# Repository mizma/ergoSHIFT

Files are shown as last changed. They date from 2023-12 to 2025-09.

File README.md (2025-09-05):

ergoSHIFT arcade controller
========================================================================



_**Low profile 11 button leverless arcade controller with Acrylic shell**_

This repository contains Acrylic cut design files, PCB design files and code needed to make
an arcade controller that look like this:

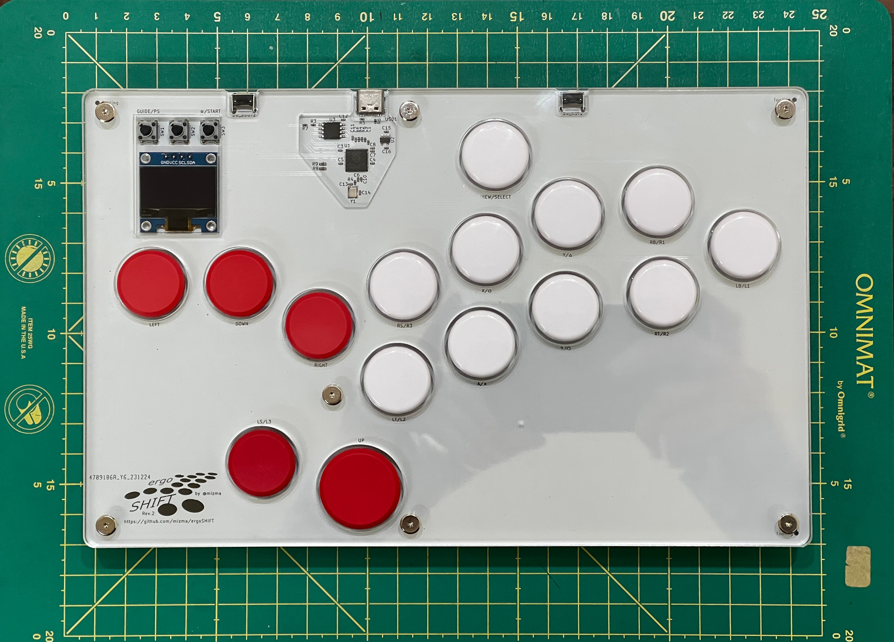
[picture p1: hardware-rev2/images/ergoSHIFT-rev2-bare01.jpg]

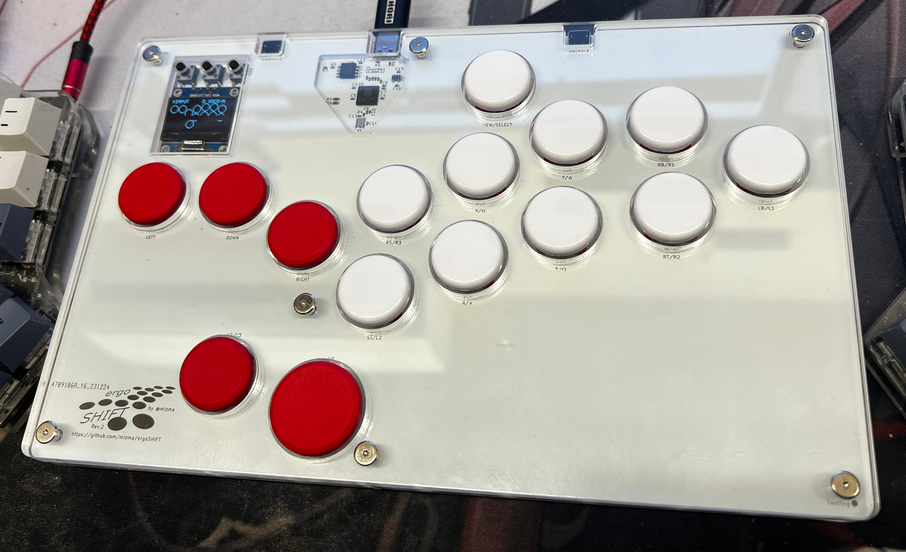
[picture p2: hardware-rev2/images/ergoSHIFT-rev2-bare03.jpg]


Also, you can create custom artwork using the stencil provided in each hardware revision folder.

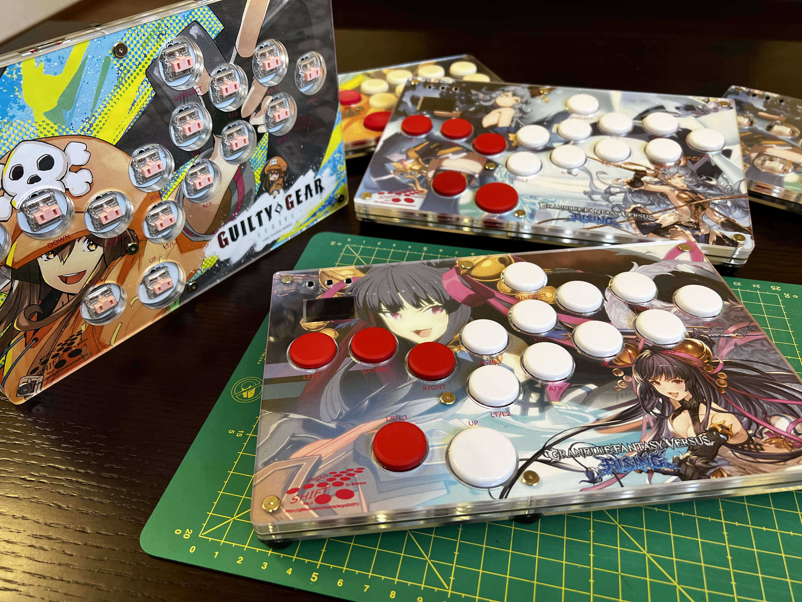
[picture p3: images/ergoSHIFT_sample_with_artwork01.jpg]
ergoSHIFT-rev1_with_artwork1

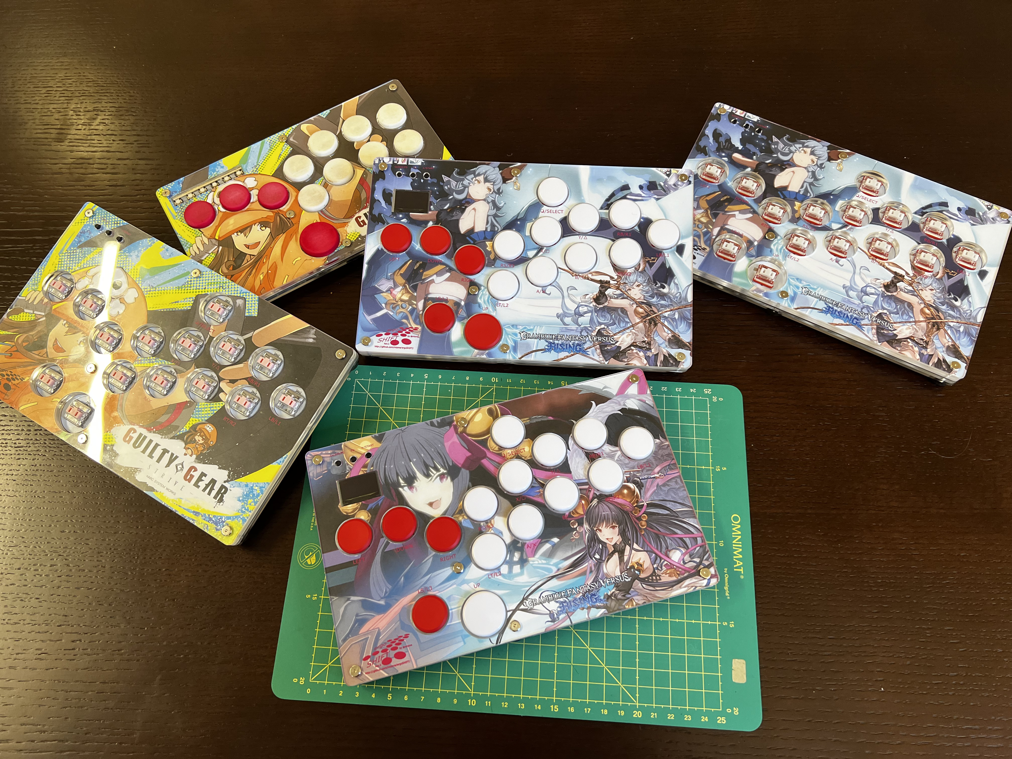
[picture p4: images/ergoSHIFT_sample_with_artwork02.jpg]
ergoSHIFT-rev1_with_artwork2


(*) Above sample Artwork based on an In-Game Screenshot + Official Fan-kit (©Cygames & ARK SYSTEM WORKS)

This controller is designed with the following concept:

* Create a reasonably compact and thin leverless arcade controller
* Layout 11 main buttons + 4 directional buttons to work with the latest
  Capcom Pro-Tour rule-set
* Shift the home position for the main button one column to the right to better utilize the
  more dextrous thumb and index finger instead of the little finger.
* Add the three additionally allowed buttons
* Make the button size compatible with Snackbox MICRO from [Junkfood Arcades](https://junkfoodarcades.com/)
    * I could not find good Injection molded options other than this one.
* Make the design reversible for southpaw use.
    * To assemble for left hand use, implement all buttons on the other side.
    * Controller Circuit (Pro Micro or RP2040) must be implemented on the same side
    * to compensate for the Controller Cicuitry being implemented in reverse, Acrylic layers will need to be
      stacked in a different order and thickness.  Refer to each revision README for details

Resulting button mappings will look like this:

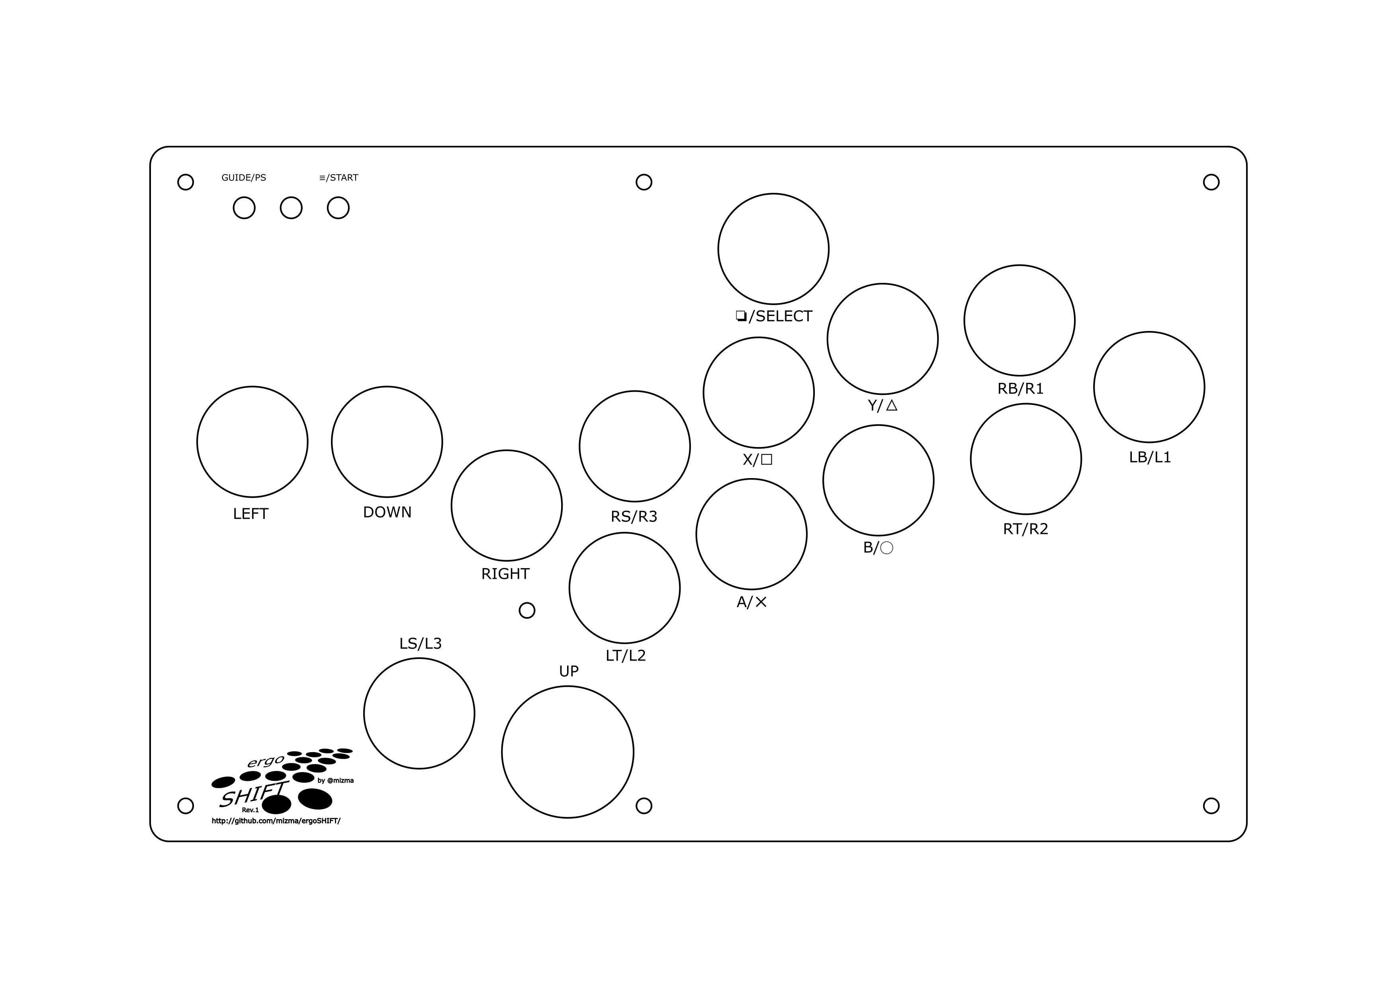
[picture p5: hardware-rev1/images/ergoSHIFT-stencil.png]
button-map

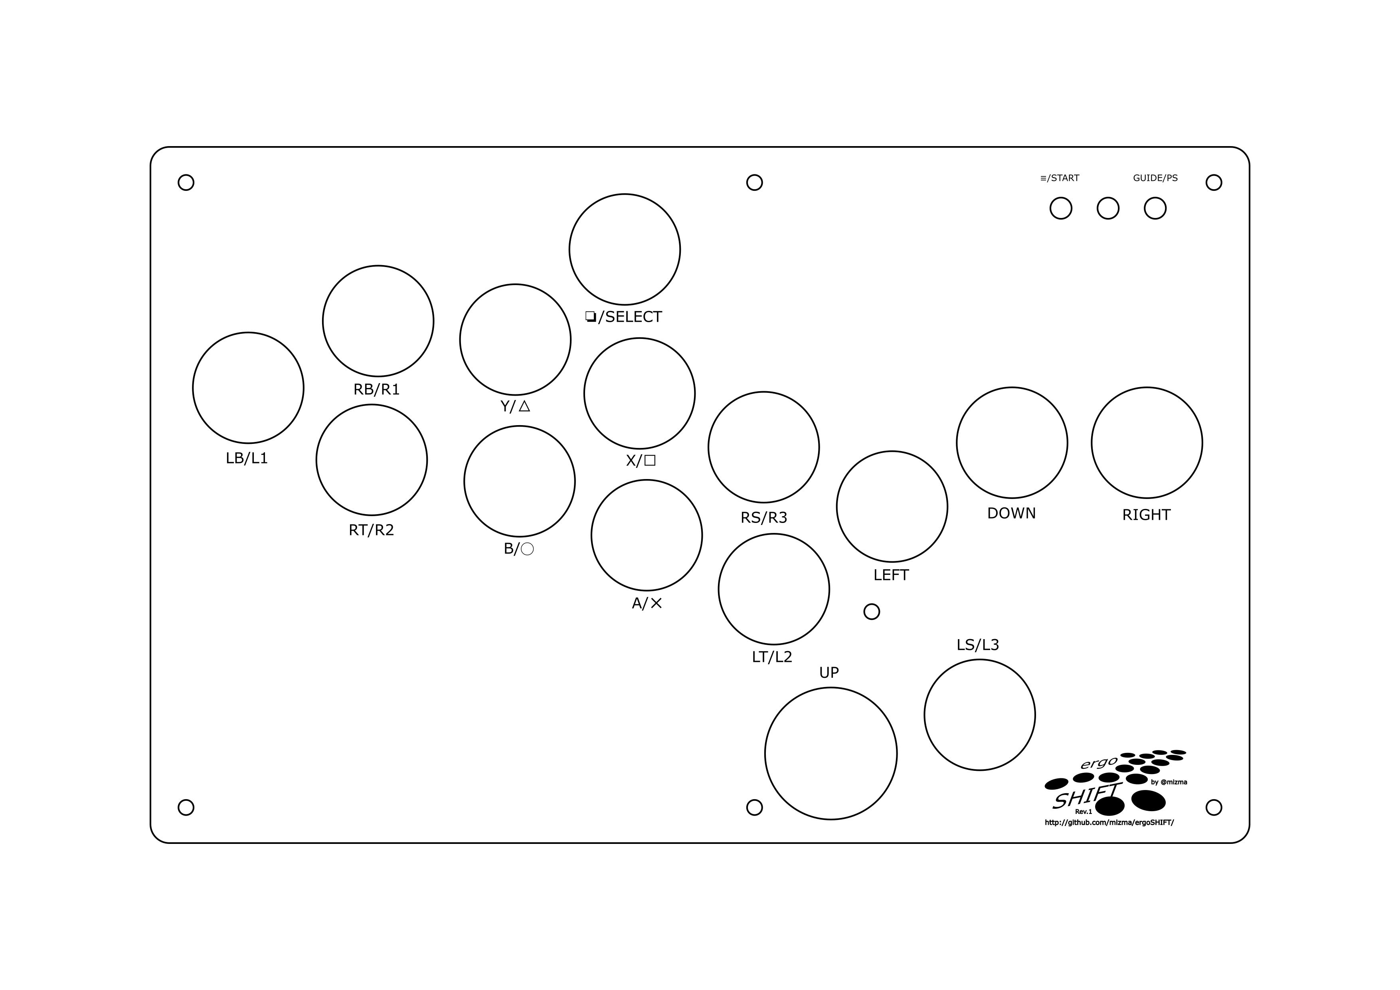
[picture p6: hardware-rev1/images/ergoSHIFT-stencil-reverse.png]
button-map-reversed


There are currently two revisions of the ergoSHIFT.  It uses Kailh low profile (choc v1)
mechanical keyboard switches.  The table below lists their main features.
See the README for each version for details on how to make them.

version                                 | [rev1](./hardware-rev1/)            | [rev2](./hardware-rev2/)              | [rgb](./hardware-rgb/)                |
--------------------------------------- | ----------------------------------- | ------------------------------------- | ------------------------------------- |
Status                                  | Verified                            | Verified                              | Verified                              |
case dimensions                         | 233.17x147.67x14.6mm (excl. feet)   | 233.17x147.67x14.6mm (excl. feet)     | 233.17x147.67x14.6mm (excl. feet)     |
compatibility (using provided firmware) | PC, PS3, Xinput, Switch             | PC, PS3, PS4*, PS5*, Xinput, Switch   | PC, PS3, PS4*, PS5*, Xinput, Switch   |
add-on board                            | Sparkfun Qwiic Pro Micro            | SSD1306, SH1106 or SH1107 128x64 oled | SSD1306, SH1106 or SH1107 128x64 oled |
onboard chip                            | -                                   | RP2040                                | RP2040                                |
port                                    | USB-C                               | USB-C                                 | USB-C                                 |
SMT assembly required                   | no                                  | yes                                   | yes                                   |
OLED Support                            | no                                  | yes                                   | yes                                   |
RGB Support                             | no                                  | no                                    | yes                                   |
South-paw support                       | yes                                 | yes                                   | no                                    |
firmware                                | [ATmega32U4](firmwares_atmega32u4)  | [GP2040-CE](https://gp2040-ce.info/)**| [GP2040-CE](https://gp2040-ce.info/)**|

*) for details, see the documentation in the [GP2040-CE Console Compatibility FAQ](https://gp2040-ce.info/faq/faq-console-compatibility/)

**) See [GP2040 firmware page](./firmware_GP2040-CE/) for firmware with ergoSHIFT specific config.

LICENSE
------------------------------------------------------------------------



ergoSHIFT (c) by mizma

ergoSHIFT is licensed under a
Creative Commons Attribution-ShareAlike 4.0 International License.

You should have received a copy of the license along with this
work. If not, see <https://creativecommons.org/licenses/by-sa/4.0/>.

Some portions of the work uses derivative works of other libraries and or implementations.
Firmware and hardware designs are separately licensed depending on the licensing terms of
the works it uses.  Refer to the LICENSE files or README for the relevant terms for each
component.

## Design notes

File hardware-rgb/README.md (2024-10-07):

ergoSHIFT rev RGB
========================================================================

This is a RGB rev of the ergoSHIFT.  In this version, RGB LEDs were added to each Kailh button and can be assembled onto the board by JLCPCB (or another fab house), similar to the other SMT parts. 

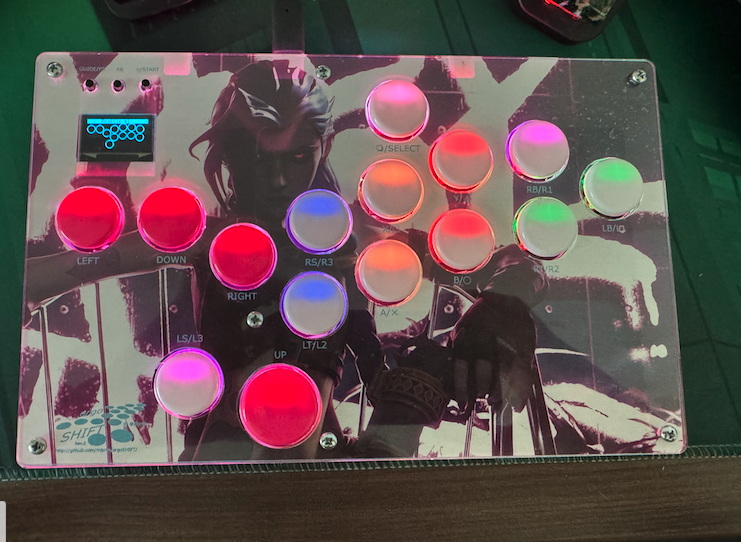
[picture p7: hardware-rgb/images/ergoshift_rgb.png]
Example image


The firmware from the [Original GP2040-CE website](https://gp2040-ce.info/downloads) will work along with enabling the RGB LED via the GP2040-CE Web Configurator.
You may also use the firmware in the [Firmware Directory](../firmware_GP2040-CE/) which support original OLED display layout.

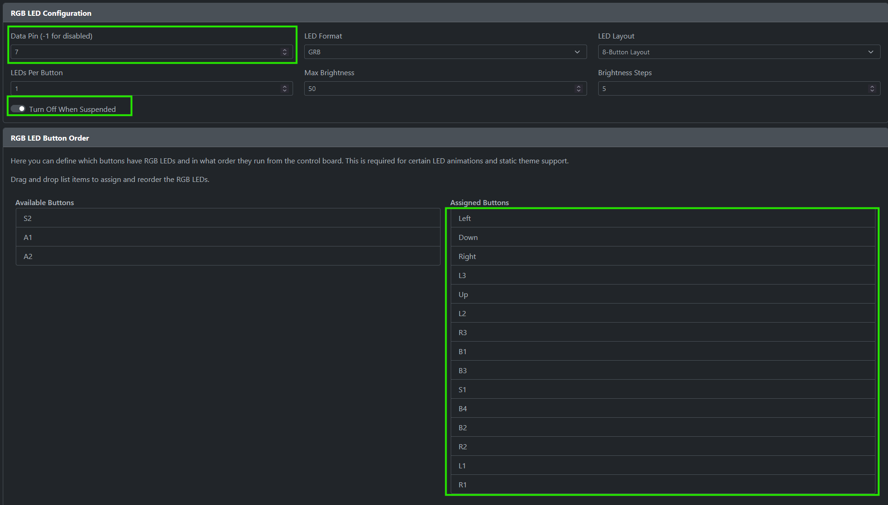
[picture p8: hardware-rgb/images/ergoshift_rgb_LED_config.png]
LED Configuration


This version of Ergoshift has been modified to only work in the standard (non Southpaw) configuration so that there is PCB area for RGB LEDs. The Kailh sockets are also required for this version (rev2 can use Kailh sockets or switches directly) and can only be installed in the normal configuration.

All other assembly steps are the same as the hardware-rev2 steps

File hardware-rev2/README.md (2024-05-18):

ergoSHIFT rev2
========================================================================

This is rev2 of the ergoSHIFT.  In this version, RP2040 circuitry is
implemented on the PCB.

To make one you will need:

* [acrylic shell](./acrylic-shell/)
    * For Standard Layout stackup (From bottom to top)
        * acryl-design-ergoSHIFT-Acrylic-layer-01: 2mm
        * acryl-design-ergoSHIFT-Acrylic-layer-02: 3mm
        * PCB
        * acryl-design-ergoSHIFT-Acrylic-layer-03: 3mm
        * acryl-design-ergoSHIFT-Acrylic-layer-04: 3mm
        * acryl-design-ergoSHIFT-Acrylic-layer-05: 2mm
    * For Reverse Layout (Left handed, from bottom to top)
        * acryl-design-ergoSHIFT-Acrylic-layer-01: 2mm
        * acryl-design-ergoSHIFT-Acrylic-layer-03: 3mm (to compensate for PCB being flipped upside down)
        * PCB
        * acryl-design-ergoSHIFT-Acrylic-layer-04: 3mm
        * acryl-design-ergoSHIFT-Acrylic-layer-04: 3mm
        * acryl-design-ergoSHIFT-Acrylic-layer-05: 2mm
* [the ergoSHIFT PCB](./pcb/)
* 15x Kailh low profile (choc v1) switches of your choice
    * I use Kailh Choc v1 Red Pro (Linear and low activation force: 35±10gf with actuation travel: 1.5±0.5mm)
    * Others like Light Blue (gChoc) or Pink can be used for even lower actuation force.
* (optionally) 15x Kailh low profile hotswap sockets
    * Can be ordered from LCSC with part number [C5333465](https://www.lcsc.com/product-detail/Mechanical-Keyboard-Shaft_Kailh-CPG135001S30_C5333465.html)
* (optionally) SSD1306 driver based 0.96 inch OLED module with PCB size aprox. 25.4mm x 26.1mm
    * You may choose to omit R8 and R9 on PCB if display is not implemented.
* Button Caps (Choose one)
    * [MICRO keycap set](https://junkfoodarcades.com/collections/micro-accessories)
        * You will need to buy two sets of Snackbox Micro keycap sets.
    * [3D printed buttoncaps](../3d-printed-buttoncaps)
* 3x 6x6x8.51mm tact switches
    * I Used [TE Connectivity 3-1825910-5](https://www.te.com/ja/product-3-1825910-5.html).  You 
      can order from LCSC with part number [C592733](https://www.lcsc.com/product-detail/Tactile-Switches_TE-Connectivity-3-1825910-5_C592733.html)
    * Digikey part number: [450-1644-ND](https://www.digikey.com/en/products/detail/te-connectivity-alcoswitch-switches/3-1825910-5/1632530)
    * Make sure the switch head is tall enough.  Otherwise, you will not be able to press the button.
* 2x 3x6x4.3 horizontal tact switch
    * https://www.newegg.com/p/2S7-01KR-035X0
    * https://shop.yushakobo.jp/collections/all-keyboard-parts/products/a1600ed-01-1
    * You can also order from LCSC with part number [C18078123](https://www.lcsc.com/product-detail/Tactile-Switches_Bossie-BX-TS-26-3643ZJ_C18078123.html)
    * MJTP1117/PHAP3363 from DigiKey should work as well [679-2400-ND](https://www.digikey.com/en/products/detail/apem-inc/MJTP1117/1795496)
    * [schematics](images/tactile-switch_3x6x4.3.jpg)
* 7x M3 screws (length 20mm)
    * Case stackup height = 14.6mm
        * Acryl stackup = 2mm * 2 + 3mm * 3 = 13mm
        * +PCB 1.6mm = 14.6mm
    * Rubber feet fastening depth
        * Rubber feet screw hole depth = 3mm (using rubber feet below.  adjust for your part)
        * +M3 nut height 2mm = 5mm
    * Rubber feet total depth = 8mm (using rubber feet below.  adjust for your part)
    * min length required for proper fastening (using rubber feet below.  adjust for your part)
        * min length = 14.6+5 = 19.6mm
    * max length without extruding out the bottom (using rubber feet below.  adjust for your part)
        * max length = 14.6+8 = 22.6mm
* 7x M3 nut and acompanying rubber feet
    * Rubber feet Tochigiya [TM-TK-15](https://www.monotaro.com/p/0933/2486/?displayId=5)
    * The position of the holes are intended for feet radius of less than 7.5mm
    * You may use any rubber feet compatible with M3 screws with following constraints:
        * diameter less than 15mm (otherwise it will extrude out the side)
        * need to be compatible with the M3 screws you chose above
            * Check threading pitch.
        * make sure the screw is long enough to be able to fasten the feet, but not
          too long it extrudes past the feet.
        * choose one with washers built in, or place one yourself.
* a soldering iron and other tools
    * something with enough power is better 
      (i.e. [Hakko FX 600](https://www.hakko.com/japan/products/hakko_fx600_set.html))
    * I recommend changing tips to D type for most Through-hole soldering, or C type if you plan to
      solder SMT as well. (default B tips are harder to use for most PCB soldering)
    * Use 320C ~ 370C temp recommended (can be changed if you know your way around)

## Assembly Instructions

### Ordering PCB

I used [JLCPCB](https://jlcpcb.com/).  Just upload the gerber files in [pcb](pcb) and keep most parameters default.
You may change PCB Qty and PCB Color if you like.  All other parameters should be kept the same.

Here are the settings I use:

* Base Material: FR-4
* Layers: 2
* Dimensions: Keep as is
* PCB Qty: select as many as you like.
* Product Type: Industrial/Consumer electronics
* Different Design: 1
* Delivery Format: Single PCB
* PCB Thickness: 1.6
* PCB Color: Choose what you like
    * JLCPCB may have some restriction on color if you wish to do PCB Assembly as well
* Silkscreen: Choose what you like
* Surface Finish: HASL(with lead)
* Outer Copper Weight: 1oz
* Via Covering: Tented
* Board Outline Tolerance: 0.2mm
* Confirm Production File: No
* Remove Order Number: Choose (No: JLC will put order number SILKSCREEN on the PCB somewhere.  Setting to Yes will remove this for a small additional cost)
* Gold Fingers: No
* Castellated Holes: No
* Edge Plating: No

#### SMT assembly

You may either order the stencil when ordering PCB and impelemnt the parts yourself, or you can select Part
assembly and use the BOM file and CPL file in [pcb](pcb).

Options Used for SMT Assembly at JLCPCB:

* PCBA Type: Economic
* Assembly Side: Top Side
* PCBA Qty: Choose
* Tooling holes: Added by Customer
* Confirm Parts Placement: Yes (This will make sure JLC will check if the parts are aligned and stop if they see any annomalies)

For Advanced Options, Keep as default.

If you select PCBA and select next, the site will ask for uploading the BOM and CPL file.
Upload the files in [pcb](pcb) folder and select Next to the Component Placements where you
should see the following:

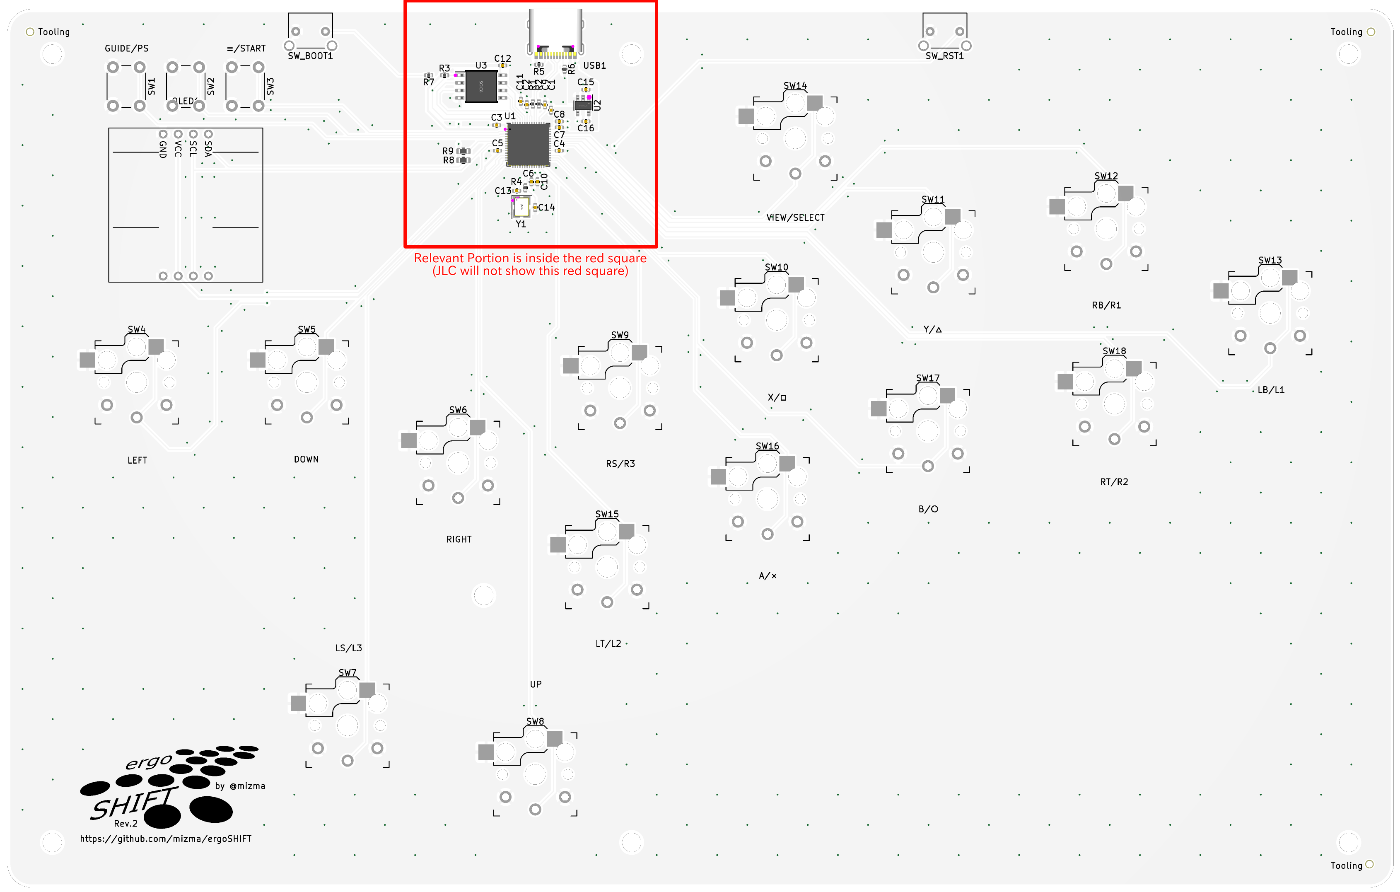
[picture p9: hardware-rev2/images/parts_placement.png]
parts placement


Check to make sure that all parts are aligned (see if components are placed as shown in image, 
and the purple dots are in the same position).  BOM and CPL file has been checked on 2024/01/06 and should
work out of the box.  If there are any anomallies, stop and ask for help in the issues (possible issues
include parts shortage, parts design revision etc. that break the BOM and CPL).

If you wish to implement the SMT parts yourself, toggle the "Order together with PCB" in the stencil section to ON.
Check for the BOM file for the actual components used.  Search on [LCSC](https://www.lcsc.com/)
with LCSC part number to figure out what parts are used.

You will need a fairly large SMT reflow oven, soldering hotplate (recommended) that can fit the PCB
or at least a soldering hot air gun.

There are some tutorials on [Hot Plate Reflowing](https://www.sparkfun.com/tutorials/59#Hot%20Plate%20Reflowing)
if you're feeling adventurous.

### Ordering or Making Buttons

#### Snackbox Micro button caps

ergoSHIFT is compatible with Snackbox Micro button caps.

You can purchase them [HERE](https://junkfoodarcades.com/collections/micro-accessories)

You will need at least two sets since ergoSHIFT has more buttons.

#### 3D printed buttons

If you have a 3D printer, print at your own will.  Files are found [here](../3d-printed-buttoncaps/).

* [ergoSHIFT-ButtonCapBig.stl](../3d-printed-buttoncaps/ergoSHIFT-ButtonCapBig.stl) 
  is used for the thumb button. 1 board needs 1 of this button.
* [ergoSHIFT-Buttoncap.stl](../3d-printed-buttoncaps/ergoSHIFT-ButtonCapBig.stl) is used for all other buttons.
  1 board needs 14 of this button.
* [ergoSHIFT-FullSetButtonCaps.stl](../3d-printed-buttoncaps/ergoSHIFT-FullSetButtonCaps.stl) is an STL file 
  containing 1 full set of buttons + extra(26 small and 2 big.).  If your 3D printing service allows 28 or more shells, it may be cheaper to print in one batch using this STL file.
    * Print size needs to be bigger than X：99.4901mm x Y： 91.7951mm x Z： 15.0000mm
    * To accomodate for the buttons in the 100mm x 100mm x 100mm size limit in some Printing services,
      This STL file has two layers of buttons arranged on top of each other.  This type of layout is only
      possible on print technology such as SLS or MJF.  Check with your 3D Printing service.
    * If your 3D Printing service does not support this type of data, use individual cap data to print.

Insertion portion may need to be adjusted in size for your 3D Printer and settings to fit snugly to the switch.
You may use some of the printer features but if that doesn't work, you might want to edit the original model.
Model data are found in [here](../3d-printed-buttoncaps/design_data/) in a [FreeCAD](https://www.freecadweb.org/)
file format.

Also, since the insertion portion requires a fairly tight tolerance which is not easily achieved by 3D printers,
the models are modelled slightly on the larger side.

I have had fairly good results with this model using SLS/MJF Nylon print but sometimes it is too large.
If the legs turn out too large to fit, use sandpaper to adjust the width/depth of the legs.  __Don't Force
the CAPS in.__  Forcing them in may cause the button to become stuck (due to stems bulging).  File
the legs slightly and retry if it doesn't go in.

#### Materials Consideration

* Nylon
    * May be a good place to start for tensile strength and good chemical stability.
    * can be pretty strong if printed using SLS process at some printing services
    * may be prone to warping.  not good for humid places.
* UV Resin
    * Also pretty strong as a material, and stronger to humidity.
    * Maybe slightly more brittle than Nylon

### Ordering Acrylic cuts

I use [Elecrow](https://www.elecrow.com/acrylic-cutting.html) to cut acrylic.

Upload the .zip file in [acrylic-shell](acrylic-shell/) to the Elecrow Acrylic cut service to order.
.zip file includes the dxf file and a drawing PDF for reference.

Use the following thickness:

* For Standard Layout stackup (From bottom to top)
    * acryl-design-ergoSHIFT-Acrylic-layer-01: 2mm
    * acryl-design-ergoSHIFT-Acrylic-layer-02: 3mm
    * PCB
    * acryl-design-ergoSHIFT-Acrylic-layer-03: 3mm
    * acryl-design-ergoSHIFT-Acrylic-layer-04: 3mm
    * acryl-design-ergoSHIFT-Acrylic-layer-05: 2mm
* For Reverse Layout (Left handed, from bottom to top)
    * acryl-design-ergoSHIFT-Acrylic-layer-01: 2mm
    * acryl-design-ergoSHIFT-Acrylic-layer-03: 3mm (to compensate for PCB being flipped upside down)
    * PCB
    * acryl-design-ergoSHIFT-Acrylic-layer-04: 3mm
    * acryl-design-ergoSHIFT-Acrylic-layer-04: 3mm
    * acryl-design-ergoSHIFT-Acrylic-layer-05: 2mm

The original design file (FreeCAD file) can be found [here](./design_data/acryl-design/).

The Acrylic should look like the following (with PCB stacked)

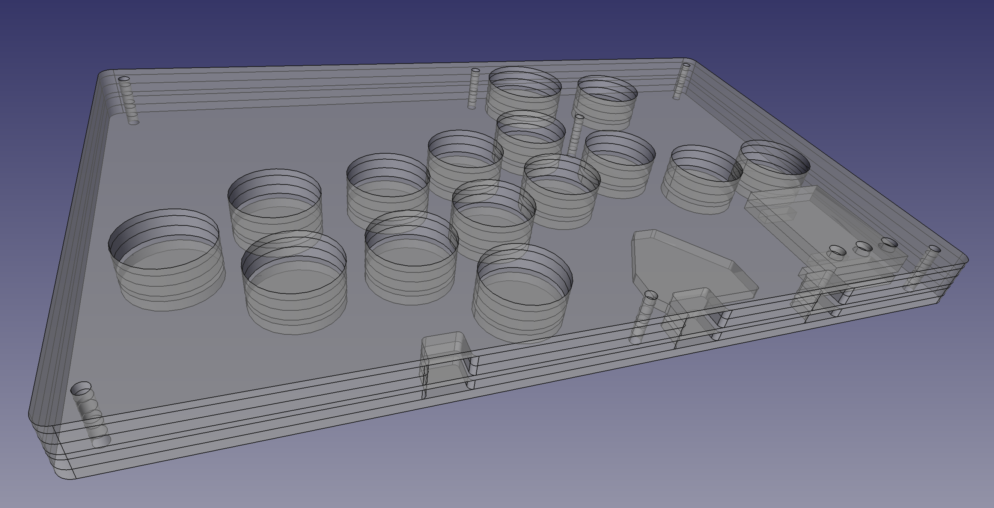
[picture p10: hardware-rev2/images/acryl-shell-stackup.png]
ergoSHIFT-rev2-Acrylic-Stack


(*) Above image is for standard layout (right handed)

### Assembly

1. Solder all the Choc v1 switches and the tactile switches.  make sure you populate the side with the other
   SMT components.
    * If you populate the side with the logo on the left, the buttons only goes in in the correct orientation.
        * For reverse layout, implement the buttons on the other side.
    * If you use the hot-swap sockets, those will go on the other side. (see silk screen on back side for
      orientation)
        * For hotswap sockets, pre-solder one side of the pad on PCB, place the socket, heat the pre-solder while
          pressing down on the socket to attach the socket.  After It is attached, solder the other side fully
          and then add more solder on the pre-soldered side.
2. Solder the OLED screen.  See the silkscreen for the orientation of the pins.
    * For standard layout, the pins should be soldered to the top 4 through-holes lining up from left to right:
      GND, VCC, SCL, SDA
    * For southpaw layout, the pins should be soldered to the bottom 4 through-holess with pins from left
      to right: SDA, SCL, VCC, GND
    * **IMPORRTANT** Tolerance consideration: When soldering the OLED screen, stack up the acrylic boards 
      with the OLED screen and PCB and make sure the OLED screen is in the final assembled position when
      soldering (see image).  The tolerance between the highest point in OLED screen and the acrylic board opening is only
      around 0.2~0.3mm and a sloppy soldering will make the front acrylic interfere with the OLED so it is hightly advised
      that the _**soldering is done in an assembled position**_.
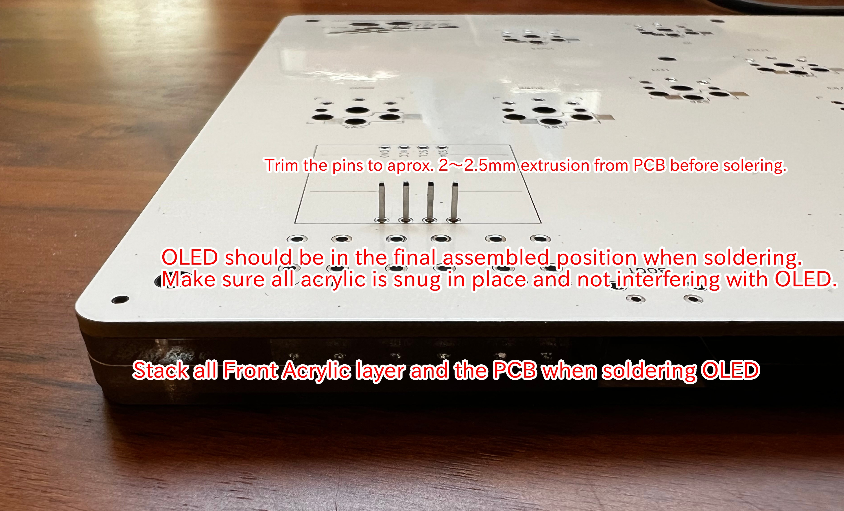
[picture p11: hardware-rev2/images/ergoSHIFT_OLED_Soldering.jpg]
ergoSHIFT OLED
        * 
3. stack the Acryl and PCB in following order: Layer 01, Layer 02, PCB, Layer 03, Layer 04 and Layer 05.
    * for reverse layout, stack in the order: Layer 01, Layer 03, PCB, Layer 04, Layer 04 and Layer 05.
    * For details on how to build southpaw version, see the [Readme_southpaw](./README_southpaw.md)
4. Screw on the M3 screws with the nut on all 7 locations.  Rubber feet should be inserted at least in the
   corners between the nut and the acrylic.
    * putting rubber feet on all positions makes shure the board does not flex during use.

It should look like the following when assembled.

ergoSHIFT-rev2 bare straight down
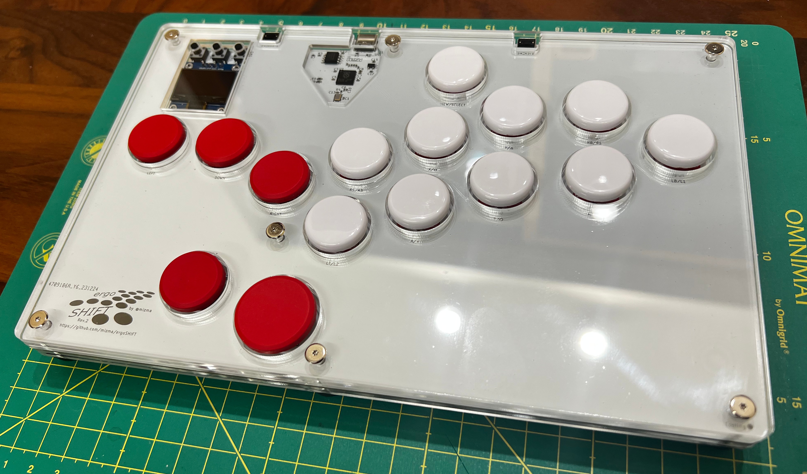
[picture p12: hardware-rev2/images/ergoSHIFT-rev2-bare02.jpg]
ergoSHIFT-rev2 bare at angle

ergoSHIFT-rev2 bare turned on

### Pro-Tip 1. Filing the Acrylic Edges

Acrylic Edges after laser cutting can be quite sharp and do not feel good.
You may want to file the edges with sandpaper (#400 is a nice place to start) to remove the edges 
on the top acrylic layer you don't cut yourself.

### Pro-Tip 2. Customizing design

You can also insert some artwork below the top acrylic layer as below:

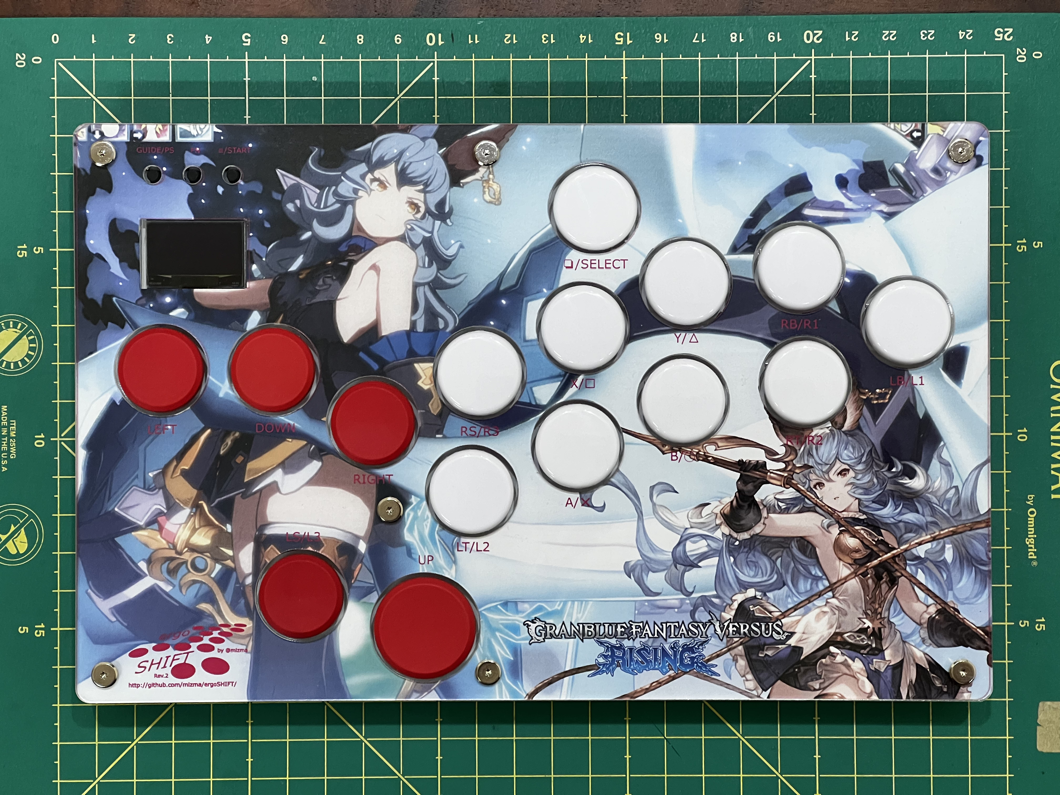
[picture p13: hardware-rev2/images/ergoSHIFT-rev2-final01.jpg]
ergoSHIFT-rev2_with_artwork1

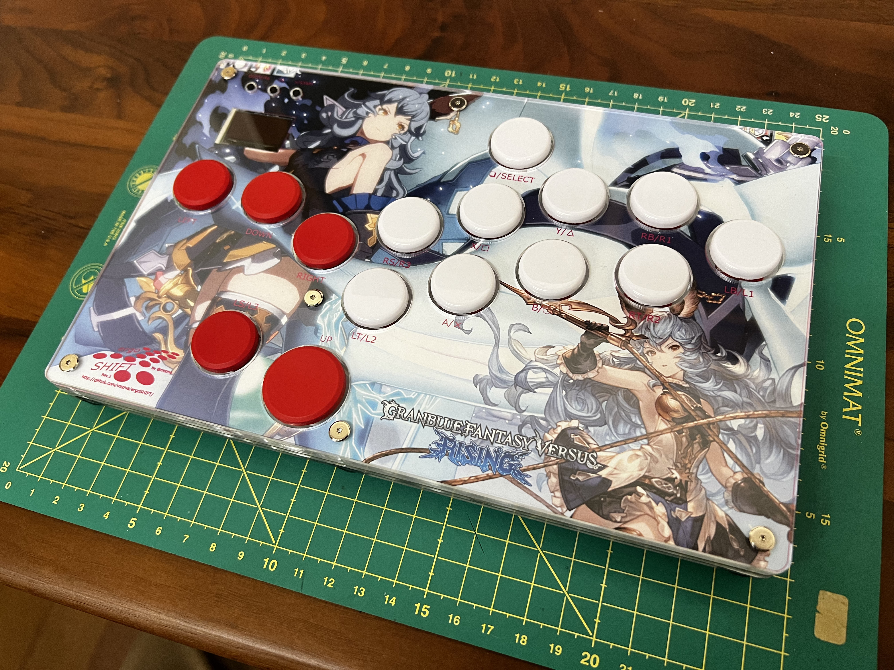
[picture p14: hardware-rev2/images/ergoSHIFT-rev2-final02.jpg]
ergoSHIFT-rev2_with_artwork1

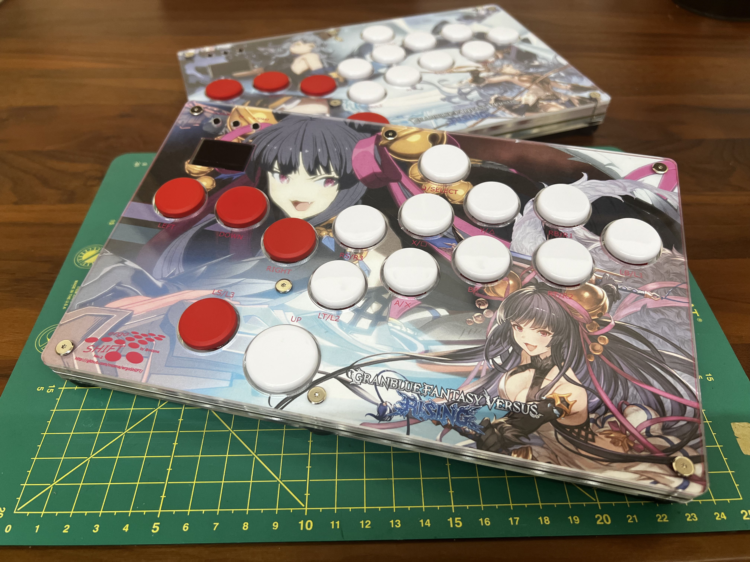
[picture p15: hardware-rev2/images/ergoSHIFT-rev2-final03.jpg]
ergoSHIFT-rev2_with_artwork2


(*) Above sample Artwork based on In-Game Screenshot + Official Fan-kit (©ARK SYSTEM WORKS)

Stencil for the artwork can be found below (Page Size set to A4):

* [Stencil SVG](./images/ergoSHIFT-stencil-with-OLED.svg)
* [Stencil PNG 300dpi](./images/ergoSHIFT-stencil-with-OLED.png)
* [Backplate Stencil SVG](./images/ergoSHIFT-backplate-stencil-with-OLED.svg)
* [Backplate Stencil PNG 300dpi](./images/ergoSHIFT-backplate-stencil-with-OLED.png)
* [Southpaw Stencil SVG](./images/ergoSHIFT-stencil-with-OLED-reversed.svg)
* [Southpaw Stencil PNG 300dpi](./images/ergoSHIFT-stencil-with-OLED-reversed.png)
* [Southpaw Backplate Stencil SVG](./images/ergoSHIFT-backplate-stencil-with-OLED-reversed.svg)
* [Southpaw Backplate Stencil PNG 300dpi](./images/ergoSHIFT-backplate-stencil-with-OLED-reversed.png)

To cut the stencil, use one of the top acrylic plates as cutting guides (don't trust the acuracy
of the printed stencil mark, they are good enough to use as design guide, but not acurate enough for 
final cutting guide).  It is easy to cut if you tape the plate on top of the print.

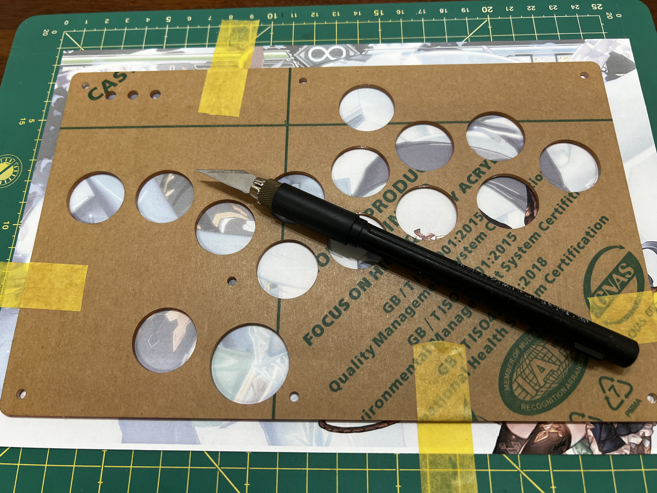
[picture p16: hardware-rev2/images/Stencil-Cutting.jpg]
Stencil-Cutting


For the OLED display portion, use Layer-04 acrylic for the sides and use the print mark for the
horizontal cuts.

## Donations

This project is completely opensource.  If you feel you would like to donate, please consider donating
to the any of the projects refered to below in the License and Acknowlegements section.

Or join the [GP2040-CE](https://gp2040-ce.info/) community project that made this project possible and
help others with similar needs.

## License and Acknowlegements



PCB design licensed under [CC BY-SA 4.0](https://creativecommons.org/licenses/by-sa/4.0/) by mizma

Acrylic sandwitching shell heavily inspired by [Mille-Feuille](https://pomegd.booth.pm/items/2685530) 
by [@pomegd](https://twitter.com/pomegd)

PCB design uses the following libraries or derivatives of the design:

* [keyswitches.pretty](https://github.com/daprice/keyswitches.pretty) by [daprice](https://github.com/daprice) ([CC BY-SA 4.0](https://creativecommons.org/licenses/by-sa/4.0/))
* [Type-C.pretty](https://github.com/ai03-2725/Type-C.pretty) by [ai03-2725](https://github.com/ai03-2725)
* RP2040 library from [Hardware design with RP2040](https://datasheets.raspberrypi.org/rp2040/hardware-design-with-rp2040.pdf) Chapter 2. Minimal design example.

Portions of the PCB layout and parts selection has been referenced from the following builds:

* [Open_Core0](https://github.com/OpenStickCommunity/Hardware/tree/main/Open_Core0) by [TheTrain](https://github.com/TheTrainGoes) ([Licensed under CC BY 4.0](https://creativecommons.org/licenses/by/4.0/))
* [flatbox rev.4](https://github.com/jfedor2/flatbox/tree/master/hardware-rev4) by [jfedor](https://github.com/jfedor2) ([licensed under CC BY-SA 4.0](https://creativecommons.org/licenses/by-sa/4.0/))

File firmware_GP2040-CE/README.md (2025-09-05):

GP2040-CE Firmware
========================================================================

ergoSHIFT rev.2
------------------------------------------------------------------------

rev.2 uses [GP2040-CE firmware](https://gp2040-ce.info/) with custom config.

### Prebuilt firmware file

You may obtain firmware with display layout enhancement by [adilahmeddev's branch](https://github.com/adilahmeddev/GP2040-CE-ERGOSHIFT-DISPLAY)
in [My fork repository releases](https://github.com/mizma/GP2040-CE/releases).

Once you have downloaded the file, connect the board to your PC,
when you see a USB thumbdrive mounted called `RPI-RP2`,
just drag and drop the firmware file. (You will need to hold down the `BOOT` button
when you connect if you already have firmware written to it)

If you don't see the `RPI-RP2`, Hold down the `BOOT` button (the side tactile
switch on the left) and press the `RST` button (the side tactile swith with
`SW_RST1` label).

### Building your own firmware

You can use my fork of [GP2040-CE repository](https://github.com/mizma/GP2040-CE) source to build firmware for ergoSHIFTRev2
or ergoSHIFTRGB.

When building, set up the GP2040_BOARDCONFIG environment variable to `ergoSHIFTRev2` for non RGB
version, or `ergoSHIFTRGB` for RGB enabled board.
For how to build the firmware, follow the instructions in the original [GP2040-CE firmware](https://gp2040-ce.info/) website.

#### Pin assignments of ergoSHIFT Rev.2

Here are the Default Pinout and Button map information.

~~~C
// Main pin mapping Configuration
//                                // ergoSHIFT Rev.2 | GP2040 | Xinput | Switch  | PS3/4/5  | Dinput | Arcade |
#define GPIO_PIN_12 GpioAction::BUTTON_PRESS_UP     // UP     | UP     | UP      | UP       | UP     | UP     |
#define GPIO_PIN_09 GpioAction::BUTTON_PRESS_DOWN   // DOWN   | DOWN   | DOWN    | DOWN     | DOWN   | DOWN   |
#define GPIO_PIN_11 GpioAction::BUTTON_PRESS_RIGHT  // RIGHT  | RIGHT  | RIGHT   | RIGHT    | RIGHT  | RIGHT  |
#define GPIO_PIN_06 GpioAction::BUTTON_PRESS_LEFT   // LEFT   | LEFT   | LEFT    | LEFT     | LEFT   | LEFT   |
#define GPIO_PIN_18 GpioAction::BUTTON_PRESS_B1     // B1     | A      | B       | Cross    | 2      | K1     |
#define GPIO_PIN_19 GpioAction::BUTTON_PRESS_B2     // B2     | B      | A       | Circle   | 3      | K2     |
#define GPIO_PIN_23 GpioAction::BUTTON_PRESS_R2     // R2     | RT     | ZR      | R2       | 8      | K3     |
#define GPIO_PIN_16 GpioAction::BUTTON_PRESS_L2     // L2     | LT     | ZL      | L2       | 7      | K4     |
#define GPIO_PIN_20 GpioAction::BUTTON_PRESS_B3     // B3     | X      | Y       | Square   | 1      | P1     |
#define GPIO_PIN_25 GpioAction::BUTTON_PRESS_B4     // B4     | Y      | X       | Triangle | 4      | P2     |
#define GPIO_PIN_26 GpioAction::BUTTON_PRESS_R1     // R1     | RB     | R       | R1       | 6      | P3     |
#define GPIO_PIN_24 GpioAction::BUTTON_PRESS_L1     // L1     | LB     | L       | L1       | 5      | P4     |
#define GPIO_PIN_27 GpioAction::BUTTON_PRESS_S1     // S1     | Back   | Minus   | Select   | 9      | Coin   |
#define GPIO_PIN_00 GpioAction::BUTTON_PRESS_S2     // S2     | Start  | Plus    | Start    | 10     | Start  |
#define GPIO_PIN_10 GpioAction::BUTTON_PRESS_L3     // L3     | LS     | LS      | L3       | 11     | LS     |
#define GPIO_PIN_17 GpioAction::BUTTON_PRESS_R3     // R3     | RS     | RS      | R3       | 12     | RS     |
#define GPIO_PIN_02 GpioAction::BUTTON_PRESS_A1     // A1     | Guide  | Home    | PS       | 13     | ~      |
#define GPIO_PIN_01 GpioAction::BUTTON_PRESS_A2     // A2     | ~      | Capture | ~        | 14     | ~      |

#define HAS_I2C_DISPLAY 1
#define I2C_SDA_PIN 4
#define I2C_SCL_PIN 5
#define I2C_BLOCK i2c0
#define I2C_SPEED 400000
#define DISPLAY_FLIP 0      // set to 1 for southpaw
#define DISPLAY_INVERT 0

#define BUTTON_LAYOUT BUTTON_LAYOUT_STICKLESS
#define BUTTON_LAYOUT_RIGHT BUTTON_LAYOUT_STICKLESSB
#define SPLASH_MODE SPLASH_MODE_STATIC
#define SPLASH_CHOICE SPLASH_CHOICE_MAIN
#define SPLASH_DURATION 7500
~~~

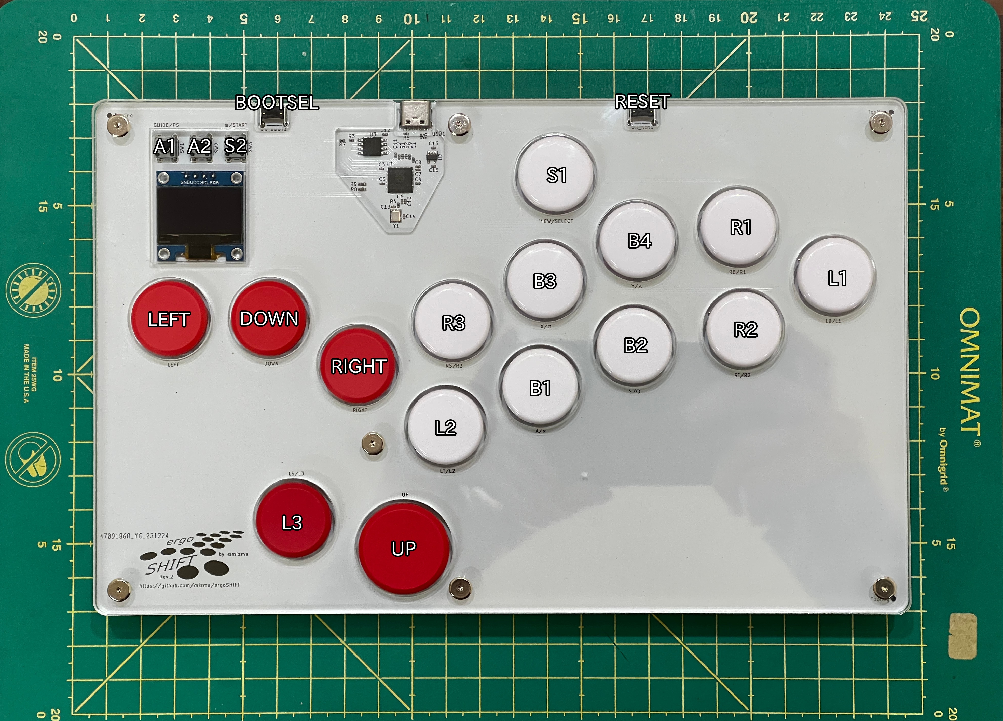
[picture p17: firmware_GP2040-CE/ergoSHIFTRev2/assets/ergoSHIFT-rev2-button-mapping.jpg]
Button Map


### Setting for southpaw

You will need to change the Pin mapping and a few settings on the OLED Screen.
Using the Web Config is the easiest route.

* To enter Web Config, connect your board to a PC and press `RESET` while holding down `S2`
* Use a browser to access http://192.168.7.1/
    * If your Wifi, LAN or any other network is configured to use 192.168.7.* address,
      you may need to disconnect you Wifi/LAN while you configure your board.
* In the Configuration -> Pin Mapping change the following
    * Set PIN06 to `Right`
    * Set PIN11 to `Left`
* In the Configuration -> Display Configuration
    * Set Flip Display to `Flip and Mirror`

### Resetting firmware

If you have some issues with you firmware, you may want to reset the flash
memory first by dragging and dropping the [flash_nuke.uf2](./flash_nuke.uf2)
to the `RPI-RP2` and wait patiently until the `RPI-RP2` reconnects

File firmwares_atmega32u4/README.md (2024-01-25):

# ATMEGA32U4 Firmwares

[日本語はこちら](README_ja.md)

There are currently two firmwares that is customized to work with ATMEGA32U4 5V AVR version of the ergoSHIFT board (3.3V board are not supported).

Both controllers should work similarly in terms of SOCD cleaning configuration and Up/Down inversion configuration.

Firmware            | [DINPUT](DINPUT)      | [LUFA](LUFA)          |
------------------- | :-------------------: | :-------------------: |
DInput              | **YES**               | NO                    |
XInput              | NO                    | **YES**               |
PS3                 | **YES**               | NO                    |
Switch              | NO                    | **YES**               |
SOCD                | Hitbox,Gafro,NEUTRAL  | Hitbox,Gafro,NEUTRAL  |
Vertical Inversion  | **YES**               | **YES**               |
DPAD emulation      | **YES**               | **YES**               |
Fake Left Stick     | NO                    | **YES**               |
Fake Right Stick    | NO                    | **YES**               |

## Configuration

All following settings are persistent and will be kept over power cycles or resets.

| Firmware | | DINPUT | LUFA |
| :--- | :---: | :---: | :---: |
| Up/Down Inversion | Normal | Down + Reset | Down + Reset |
| | Invert | Up + Reset | Up + Reset |
| SOCD Cleaning | Hitbox mode | R3(RS) + Reset | R3(RS) + Reset |
| | Gafro Mode | L3(LS) + Reset | L3(LS) + Reset |
| | Neutral Mode | PS(HOME) + Reset  | PS(HOME) + Reset |
| Change Input Mode | Xinput | Not Supported | "Start" + Reset |
| | Switch | Not Supported | "Select" + Reset |
| | DInput/PS3 | Default | Not Supported |
| Direction Mode | DPAD | Default | UP+START+SELECT |
| | Left Analog Stick | Not Supported | LEFT+START+SELECT |
| | Right Analog Stick | Not Supported | RIGHT+START+SELECT |

For Key Combos using Reset, Reset should be clicked once while holding the other input.
Wait for the controller to reset and connect to the PC/Console before releasing the input.

You can print [this cheat sheet](ergoSHIFT_Hotkey_Cheatsheet.pdf) to insert in the back
of your ergoSHIFT (PageSize: B5)

## [DINPUT](./DINPUT/)

This firmware is based on the original Flatbox firmware and is configured to work as Dinput device.
Simple firmware to work on if you only need Dinput support or want to connect it to PS3 
(Should work as PC Dinput and PS3 controller).

## [LUFA](./LUFA/)

This firmware is based on the [LUFAHybridFightstick](https://github.com/CrazyRedMachine/LUFAHybridFightstick) by [CrazyRedMachine](https://github.com/CrazyRedMachine)
and supports XInput mode and Switch controller mode (gets detected as Pokken Controller).

This firmware can be switched between Xinput (consoles not supported, only PCs) mode and Switch controller mode.

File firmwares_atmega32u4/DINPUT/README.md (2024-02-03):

[日本語はこちら](README_ja.md)

This is Arduino code for a USB arcade controller, meant to be used with ATmega32U4-based boards like the Arduino Pro Micro.
This firmware is based off of [jfedor2/flatbox](https://github.com/jfedor2/flatbox/) ATmega32u4 firmware.

It works with ergoSHIFT [rev1](../hardware-rev1)

## Change Points from [original](https://github.com/jfedor2/flatbox/blob/master/firmware-atmega32u4)

* Implemented SOCD Cleaner with selection of Hitbox style and Gafro-Controller style cleaning
    * Hold R3 when connecting to set to Hitbox Style SOCD Cleaner
    * Hold L3 when connecting to set to Gafro-controller style SOCD Cleaner
    * Hold PS when connecting to set to All Neutral SOCD Cleaner
    * Settings are saved in EEPROM so it will not change after power cycle
* Implement Up/Down Inversion (for playing normal arcade games)
    * Hold DOWN to set to Hitbox style
    * Hold UP to invert Up and Down buttons.
    * Settings are saved in EEPROM

## Building Instructions

- Download Arduino IDE, 
- Add `https://raw.githubusercontent.com/sparkfun/Arduino_Boards/master/IDE_Board_Manager/package_sparkfun_index.json` as an Additional Board Manager URL (in `File -> Preferences` menu)
- Install SparkFun AVR Boards from the Board Manager
- Select SparkFun Pro Micro (SparkFun AVR Boards) as your board type and select ATmega32U4 (5V, 16MHz) as your processor.
- Upload the code and Have Fun

### Pinout

Configurable in the .ino

The key config is already setup to match ergoSHIFT wiring.

```C
#define PIN_UP        7
#define PIN_DOWN      4
#define PIN_LEFT      3
#define PIN_RIGHT     5
#define PIN_CROSS     10
#define PIN_CIRCLE    14
#define PIN_TRIANGLE  15
#define PIN_SQUARE    16
#define PIN_L1        21
#define PIN_L2        8
#define PIN_R1        20
#define PIN_R2        19
#define PIN_SELECT    18
#define PIN_START     2
#define PIN_L3        6
#define PIN_R3        9
#define PIN_PS        1
```

For southpaw version, swap the PIN_LEFT and PIN_RIGHT definition and recompile.

```C
#define PIN_UP        7
#define PIN_DOWN      4
#define PIN_LEFT      5
#define PIN_RIGHT     3
#define PIN_CROSS     10
#define PIN_CIRCLE    14
#define PIN_TRIANGLE  15
#define PIN_SQUARE    16
#define PIN_L1        21
#define PIN_L2        8
#define PIN_R1        20
#define PIN_R2        19
#define PIN_SELECT    18
#define PIN_START     2
#define PIN_L3        6
#define PIN_R3        9
#define PIN_PS        1
```

### How to upload

When you reflash AVR boards with USB HID device software, Arduino IDE cannot automatically reset and flash the software.
You will need to press reset button on the AVR board (SW_RST1 on ergoSHIFT) to put it into Bootloader mode to reflash.
When you use Sparkfun Qwiik ProMicro 5V, you will need to double-click the reset button to put it into Bootloader.

I recommend setting up VSCode Arduino plugin.  If you open this directory with VSCode, it is already set up so all you need to do is
run Arduino: Verify from the command pallet (You will still need to install Arduino, Bounce Library and add the LUFA board manager URL before you can run verify).
The .hex file will be created in the Build folder.

Take the .hex file and use [QMK Toolbox](https://github.com/qmk/qmk_toolbox) to flash the .hex file.

In QMK Toolbox, Press OPEN and select the .hex file you just created, (or just use the one in the repository).  Select ATMega32U4 from the dropdown menu at the top right corner.
Click the Reset button on the Pro-Micro (Double-Click on Qwiik ProMicro USB-C variant).  When you see the "Caterina device connected (usbser): ~~~" text, press Flash button.

This method, while requires extra software setups, is more reliable than trying to time the Reset while Arduino IDE is doing it's thing...

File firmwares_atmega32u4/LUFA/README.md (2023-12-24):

[日本語はこちら](README_ja.md)

## LUFA Switch/XInput hybrid Fightstick firmware

This firmware is a derivative of the awesome [LUFAHybridFightstick](https://github.com/CrazyRedMachine/LUFAHybridFightstick) by [CrazyRedMachine](https://github.com/CrazyRedMachine)

## Acknowledgments

This work is a fork of [LUFAHybridFightstick](https://github.com/CrazyRedMachine/LUFAHybridFightstick) by [CrazyRedMachine](https://github.com/CrazyRedMachine) and
is based on [fluffymadness' ATMega32U4-Switch-Fightstick](https://github.com/fluffymadness/ATMega32U4-Switch-Fightstick)
and [bootsector's XInputPadMicro](https://github.com/bootsector/XInputPadMicro), with a QoL features added by CrazyRedMachine.

This fork is customized for the needs of ergoSHIFT features

* Remapped keys to work with ergoSHIFT layout
* Removed support for analog stick
* reorganized the customization button settings for SOCD and other features
    * SOCD config is now only at startup and only provide three common modes (All Neutral, Hitbox and Gafro)
    * Added feature to configure vertical input inversion.  Useful when using Hitbox layout on non-fighting games.

## Features

### Gamepad modes

Hold "select" as you plug the controller to make it a Nintendo Switch controller.

Hold "start" as you plug the controller to make it an XInput controller.

Gamepad mode is persistent across plugging and unplugging the controller, so if you don't press anything while plugging the controller, it will stay in the last used mode. 

### DPAD modes

You can switch seamlessly between the 3 stick modes by pressing START+SELECT+(LEFT/UP/RIGHT)

- UP: DPAD 
- LEFT: Fake Left Analog (DPad is mapped to L-Analog)
- RIGHT: Fake Right Analog (DPad is mapped to R-Analog)

DPAD mode is also persistent.

### Real analog support

This function has been removed since ergoSHIFT has no plans of adding analog inputs

### Simulated home button

This is also removed since we have custom hardware that support home buttons

### SOCD Cleaning

* HOME at startup = All NEUTRAL
* RS at startup = Hitbox style SOCD cleaning (Up+Down=Up, Left+Right=Neutral)
* LS at startup = Gafro style SOCD cleaning (Up+Down=Up, Left+Right=Last Input)

You can use the Reset button on the ergoSHIFT while holding the buttons above to change mode.

### UP-DOWN inverse

Since ergoSHIFT is a Hitbox style controller, Up and Down button layout is a little convoluted for normal use outside its fighting game use-case.
I have added inverting the UP/DOWN input as a feature so the controller can be used a little easier on normal games... (although it still feels a little unweildy TBH.)

* To invert UP and DOWN inputs, press UP at startup.
* To set to normal mode, press DOWN at startup.

## Building Instructions

- Download Arduino IDE, 
- Download the Bounce2 Library inside the Arduino IDE
- Add `https://github.com/CrazyRedMachine/Arduino-Lufa/raw/master/package_arduino-lufa_index.json` as an Additional Board Manager URL (in `File -> Preferences` menu)
- Install LUFA AVR Boards from the Board Manager
- Select Arduino Leonardo (LUFA) as your board type (Pro-Micro is a compatible board to Leonardo)
- Upload the code and Have Fun

### How to upload

When you reflash AVR boards with USB HID device software, Arduino IDE cannot automatically reset and flash the software.
You will need to press reset button on the AVR board (SW_RST1 on ergoSHIFT) to put it into Bootloader mode to reflash.
When you use Sparkfun Qwiik ProMicro 5V, you will need to double-click the reset button to put it into Bootloader.

I recommend setting up VSCode Arduino plugin.  If you open this directory with VSCode, it is already set up so all you need to do is
run Arduino: Verify from the command pallet (You will still need to install Arduino, Bounce Library and add the LUFA board manager URL before you can run verify).
The .hex file will be created in the Build folder.

Take the .hex file and use [QMK Toolbox](https://github.com/qmk/qmk_toolbox) to flash the .hex file.

In QMK Toolbox, Press OPEN and select the .hex file you just created, (or just use the one in the repository).  Select ATMega32U4 from the dropdown menu at the top right corner.
Click the Reset button on the Pro-Micro (Double-Click on Qwiik ProMicro USB-C variant).  When you see the "Caterina device connected (usbser): ~~~" text, press Flash button.

This method, while requires extra software setups, is more reliable than trying to time the Reset while Arduino IDE is doing it's thing...

## Pinout

Configurable in the .ino

The key config is already setup to match ergoSHIFT wiring.

```C
/* PINOUT (follows Nintendo naming (X=up, B=down)) */
#define PIN_UP    7
#define PIN_DOWN  4
#define PIN_LEFT  3
#define PIN_RIGHT 5
#define PIN_A     MISO         //XBOX B
#define PIN_B     10           //XBOX A  
#define PIN_X     15           //XBOX Y
#define PIN_Y     MOSI         //XBOX X     
#define PIN_L     21           //XBOX LB
#define PIN_R     20           //XBOX RB
#define PIN_ZL    8            //XBOX LT
#define PIN_ZR    19           //XBOX RT
#define PIN_LS    6            //XBOX LS (left analog click)
#define PIN_RS    9            //XBOX RS (right analog click)
#define PIN_PLUS  2            //XBOX START
#define PIN_MINUS 18           //XBOX BACK
#define PIN_HOME  1
```

For southpaw version, swap the PIN_LEFT and PIN_RIGHT definition and recompile.

```C
/* PINOUT (follows Nintendo naming (X=up, B=down)) */
#define PIN_UP    7
#define PIN_DOWN  4
#define PIN_LEFT  5
#define PIN_RIGHT 3
#define PIN_A     MISO         //XBOX B
#define PIN_B     10           //XBOX A  
#define PIN_X     15           //XBOX Y
#define PIN_Y     MOSI         //XBOX X     
#define PIN_L     21           //XBOX LB
#define PIN_R     20           //XBOX RB
#define PIN_ZL    8            //XBOX LT
#define PIN_ZR    19           //XBOX RT
#define PIN_LS    6            //XBOX LS (left analog click)
#define PIN_RS    9            //XBOX RS (right analog click)
#define PIN_PLUS  2            //XBOX START
#define PIN_MINUS 18           //XBOX BACK
#define PIN_HOME  1
```

## Donation

If this project helped you, please consider going to the original works and donate to the source work ;)

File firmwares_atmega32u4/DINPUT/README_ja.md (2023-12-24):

こちらのファームはArduino Pro Micro 等のATMega32u4ベースの制御基盤で利用するためのファームになります。
こちらのファームウェアは[jfedor2/flatbox](https://github.com/jfedor2/flatbox/) のATMega32u4用ファームウェアをベースに作成されています。

ergoSHIFT [rev1](../hardware-rev1) に利用できます。

## [オリジナル](https://github.com/jfedor2/flatbox/blob/master/firmware-atmega32u4)からの変化点

* SOCDクリーナー設定機能の追加（ヒットボックスモード、ガフロコンモード、全ニュートラルモード対応）
    * 接続時／リセット時にR3を押すとHitbox風SOCDクリーナーになります
    * 接続時／リセット時にL3を押すとガフロコン風SOCDクリーナーになります
    * 接続時／リセット時にPSを押すと全ニュートラルモードになります。
    * 設定はEEPROMに保存され電源を切っても保持されます。
* 上下反転モード機能の追加（格ゲー以外のゲーム用）
    * 接続時／リセット時にDOWNキーを押すとヒットボックス風のレイアウトになります
    * 接続時／リセット時にUPキーを押すと上下キー反転になります。
    * 設定はEEPROMに保存され電源を切っても保持されます。

## ファームウェアビルド手順

1. [Arduino IDE](https://www.arduino.cc/en/software)をダウンロードしてインストールしてください。
2. Arduino IDE内のライブラリ管理メニューからBounce2ライブラリをインストールしてください。
3. ファイル→環境設定から追加のボードマネージャURLに
   `https://raw.githubusercontent.com/sparkfun/Arduino_Boards/master/IDE_Board_Manager/package_sparkfun_index.json` を追加。
4. ツール→ボード→ボードマネージャから SparkFun AVR Boards をインストール
5. ツール→ボード以下で SparkFun Pro Micro (SparkFun AVR Boards) を選択
    * Processor として ATmega32U4 (5V, 16MHz) を選択
6. マイコンボードに書き込みで書き込み出来ます。
    * 初回の書き込みは特に何もしなくても上記設定をして付属の.inoを書き込めば書き込めますが2度め以降は
      書き込み出来ません。これはHIDモードで動作するファームはArduino IDEからのリセット要求に対応できない
      ためです。2回め以降の書き込みを行う場合は Arduino IDE で書き込みボタンを押してからログで
      PORTS {} / {} => {} といったような内容が出力され始めた段階でリセットボタンを押下（Pro-Micro Qwiic
      の場合はリセットボタンをダブルクリック）することで書き込みが出来ます。
    * 上記ログを表示するためには Arduino IDE の環境設定で「より詳細な情報を表示する」にチェックを入れると
      出ます
    * タイミングが難しい場合は以下に記載している .hex ファイルを取り出して QMK Toolbox で書き込みする方法も
      あります。

### ピン配置

.ino ファイルで設定可能です。

こちらのリポジトリ内のファイルではすでに ergoSHIFT 向けに設定済みです。

```C
#define PIN_UP        7
#define PIN_DOWN      4
#define PIN_LEFT      3
#define PIN_RIGHT     5
#define PIN_CROSS     10
#define PIN_CIRCLE    14
#define PIN_TRIANGLE  15
#define PIN_SQUARE    16
#define PIN_L1        21
#define PIN_L2        8
#define PIN_R1        20
#define PIN_R2        19
#define PIN_SELECT    18
#define PIN_START     2
#define PIN_L3        6
#define PIN_R3        9
#define PIN_PS        1
```

左利きバージョン（左右反転版）の場合は PIN_LEFT と PIN_RIGHT の定義を入れ替えてください。

```C
#define PIN_UP        7
#define PIN_DOWN      4
#define PIN_LEFT      5
#define PIN_RIGHT     3
#define PIN_CROSS     10
#define PIN_CIRCLE    14
#define PIN_TRIANGLE  15
#define PIN_SQUARE    16
#define PIN_L1        21
#define PIN_L2        8
#define PIN_R1        20
#define PIN_R2        19
#define PIN_SELECT    18
#define PIN_START     2
#define PIN_L3        6
#define PIN_R3        9
#define PIN_PS        1
```

### ファームの書き込み方法

USB HID対応のファームをAVRボードに書き込みすると、Arduino IDEから書き込み時の自動リセットを受け付けなくなります。
一度ファームを書き込んだ後は書き込み処理時に手動でリセット（ergoSHIFTではSW_RST1）を押す必要があります。
Sparkfun Qwiic Pro Micro 5Vを使った場合はリセットをダブルクリックすることで書き込みモードに入れることが出来ます。

Arduino IDEでは自分で書き込みのタイミングを制御出来ないため、2回目以降はVSCodeのArduinoプラグインを使って
コンパイルだけ行い、.hex ファイルを取り出して [QMK Toolbox](https://github.com/qmk/qmk_toolbox)を利用して
書き込む方法がおすすめです。
VSCodeは[こちら](https://azure.microsoft.com/ja-jp/products/visual-studio-code/)からダウンロードできます。
インストールが終わったらプラグインからArduinoを検索しマイクロソフト製のArduinoプラグインをインストール。
Arduino IDEで上記の設定が一通り終わった後にこのフォルダをVSCodeで開くことでVSCodeからのコンパイルが可能です。
.inoファイルを開いてVSCodeのコマンドパレットから Arduino: Verify を選択するとコンパイルされ、buildフォルダに
.hexファイルが生成されます。

.hexファイルは[QMK Toolbox](https://github.com/qmk/qmk_toolbox)を使って書き込みが出来ます

1. QMK Toolboxを起動したら、右上のOPENから上記で作成した.hexファイルを選択してください。
2. 右上のドロップダウンから ATMega32u4を選択してください
3. Pro Micro のリセットボタンを押し（Qwiic Pro Micro USB-Cの場合はリセットをダブルクリックし）、QMK Toolbox
   のログ上に黄色の文字で"Caterina device connected (usbser): ~~~"と出たら右上のFlashボタンを押下すると
   書き込みが開始されます。書き込み完了後に自動でボードがリセットされ新しいファームで立ち上がります。

こちらの方法は追加のソフトのセットアップが必要ですが、コンパイルと書き込みを分けて行えるため、リセットのタイミング
が図りやすいため失敗し辛い為おすすめです（ただし初回書き込みはArduino IDEでないとうまくいかない事があったため、
新品のPro Microを書き込む場合はArduino IDEで行う事をおすすめします）

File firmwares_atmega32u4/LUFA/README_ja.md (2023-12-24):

## LUFA Switch/XInput ハイブリッドアケコンファームウェア

このファームウェアは[CrazyRedMachine](https://github.com/CrazyRedMachine)様による
[LUFAHybridFightstick](https://github.com/CrazyRedMachine/LUFAHybridFightstick)のergoSHIFT向け改造版になります。

## 謝辞 

このファームは[CrazyRedMachine](https://github.com/CrazyRedMachine)様による
[LUFAHybridFightstick](https://github.com/CrazyRedMachine/LUFAHybridFightstick)のフォークで、
[fluffymadness' ATMega32U4-Switch-Fightstick](https://github.com/fluffymadness/ATMega32U4-Switch-Fightstick)
と [bootsector's XInputPadMicro](https://github.com/bootsector/XInputPadMicro)をベースに作成されています。

このフォークではergoSHIFTに対応するため、以下の修正を入れています。

* ergoSHIFT の配線に合わせたキーマップの修正
* アナログスティック対応コードの削除
* 設定関連（SOCDクリーナー設定等）のボタンを他のergoSHIFTと合わせるためマッピング変更
    * SOCDクリーナー設定は起動時のみに変更し、プリセットの選択のみとしました
      （全ニュートラル、Hitbox風、ガフロコン風）
    * 追加で上下キーの反転機能を追加。格ゲー以外のゲームでの利用向け。

## 機能

### ゲームパッドモード設定

起動時（USB接続時もしくはリセットボタン短押し時）に ”Select” を押したまま起動することで
ニンテンドースイッチコントローラーとして動作します。

起動時（USB接続時もしくはリセットボタン短押し時）に ”Start” を押したまま起動することで
XInputコントローラーとして動作します。

ゲームパッドモードは保持されるため、コントローラーの切断時でも保持されます。起動時に何も押さなければ
以前設定したモードで動作します。

### 方向キー設定

方向キーのモードは動作中に動的に切り替えが可能です。START+SELECT+(←／↑／→) のキーコンボで設定できます。

* ↑： 十字キーとして動作
* ←： 疑似左アナログスティックとして動作（十字キーを左アナログスティックとしてマッピング）
* →： 疑似右アナログスティックとして動作（十字キーを右アナログスティックとしてマッピング）

方向キーモード設定も電源オフでも保持されます。

以下にある上限反転をしている場合は上下反転された状態での↑を利用してください。

### アナログ入力サポート機能

ergoSHIFTにはアナログ入力がないため機能削除しました。

### ホームボタンシミュレート機能

ergoSHIFTにはHomeボタンがあるため機能削除しました。

### SOCD クリーナー設定

* 起動時にHOME(PS)押下＝全ニュートラル
* 起動時にR3(RS)押下＝ヒットボックス風SOCDクリーナー（↑＋↓＝↑、←＋→＝ニュートラル）
    * 一部公式大会等でも許可されたモードです（大会毎にルールが違う可能性があるためルール確認のこと）
* 起動時にL3(LS)押下＝ガフロコン風SOCDクリーナー（↑＋↓＝↑、←＋→＝後勝ち）
    * 一部公式大会等では禁止されているモードです。

起動時設定なので、USB接続時か、リセットボタンを使うことで設定可能です。

### 上下入力反転設定

ergoSHIFTはHitbox風コントローラーのため、上下キーのレイアウトが少々変わっているため、格ゲー以外では
利用しづらい為、格ゲー以外で利用するときのために上下反転する機能を追加しました。

* 起動時に上ボタン（十字キーの親指のボタン）を押下＝上下反転
* 起動時に下ボタン（十字キーの真ん中のボタン）を押下＝反転解除

## ファームウェアビルド手順

1. [Arduino IDE](https://www.arduino.cc/en/software)をダウンロードしてインストールしてください。
2. Arduino IDE内のライブラリ管理メニューからBounce2ライブラリをインストールしてください。
3. ファイル→環境設定から追加のボードマネージャURLに
   `https://github.com/CrazyRedMachine/Arduino-Lufa/raw/master/package_arduino-lufa_index.json` を追加。
4. ツール→ボード→ボードマネージャからLUFA AVR Boardをインストール
5. ツール→ボード以下で Arduino Leonardo (LUFA) を選択
    * Pro-MicroはArduino Leonardoの互換ボードなのでこちらで動作します
6. マイコンボードに書き込みで書き込み出来ます。
    * 初回の書き込みは特に何もしなくても上記設定をして付属の.inoを書き込めば書き込めますが2度め以降は
      書き込み出来ません。これはHIDモードで動作するファームはArduino IDEからのリセット要求に対応できない
      ためです。2回め以降の書き込みを行う場合は Arduino IDE で書き込みボタンを押してからログで
      PORTS {} / {} => {} といったような内容が出力され始めた段階でリセットボタンを押下（Pro-Micro Qwiic
      の場合はリセットボタンをダブルクリック）することで書き込みが出来ます。
    * 上記ログを表示するためには Arduino IDE の環境設定で「より詳細な情報を表示する」にチェックを入れると
      出ます
    * タイミングが難しい場合は以下に記載している .hex ファイルを取り出して QMK Toolbox で書き込みする方法も
      あります。

### ファームの書き込み方法

USB HID対応のファームをAVRボードに書き込みすると、Arduino IDEから書き込み時の自動リセットを受け付けなくなります。
一度ファームを書き込んだ後は書き込み処理時に手動でリセット（ergoSHIFTではSW_RST1）を押す必要があります。
Sparkfun Qwiic Pro Micro 5Vを使った場合はリセットをダブルクリックすることで書き込みモードに入れることが出来ます。

Arduino IDEでは自分で書き込みのタイミングを制御出来ないため、2回目以降はVSCodeのArduinoプラグインを使って
コンパイルだけ行い、.hex ファイルを取り出して [QMK Toolbox](https://github.com/qmk/qmk_toolbox)を利用して
書き込む方法がおすすめです。
VSCodeは[こちら](https://azure.microsoft.com/ja-jp/products/visual-studio-code/)からダウンロードできます。
インストールが終わったらプラグインからArduinoを検索しマイクロソフト製のArduinoプラグインをインストール。
Arduino IDEで上記の設定が一通り終わった後にこのフォルダをVSCodeで開くことでVSCodeからのコンパイルが可能です。
.inoファイルを開いてVSCodeのコマンドパレットから Arduino: Verify を選択するとコンパイルされ、buildフォルダに
.hexファイルが生成されます。

.hexファイルは[QMK Toolbox](https://github.com/qmk/qmk_toolbox)を使って書き込みが出来ます

1. QMK Toolboxを起動したら、右上のOPENから上記で作成した.hexファイルを選択してください。
2. 右上のドロップダウンから ATMega32u4を選択してください
3. Pro Micro のリセットボタンを押し（Qwiic Pro Micro USB-Cの場合はリセットをダブルクリックし）、QMK Toolbox
   のログ上に黄色の文字で"Caterina device connected (usbser): ~~~"と出たら右上のFlashボタンを押下すると
   書き込みが開始されます。書き込み完了後に自動でボードがリセットされ新しいファームで立ち上がります。

こちらの方法は追加のソフトのセットアップが必要ですが、コンパイルと書き込みを分けて行えるため、リセットのタイミング
が図りやすいため失敗し辛い為おすすめです（ただし初回書き込みはArduino IDEでないとうまくいかない事があったため、
新品のPro Microを書き込む場合はArduino IDEで行う事をおすすめします）

## ピン配置

.ino ファイルで設定可能です。

こちらのリポジトリ内のファイルではすでに ergoSHIFT 向けに設定済みです。

```C
/* PINOUT (follows Nintendo naming (X=up, B=down)) */
#define PIN_UP    7
#define PIN_DOWN  4
#define PIN_LEFT  3
#define PIN_RIGHT 5
#define PIN_A     MISO         //XBOX B
#define PIN_B     10           //XBOX A  
#define PIN_X     15           //XBOX Y
#define PIN_Y     MOSI         //XBOX X     
#define PIN_L     21           //XBOX LB
#define PIN_R     20           //XBOX RB
#define PIN_ZL    8            //XBOX LT
#define PIN_ZR    19           //XBOX RT
#define PIN_LS    6            //XBOX LS (left analog click)
#define PIN_RS    9            //XBOX RS (right analog click)
#define PIN_PLUS  2            //XBOX START
#define PIN_MINUS 18           //XBOX BACK
#define PIN_HOME  1
```

左利きバージョン（左右反転版）の場合は PIN_LEFT と PIN_RIGHT の定義を入れ替えてください。

```C
/* PINOUT (follows Nintendo naming (X=up, B=down)) */
#define PIN_UP    7
#define PIN_DOWN  4
#define PIN_LEFT  5
#define PIN_RIGHT 3
#define PIN_A     MISO         //XBOX B
#define PIN_B     10           //XBOX A  
#define PIN_X     15           //XBOX Y
#define PIN_Y     MOSI         //XBOX X     
#define PIN_L     21           //XBOX LB
#define PIN_R     20           //XBOX RB
#define PIN_ZL    8            //XBOX LT
#define PIN_ZR    19           //XBOX RT
#define PIN_LS    6            //XBOX LS (left analog click)
#define PIN_RS    9            //XBOX RS (right analog click)
#define PIN_PLUS  2            //XBOX START
#define PIN_MINUS 18           //XBOX BACK
#define PIN_HOME  1
```

## 寄付

もしこのプロジェクトが参考担った場合はベースとなったプロジェクトにいって寄付すると大本のプロジェクトの
人たちが喜びます。

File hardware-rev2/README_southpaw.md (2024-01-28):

Stackup for Southpaw build
========================================================================

ergoSHIFT PCB is built to be reversible, and using the Acrylic shell
in slightly different order, you can make a southpaw version.

The only difference are the stackup and acrylic shell parts configuration.

Acrylic Parts
------------------------------------------------------------------------

You will need to order the parts slightly differently for southpaw version.
You do not need the Layer 2 version.

* acryl-design-ergoSHIFT-Acrylic-layer-01: 2mm
* acryl-design-ergoSHIFT-Acrylic-layer-03: 3mm (to compensate for PCB being flipped upside down)
* PCB
* acryl-design-ergoSHIFT-Acrylic-layer-04: 3mm
* acryl-design-ergoSHIFT-Acrylic-layer-04: 3mm
* acryl-design-ergoSHIFT-Acrylic-layer-05: 2mm
* all other buttons and OLED used are the same.

Stackup
------------------------------------------------------------------------

1. First layer is the same.  Just make sure the screw holes are as shown
   in the picture
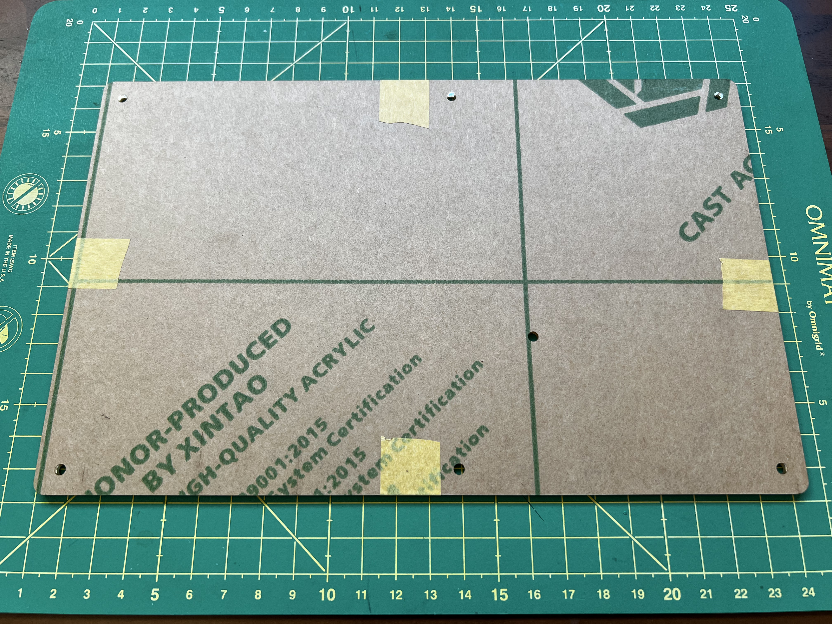
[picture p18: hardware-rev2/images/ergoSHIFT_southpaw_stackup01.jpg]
First Layer
   
2. Second layer we use the Layer-03 file because SMT components will be
   upside-down.
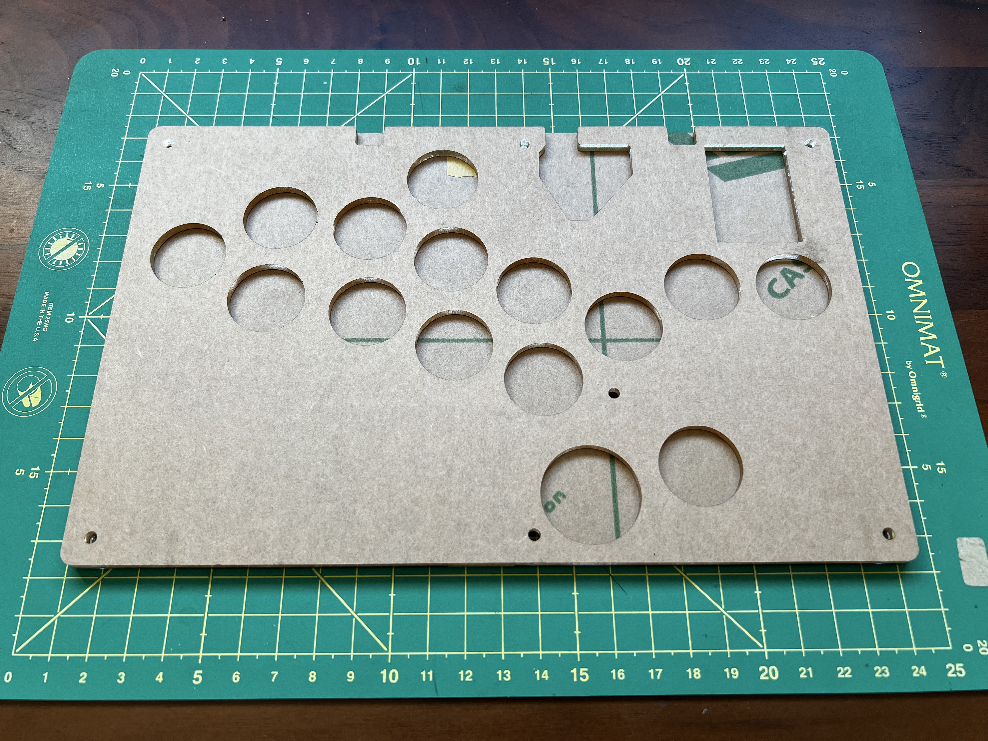
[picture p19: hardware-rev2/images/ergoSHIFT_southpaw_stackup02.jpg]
Second Layer
   
3. Place the PCB upside-down.  The OLED also needs to go to the bottom
   holes, NOT the top holes.  Follow the visible SILKSCREEN for OLED
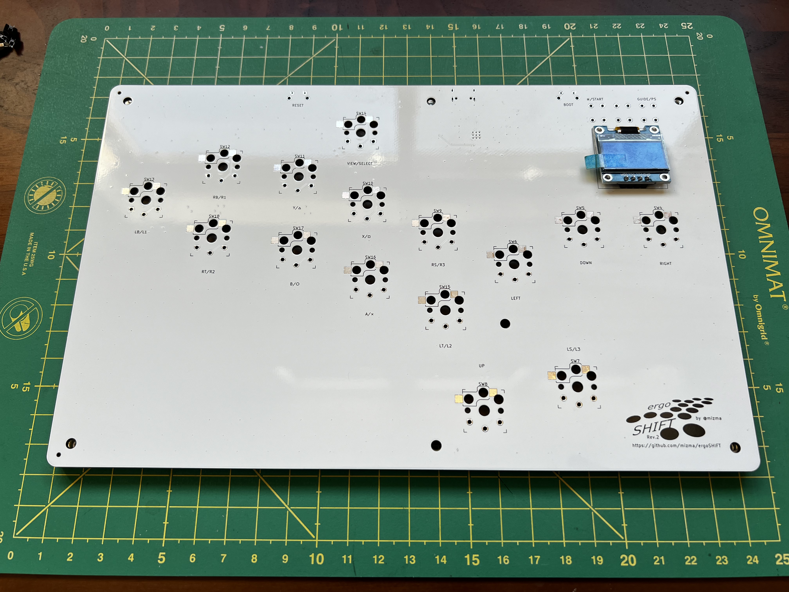
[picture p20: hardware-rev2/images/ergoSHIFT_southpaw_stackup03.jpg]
PCB Layer
   
4. Third and forth layer, we use Layer-04 file since no SMT components
   are on this side.
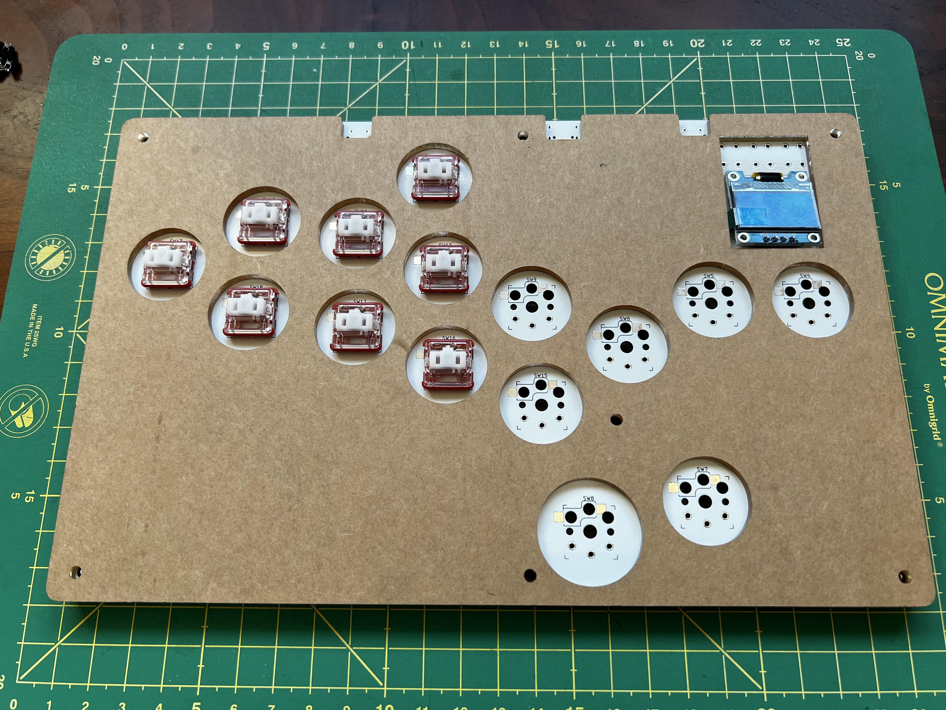
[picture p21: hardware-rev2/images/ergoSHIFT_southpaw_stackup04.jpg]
Third Layer
   
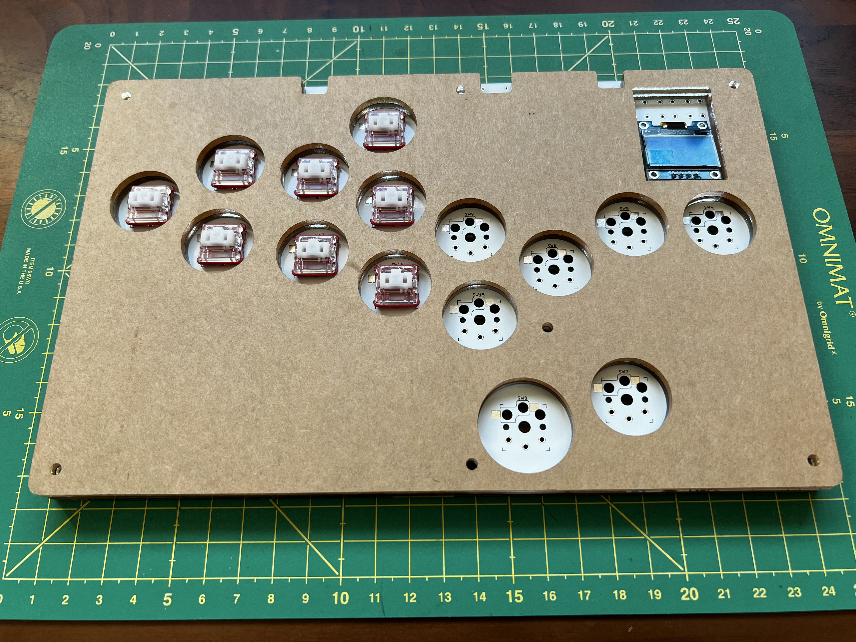
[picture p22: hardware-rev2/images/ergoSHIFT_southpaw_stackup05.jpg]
Forth Layer
   
   For soldering the OLED display, it's best to stack the fron layers in 
   reverse order and solder with the display sitting insied the case.
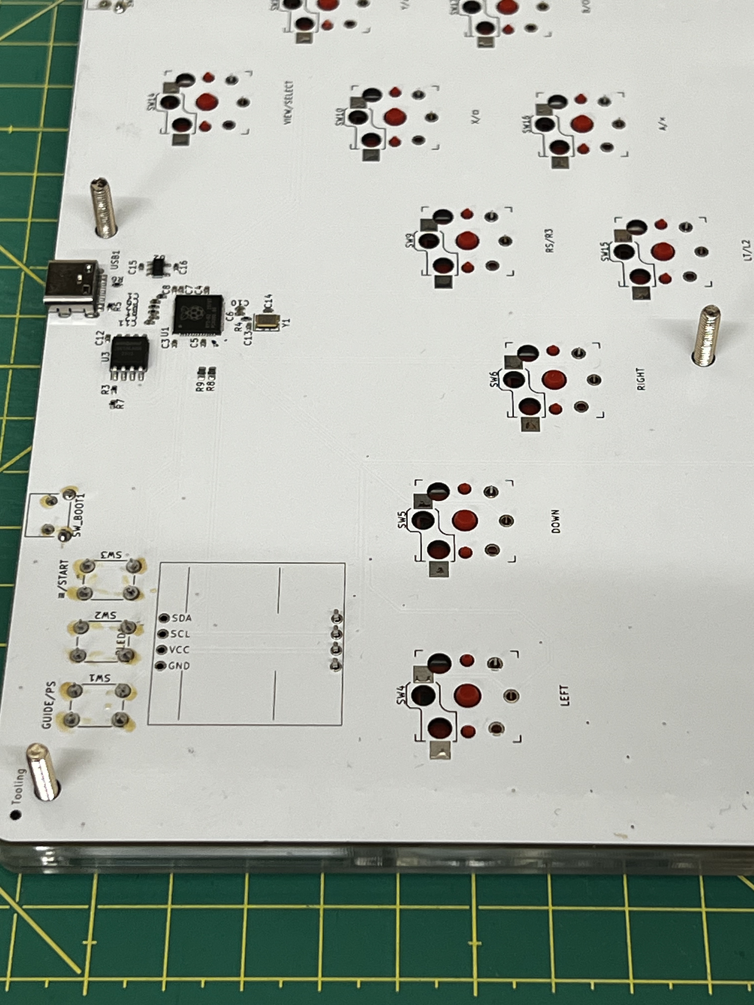
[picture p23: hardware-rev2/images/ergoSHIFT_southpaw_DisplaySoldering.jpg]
OLED Soldering
   
5. Final Layer is the same.
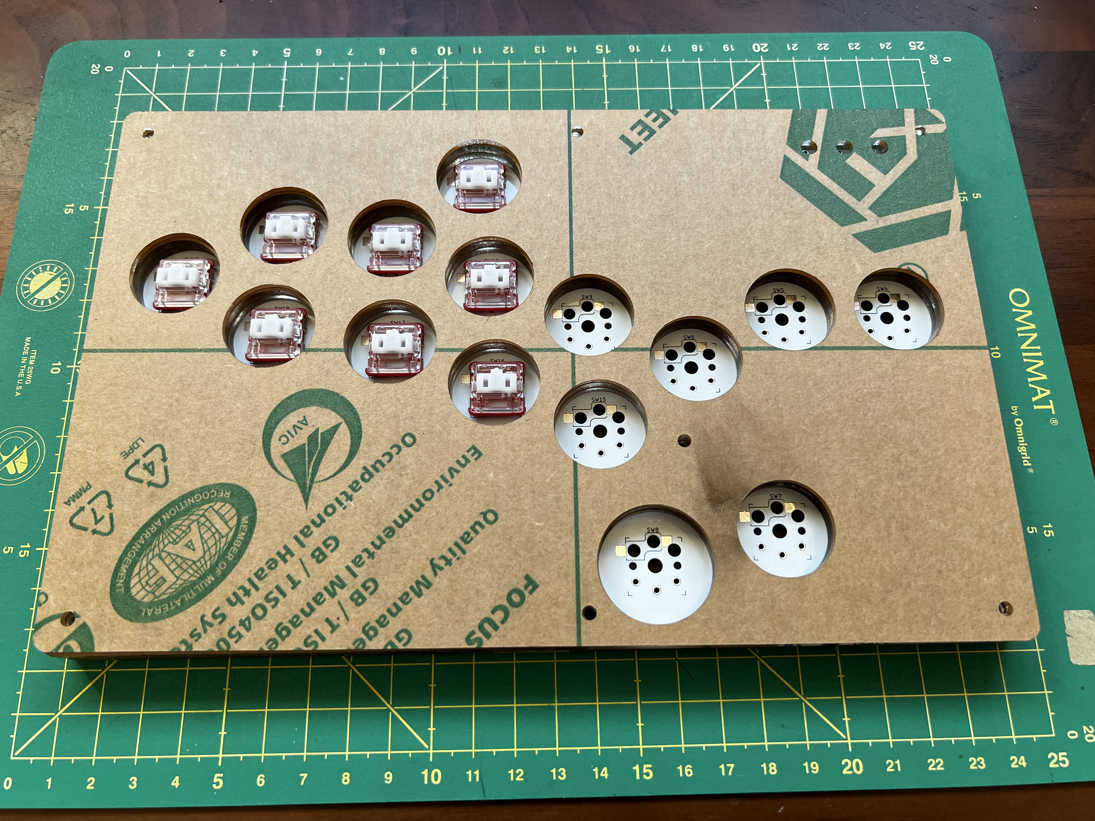
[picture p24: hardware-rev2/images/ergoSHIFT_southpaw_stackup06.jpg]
Final Layer
   
6. For the USB-C port, you may need to grind down the first layer if
   the USB port is hitting the first acrylic layer since it is a very tight fit.
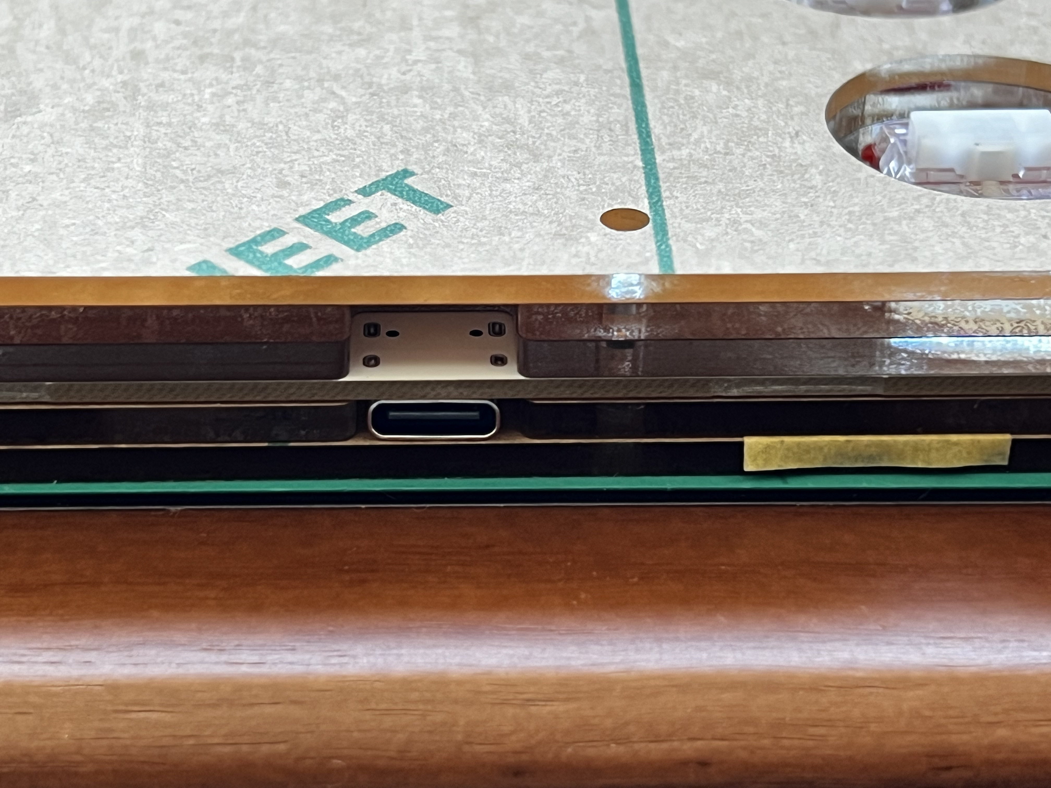
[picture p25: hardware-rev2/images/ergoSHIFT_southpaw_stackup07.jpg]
USB Port
   

For the rest of the build, follow the [README](./README.md)

Once, built, it should look something like this (without button caps).

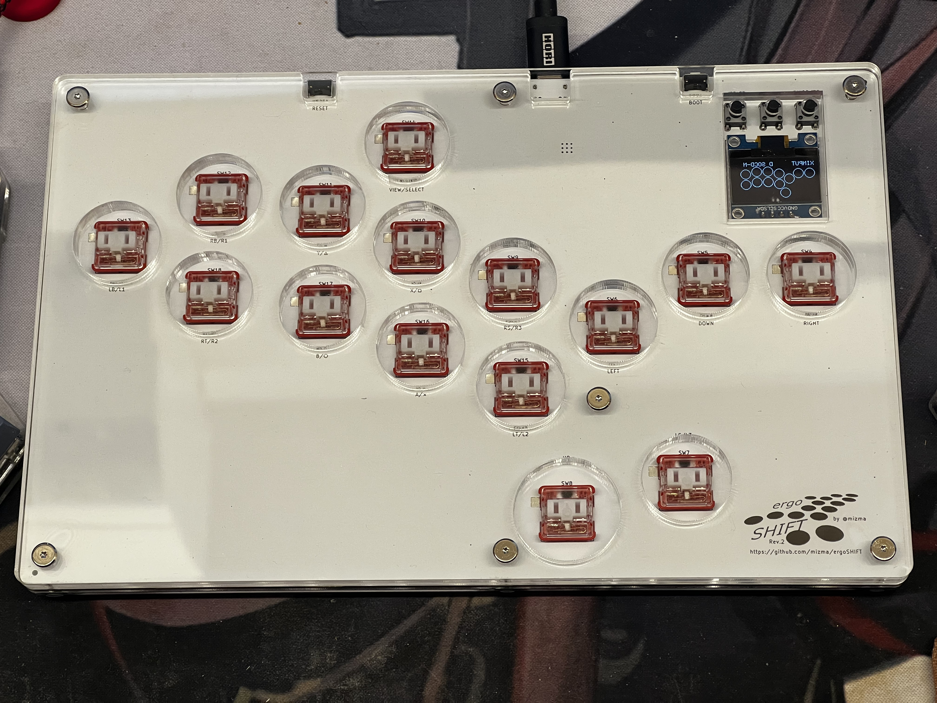
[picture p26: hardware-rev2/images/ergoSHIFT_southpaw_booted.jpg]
Southpaw build


You will need to go into Web Config and change the settings for the display
and the right and left button mapping.

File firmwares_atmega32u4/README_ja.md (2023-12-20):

# ATMEGA32U4 マイコン用ファームウェア

現在 ATMEGA32U4マイコン製 AVRボード（5Vバージョン）用のファームウェアは２種類あります（3.3V版は非対応）。
どちらのファームもSOCDクリーナーや上下ボタン反転機能は同様に動きます。

以下対応機能表になります。

Firmware            | [DINPUT](DINPUT)      | [LUFA](LUFA)          |
------------------- | :-------------------: | :-------------------: |
DInput              | **YES**               | NO                    |
XInput              | NO                    | **YES**               |
PS3                 | **YES**               | NO                    |
Switch              | NO                    | **YES**               |
SOCD                | Hitbox,Gafro,NEUTRAL  | Hitbox,Gafro,NEUTRAL  |
Vertical Inversion  | **YES**               | **YES**               |
DPAD emulation      | **YES**               | **YES**               |
Fake Left Stick     | NO                    | **YES**               |
Fake Right Stick    | NO                    | **YES**               |

## 各種設定 

以下の表に各ファームウェアが対応する設定機能と操作方法を示します。
設定はすべて電源オフしても保持されます。

| ファーム | | DINPUT | LUFA |
| :--- | :---: | :---: | :---: |
| 上下反転 | 標準 | ↓ + リセット | ↓ + リセット |
| | 上下反転 | ↑ + リセット | ↑ + リセット |
| SOCDクリーナー | Hitboxモード | R3(RS) + リセット | R3(RS) + リセット |
| | ガフロコンモード | L3(LS) + リセット | L3(LS) + リセット |
| | 全ニュートラル | PS(HOME) + リセット | PS(HOME) + リセット |
| 入力モード変更 | Xinput | 非対応 | "Start" + リセット |
| | Switch | 非対応 | "Select" + リセット |
| | DInput/PS3 | デフォルト | 非対応 |
| 方向入力モード | 十字キー | デフォルト | UP+START+SELECT |
| | 左アナログスティック  | 非対応 | LEFT+START+SELECT |
| | 右アナログスティック  | 非対応 | RIGHT+START+SELECT |

リセットキーを使った設定は対応したキーを押したままリセットキーを一回短押しして、コントローラーが
再接続するまで待ってください。接続完了時に押されていたキーを判定して設定変更が行われるので、対応キーを
離すのが早すぎると設定されない場合があります。

キーコンボの[カンニングペーパー](ergoSHIFT_Hotkey_Cheatsheet.pdf)を作ったので覚えるのが面倒な場合は
こちらを印刷して裏側等に挟み込んでご利用ください（印刷サイズ：B5）

## [DINPUT](./DINPUT/)

こちらのファームはオリジナルのFlatboxのファーム(Dinput)をベースにしたものになります。
シンプルなファームでPS3まで対応しているためPC(DInput)とPS3を利用する場合はこちらをご利用ください。

## [LUFA](./LUFA/)

こちらは[CrazyRedMachine](https://github.com/CrazyRedMachine)様作成の
[LUFAHybridFightstick](https://github.com/CrazyRedMachine/LUFAHybridFightstick)をベースにergoSHIFT用にカスタマイズ
したファームになります。Xinputとニンテンドースイッチに対応しています（XinputはPCのみ対応。XBoxには認証チップ
が必要なため非対応になります）。

スイッチモードとXInputモードはキーコンボで設定切り替え可能です（上記表参照）。
また、疑似アナログスティック入力に対応しています。

PCで利用する際にDInput非対応のソフトを利用する場合やニンテンドースイッチで利用する場合にこちらをお使いください。

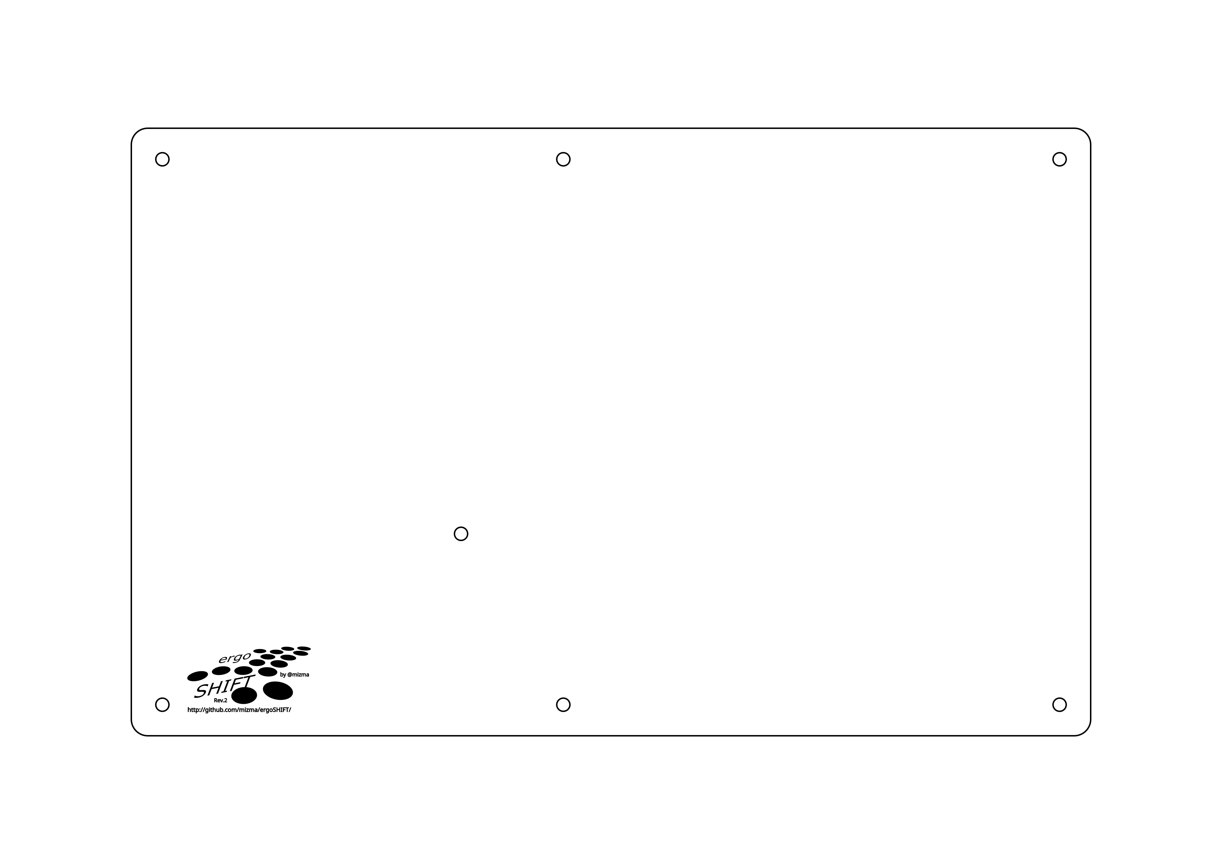
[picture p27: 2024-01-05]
hardware-rev2/images/ergoSHIFT-backplate-stencil-with-OLED-reversed.png

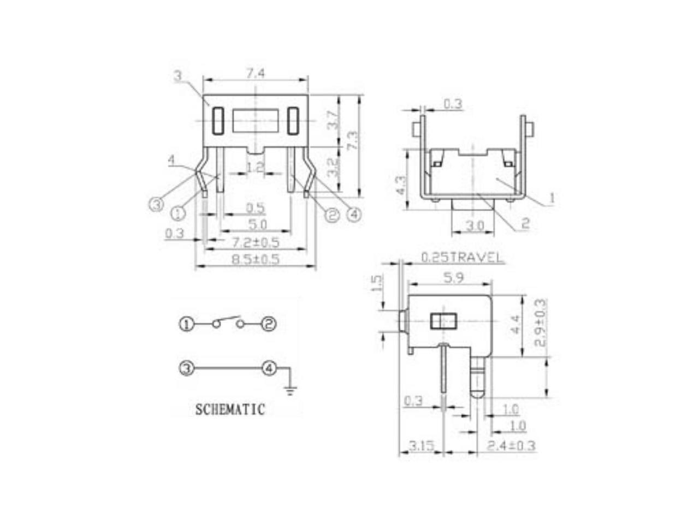
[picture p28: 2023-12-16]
hardware-rev2/images/tactile-switch_3x6x4.3.jpg

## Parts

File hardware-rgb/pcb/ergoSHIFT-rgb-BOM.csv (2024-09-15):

Comment | Designator | Footprint | LCSC
1u | C1,C9,C15,C16 | Capacitor_SMD:C_0402_1005Metric | C52923
30p | C13,C14 | Capacitor_SMD:C_0402_1005Metric | C1570
100nF | C17,C18,C19,C20,C21,C22,C23,C24,C25,C26,C27,C28,C29,C30,C31 | Capacitor_SMD:C_0402_1005Metric | C52923
100n | C2,C3,C4,C5,C6,C7,C8,C10,C11,C12 | Capacitor_SMD:C_0402_1005Metric | C1525
SK6812-EC20 | D1,D2,D3,D4,D5,D6,D7,D8,D9,D10,D11,D12,D13,D14,D15 | LED_SMD:LED_SK6812_EC20_2.0x2.0mm | C2909058
27 | R1,R2 | Resistor_SMD:R_0402_1005Metric | C138021
10k | R3 | Resistor_SMD:R_0402_1005Metric | C25744
1k | R4,R7 | Resistor_SMD:R_0402_1005Metric | C11702
5.1k | R5,R6 | Resistor_SMD:R_0402_1005Metric | C25905
4.7k | R8,R9 | Resistor_SMD:R_0603_1608Metric | C23162
RP2040 | U1 | RP2040:RP2040-QFN-56 | C2040
TLV73333PDBV | U2 | Package_TO_SOT_SMD:SOT-23-5 | C134139
W25Q128JVS | U3 | Package_SO:SOIC-8_5.23x5.23mm_P1.27mm | C97521
HRO-TYPE-C-31-M-12 | USB1 | Type-C:HRO-TYPE-C-31-M-12-Assembly | C165948
Crystal_GND24 | Y1 | Crystal:Crystal_SMD_3225-4Pin_3.2x2.5mm | C9002

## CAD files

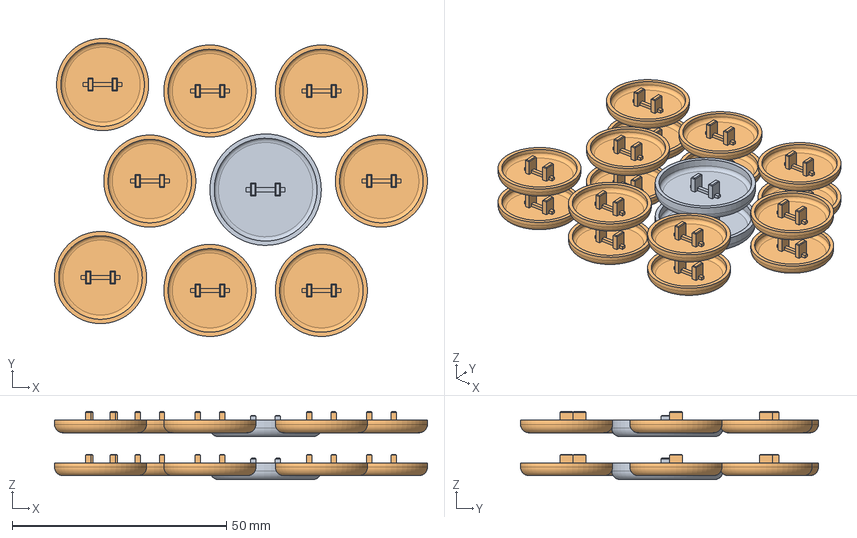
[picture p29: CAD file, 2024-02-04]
3d-printed-buttoncaps/design_data/ergoSHIFT-FullSetButtonCaps.step
87.0 x 69.5 x 15.9 mm
LCS_Origin

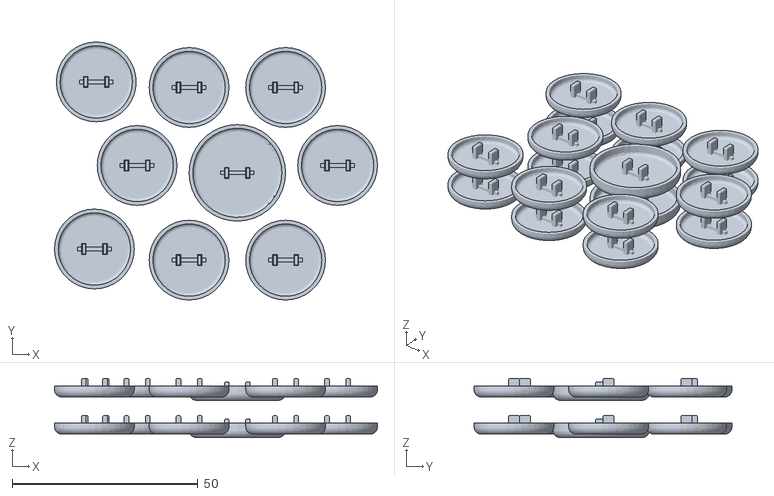
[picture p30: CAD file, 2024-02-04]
3d-printed-buttoncaps/ergoSHIFT-FullSetButtonCaps.stl
87.0 x 69.5 x 15.9

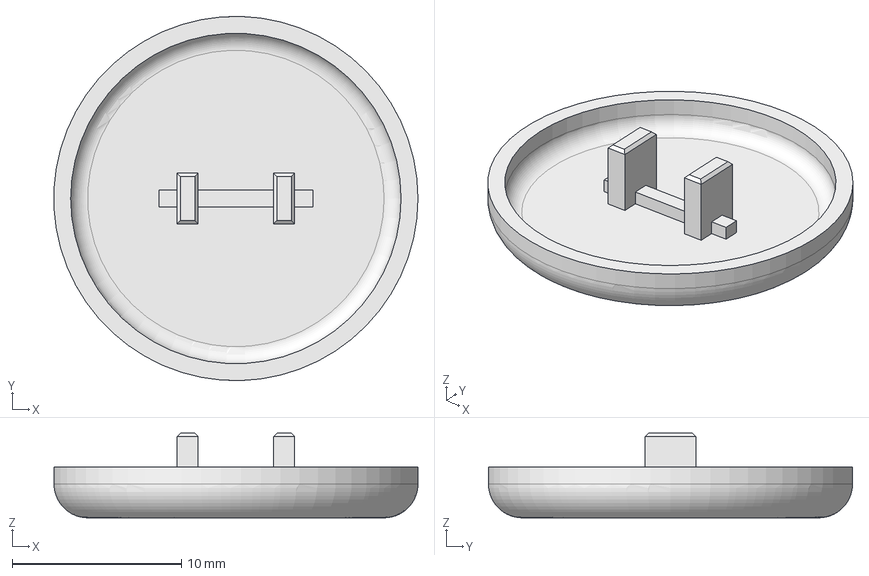
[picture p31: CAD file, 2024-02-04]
3d-printed-buttoncaps/design_data/ergoSHIFT-ButtonCap.FCStd
21.5 x 21.5 x 5.00 mm

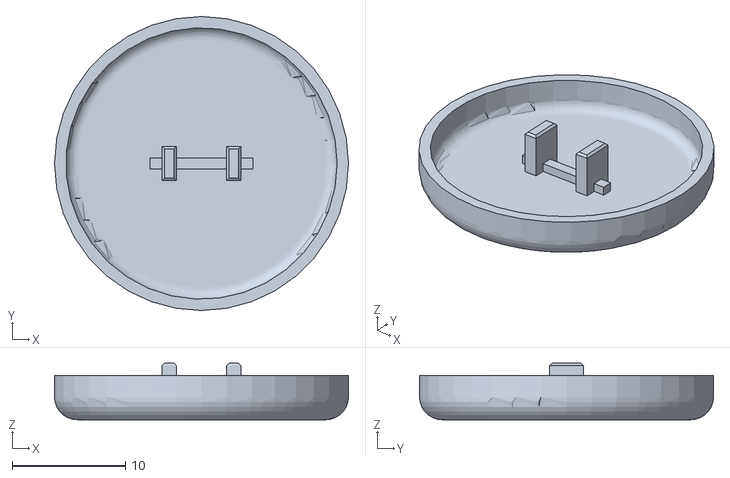
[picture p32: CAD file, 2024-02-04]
3d-printed-buttoncaps/ergoSHIFT-ButtonCapBig.stl
26.0 x 26.0 x 5.00

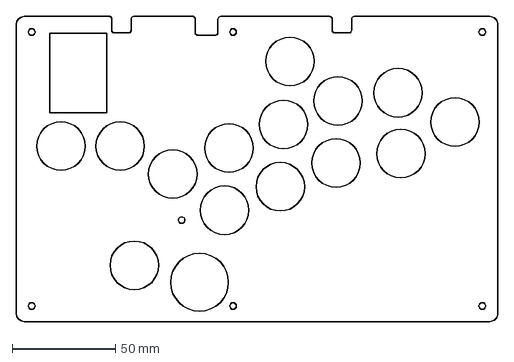
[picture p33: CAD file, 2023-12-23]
hardware-rev2/acrylic-shell/acryl-design-ergoSHIFT-Acrylic-layer-04.dxf
233.2 x 147.7 mm

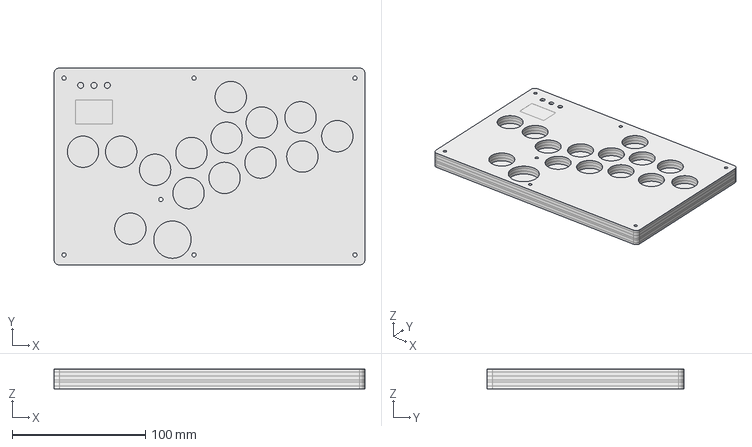
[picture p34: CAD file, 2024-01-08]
hardware-rev2/design_data/acryl-design/acryl-design.FCStd
233.2 x 147.7 x 14.7 mm

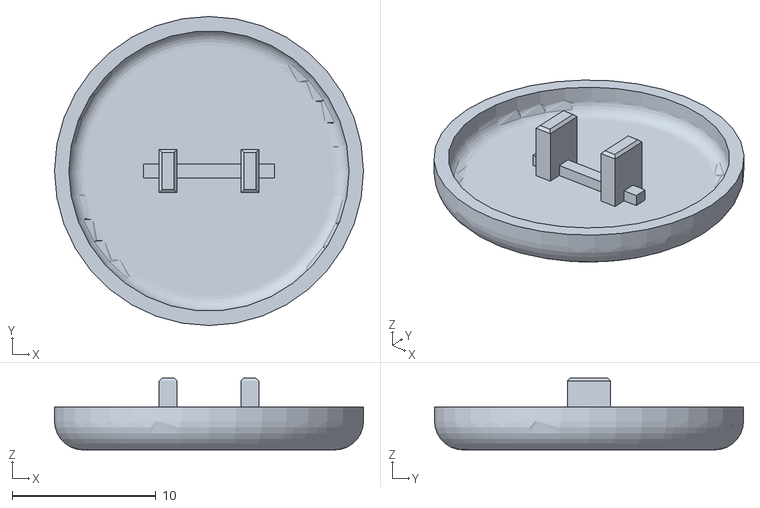
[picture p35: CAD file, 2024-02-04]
3d-printed-buttoncaps/ergoSHIFT-ButtonCap.stl
21.5 x 21.5 x 5.00

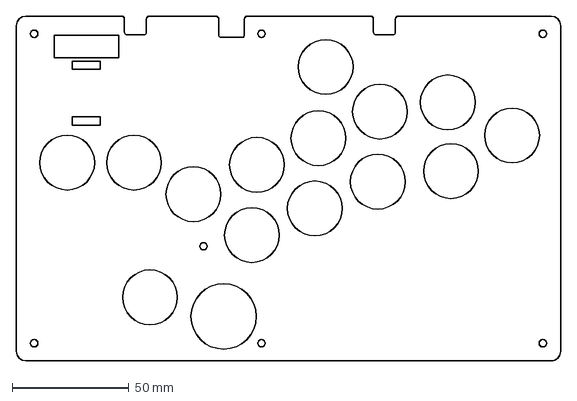
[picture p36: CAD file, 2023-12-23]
hardware-rev2/acrylic-shell/acryl-design-ergoSHIFT-Acrylic-layer-02.dxf
233.2 x 147.7 mm

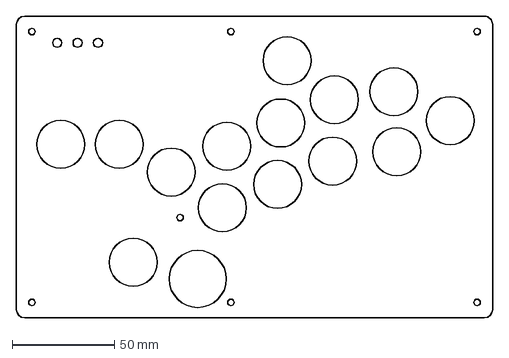
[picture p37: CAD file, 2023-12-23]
hardware-rev2/acrylic-shell/acryl-design-ergoSHIFT-Acrylic-layer-05.dxf
233.2 x 147.7 mm

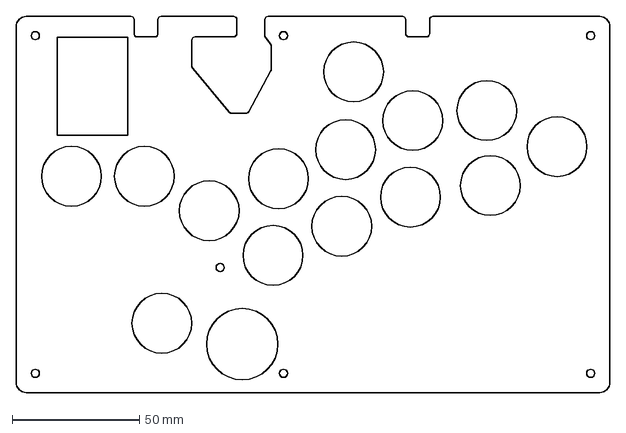
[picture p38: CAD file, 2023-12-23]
hardware-rev2/acrylic-shell/acryl-design-ergoSHIFT-Acrylic-layer-03.dxf
233.2 x 147.7 mm

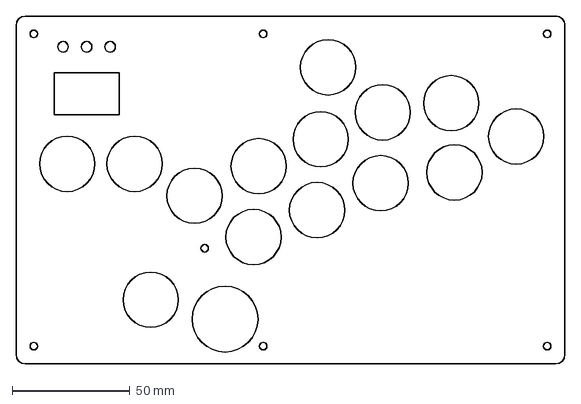
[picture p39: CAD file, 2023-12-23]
hardware-rev2/acrylic-shell/acryl-design-ergoSHIFT-Stencil-layer.dxf
233.2 x 147.7 mm

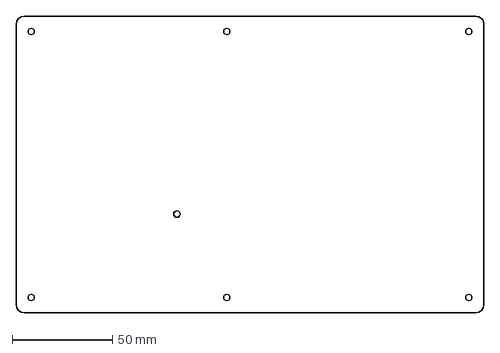
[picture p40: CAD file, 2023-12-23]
hardware-rev2/acrylic-shell/pcb-design-ergoSHIFT-PCB-layer.dxf
233.2 x 147.7 mm

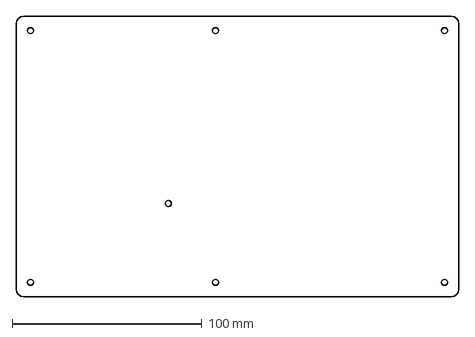
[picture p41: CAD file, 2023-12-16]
hardware-rev2/acrylic-shell/acryl-design-ergoSHIFT-Acrylic-layer-01.dxf
233.2 x 147.7 mm

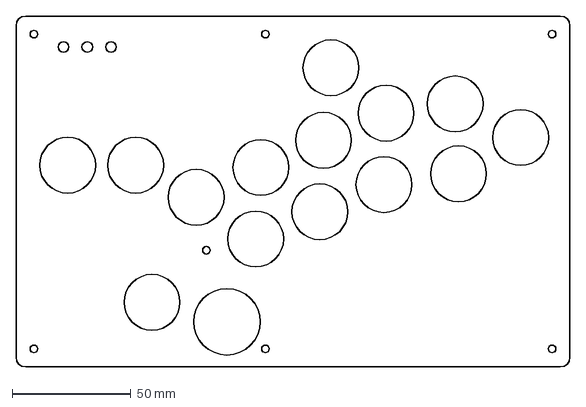
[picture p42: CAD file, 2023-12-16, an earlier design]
hardware-rev1/acrylic-shell/acryl-design-ergoSHIFT-Acrylic-layer-05.dxf
233.2 x 147.7 mm

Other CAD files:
ErgoSHIFT Layout/ErgoSHIFT.FCStd
3d-printed-buttoncaps/design_data/ergoSHIFT-ButtonCapBig.FCStd
hardware-rev1/design_data/acryl-design/acryl-design.FCStd
hardware-rev1/acrylic-shell/acryl-design-ergoSHIFT-Acrylic-layer-03.dxf
3d-printed-buttoncaps/design_data/ergoSHIFT-FullSetButtonCaps.FCStd
hardware-rev1/acrylic-shell/acryl-design-ergoSHIFT-Acrylic-layer-02.dxf
hardware-rev1/acrylic-shell/acryl-design-ergoSHIFT-Acrylic-layer-04.dxf
hardware-rev1/acrylic-shell/pcb-design-ergoSHIFT-PCB-layer.dxf

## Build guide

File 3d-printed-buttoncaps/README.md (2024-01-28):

3D Printed Button Cap data
========================================================================

This directory hosts the 3D printable STL files and their original
design data for the ergoSHIFT compatible button caps.

You may use the [Full Set](./ergoSHIFT-FullSetButtonCaps.stl) to order
a full set of key-caps from third parties with SLS or MJF print capabilities,
or you may use other printing solutions using the individual stl files.

You will need 14 of the [small caps](./ergoSHIFT-ButtonCap.stl) and one
[big cap](./ergoSHIFT-ButtonCapBig.stl) for an ergoSHIFT build.

The button caps printed using PA12W MJF print looks something like this on
the ergoSHIFT rev1.

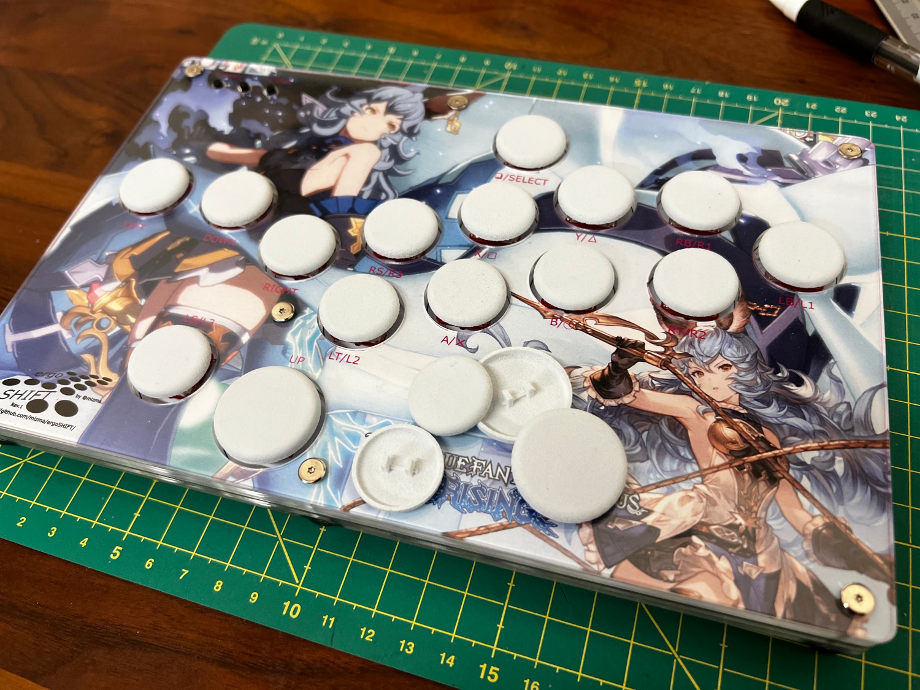
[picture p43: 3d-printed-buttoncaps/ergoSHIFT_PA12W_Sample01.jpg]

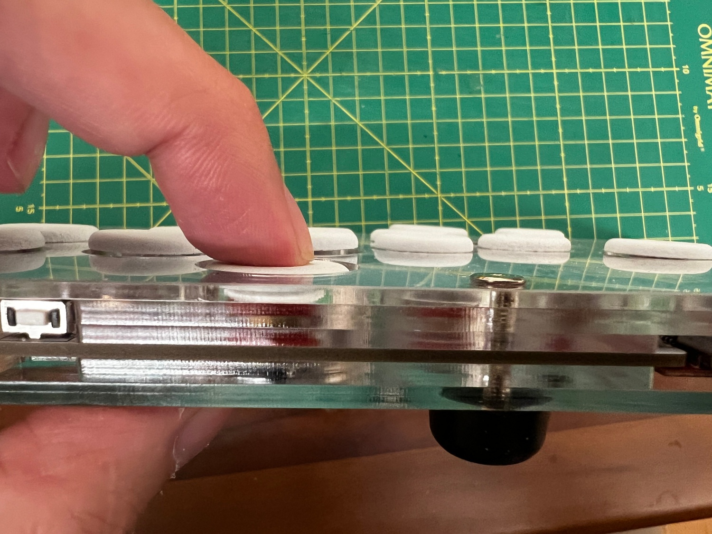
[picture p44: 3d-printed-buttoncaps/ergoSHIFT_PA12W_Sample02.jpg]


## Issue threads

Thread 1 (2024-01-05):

Fix layer thickness

mizma, 2024-01-05:
Got too thick due to adding display on rev.2 shave 1mm off acrylic layer 1

mizma, 2024-01-06:
Fixed

Closed 2024-01-06.

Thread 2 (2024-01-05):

Figure out what to do with Firmware

mizma, 2024-01-05:
merge to mainstream? upload build here? what to do...

mizma, 2024-01-05:
commited config file for GP2040-CE and a .uf2 file.
sent PR to mainstream and waiting review.

mizma, 2024-01-05:
Fix following concerns and resubmit for re-review.

Hi @mizma , thank you for the PR on this.

My general feedback from looking at your repo:
1 - There are parts of the repo listed as design not verified. This has traditionally lead to issues as people may make boards that could have issues. For this we would want to wait until the design is solidified, tested and ready for anyone to pickup and make.
2 - It requires the use of JFA SBM parts (keycaps and aux keys). Ideally there would be a 3D printed alternative to this. SBM parts can be quite expensive to get in some places.
3 - General concerns around this line You may need to adjust the rotation, placement of some parts in CPL, check before you order. It should look like the following.. If the CPL files are not lining up for services like JLC it will need to be fixed. This will lead to people not getting working boards or boards that could be missing parts.

Once these main concerns are addressed we can take a look at including the board. We have an expectation that you will be active in the community if included and offer support for people that have questions about it.

mizma, 2024-01-07:
1 - remaining: southpaw build check, 3D print caps check, 2mm layer 1 acrylic check.  all other portions (PCB and parts implementation, PCB assembly ordering data and acrylic ordering data are verified)
2 - 3D printable button caps designed.  waiting for actual print to finish and get verified.
3 - Double-checked Gerber+BOM+CPL and they will work out of the box at present.  keeping a heads up for future though, since parts shortage or parts design revision can break the design in the future and would like people to notice and ask for help if necessary

mizma, 2024-02-05:
Gerber is OK.
3D print caps going through another round of iteration.  will print sometime later.
2mm acrylic layer 1 confirmed (built and tested)
Southpaw build check complete.

remaining:

- update document from feedback: how to solder display (tight tolerance so need to follow certain build flow)
- 3D printed button caps still too tight fit in the legs.  updated the dimensions, still requires another test print

mizma, 2024-05-18:
new 3D printed button cap design now ordered for MJF print.  will be confirmed after print is done.

mizma, 2024-05-25:
3D printed caps came out in perfect size.

mizma, 2024-05-25:
also, documentation added for how to solder OLED.

all initial concerns should be fixed (current gerber files and PCBA files work on JLCPCB website with correct placement)

Closing issue as done

Closed 2024-05-25.

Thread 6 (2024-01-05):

Create 3D models for replacement caps

mizma, 2024-01-05:
create a 3D model for the key caps compatible with ergoSHIFT.

- make the model for Φ21.5
- make the model for Φ26
- make assembly to print one set
- export STL file

mizma, 2024-01-06:
initial model created.  waiting for first print to come in.

mizma, 2024-01-13:
first print is confirmed.
It technically works, but two problems
* using MJF PA12W Nylon print, the legs are too thick.it can be inserted, but should be thinner.
* small caps diameter is a bit too large and it fits in the acryl case button cut-outs, but some portions are uncomfortably close to hitting.  With a bit of unlucky tolerance issues, it could hit the case.

fixed above issues in new model and doing second batch print to confirm design.

mizma, 2024-01-19:
second print confirmed.

Legs are still on the thicker side (some came out thicker than last one, so definately high variance in manufacturing)
small cap diameter is now perfect size.

sanding is better than too loose cap.  finalizing the design with second design.

Closed 2024-01-19.

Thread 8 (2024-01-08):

Rev2.1 ideas: make things thinner

mizma, 2024-01-08:
Changes that doesn't require firmware change:

Do away with the rubber feet and use a M3 hex spacer (female-female) inside and use M3 screws to screw in from both sides.

PCB layout can stay the same but all acrylic layers except Layer 1 and layer 5 as well as PCB mounting holes needs to be made wider to accomodate the spacer.

mizma, 2024-02-05:
M3 spacer (all threaded 0.5mm pitch) 8mm (should be 8mm-9mm).  width 5.5mm (between flat heads)
https://www.monotaro.com/g/00428593/?monotaroNo=42267391

slim head flat M3x6 screw
https://www.monotaro.com/g/00429329/?monotaroNo=29027268

6mm should work if the spacer is through-hole threaded (some spacers have wall in the middle.  in which case, 5mm screw is needed (but 6mm is more available)

mizma, 2024-02-05:
expanding the hole is something to consider.
PCB should be a larger hole.  for Acrylic, we may want to go with hex hole to stop the spacer to rotate inside?

mizma, 2024-02-05:
for rubber feet sticker, anything should be fine as long as it is taller than the screw head.

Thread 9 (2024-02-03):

Add scullbox button cap compatibility?

mizma, 2024-02-03:
https://skullboxarcades.com/products/skullbox-convex-button-caps

mizma, 2024-02-03:
change the small button opening to fit 23mm (set from 23.5mm to 24mm)
change the big button opening to fit 29mm (set from 28mm to 30mm)

mizma, 2024-02-05:
seems like skullbox shipping is a little cheaper (at least towards Japan)

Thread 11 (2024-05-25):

Rev2.1 idea 2: move the LS/L3 button to the right of UP

mizma, 2024-05-25:
After using the device, I found LS/L3 to be a bit cramped.
moving the LS/L3 button to slightly lower right of UP button would make it more accessible without being cramped and useful for use with Grapple/DI/Parry in SF6.
making the button a little lower than UP would keep it away from the right hand for accidental presses.

downside is that the board will be larger in the depth direction...  although it might be a choice worth considering.

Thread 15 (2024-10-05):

RGB firmware release

mizma, 2024-10-05:
need to test the patched release with RGB support.

https://github.com/mizma/GP2040-CE/releases/tag/v0.7.10-PATCH (updated with the upstream hot-fix 0.7.10 version)

Hi, @jamesjpenguin if you are still interested, I just built the latest firmware with the RGB LED settings configured into the firmware (also with OLED layout support for ergoShift layout).

I have the firmware as pre-release.  Since I don't have the RGB version built for myself yet, I cannot release as latest.  If you have time to test it out, that would help a lot.

jamesjpenguin, 2024-10-06:
Will give it a shot this weekend and let you know!

jamesjpenguin, 2024-10-07:
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

I realized when I was playing with settings (after my last commit), I had switched the last two LEDs and never updated my repo. Just opened a pull request to make that update (without the red arrow), and I recommend you update the FW to reflect that as well.

Additionally, I noticed that your FW does not set the LED option of "Turn off when suspended". Might be intentional, but I use that option and figure most people might want their controller to turn off when their computer is sleeping, up to you though.

Cheers

mizma, 2024-10-07:
Thanks for checking! I've merged your PR on the Readme.  as for the firmware, I'll fix the mapping next weekend.

I haven't turned the "off while suspended" option on since that seems to be the default at the upstream firmware (similar to OLED off when suspended).

Thanks for the help!

mizma, 2024-10-09:
https://github.com/mizma/GP2040-CE/releases/tag/v0.7.10-PATCH2
Updated the firmware with the correct ordering.

Closed 2024-10-09.

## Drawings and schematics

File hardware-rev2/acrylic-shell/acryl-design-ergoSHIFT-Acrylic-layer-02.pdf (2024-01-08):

9.4

233.17

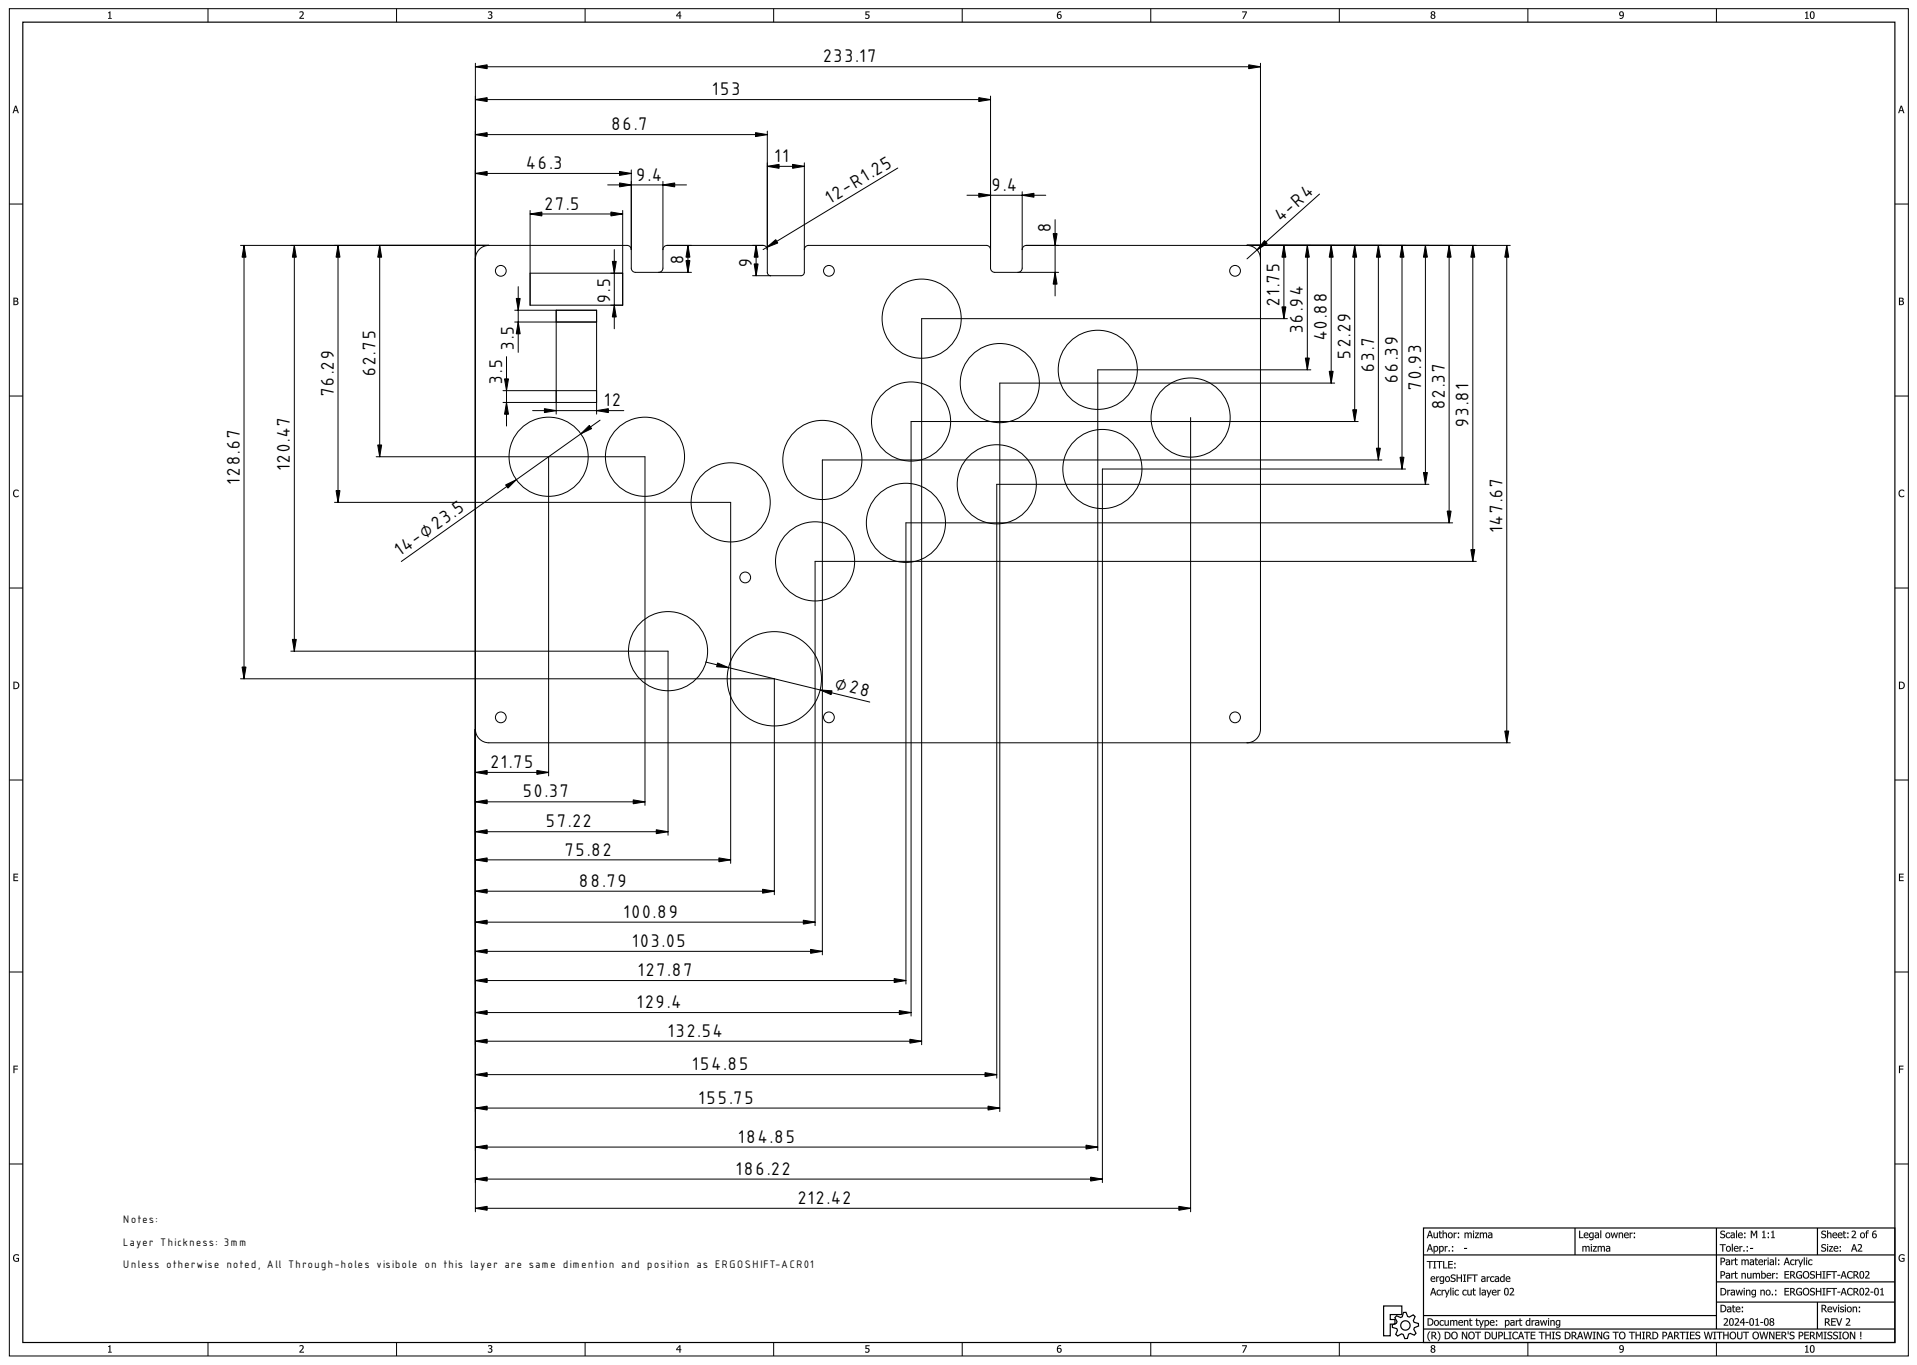
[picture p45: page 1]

N otes:
Layer T hickness: 3m m
U nless otherw ise noted, A ll T hrough-holes visibole on this layer are sam e dim ention and position as E R G O S H IF T-A C R 01

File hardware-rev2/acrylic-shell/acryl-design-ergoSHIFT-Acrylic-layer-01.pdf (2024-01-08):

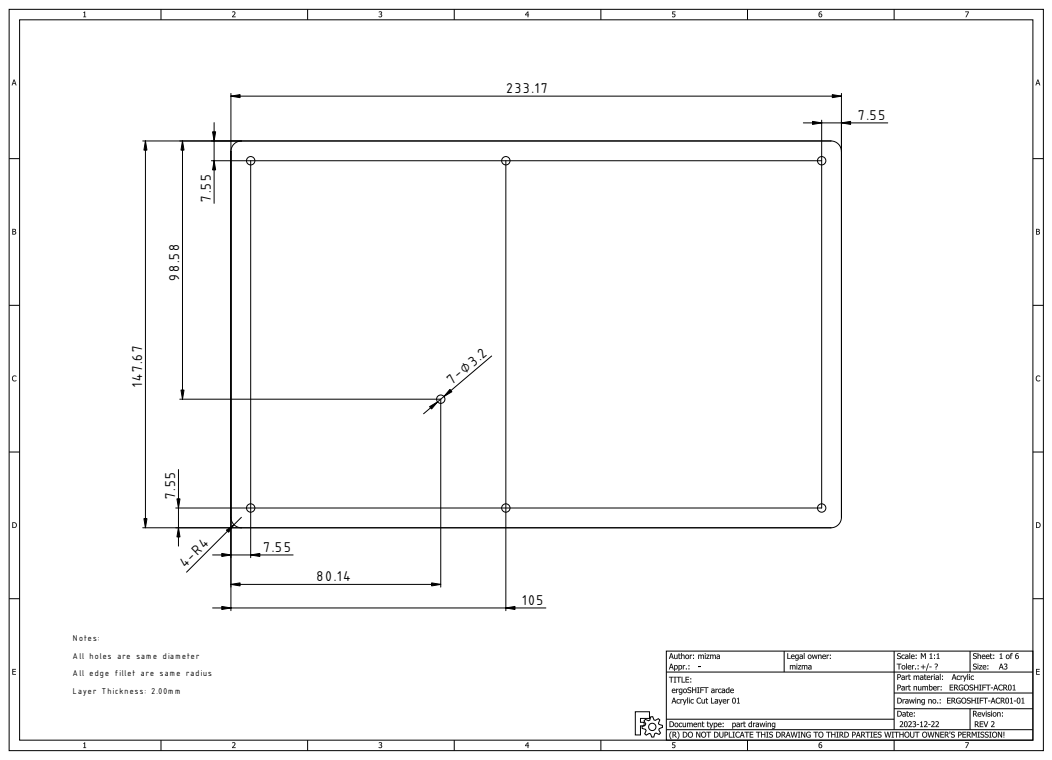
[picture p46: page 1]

4- R 4 7.55 98.58 80.14 147.67 233.17 7-⌀ 3.2 7.55 7.55 7.55 105 N otes: A ll holes are sam e diam eter A ll edge fillet are sam e radius Layer T hickness: 2.00m m

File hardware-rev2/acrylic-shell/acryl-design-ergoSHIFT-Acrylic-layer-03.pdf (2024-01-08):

27.5

## 9.4 ⁸

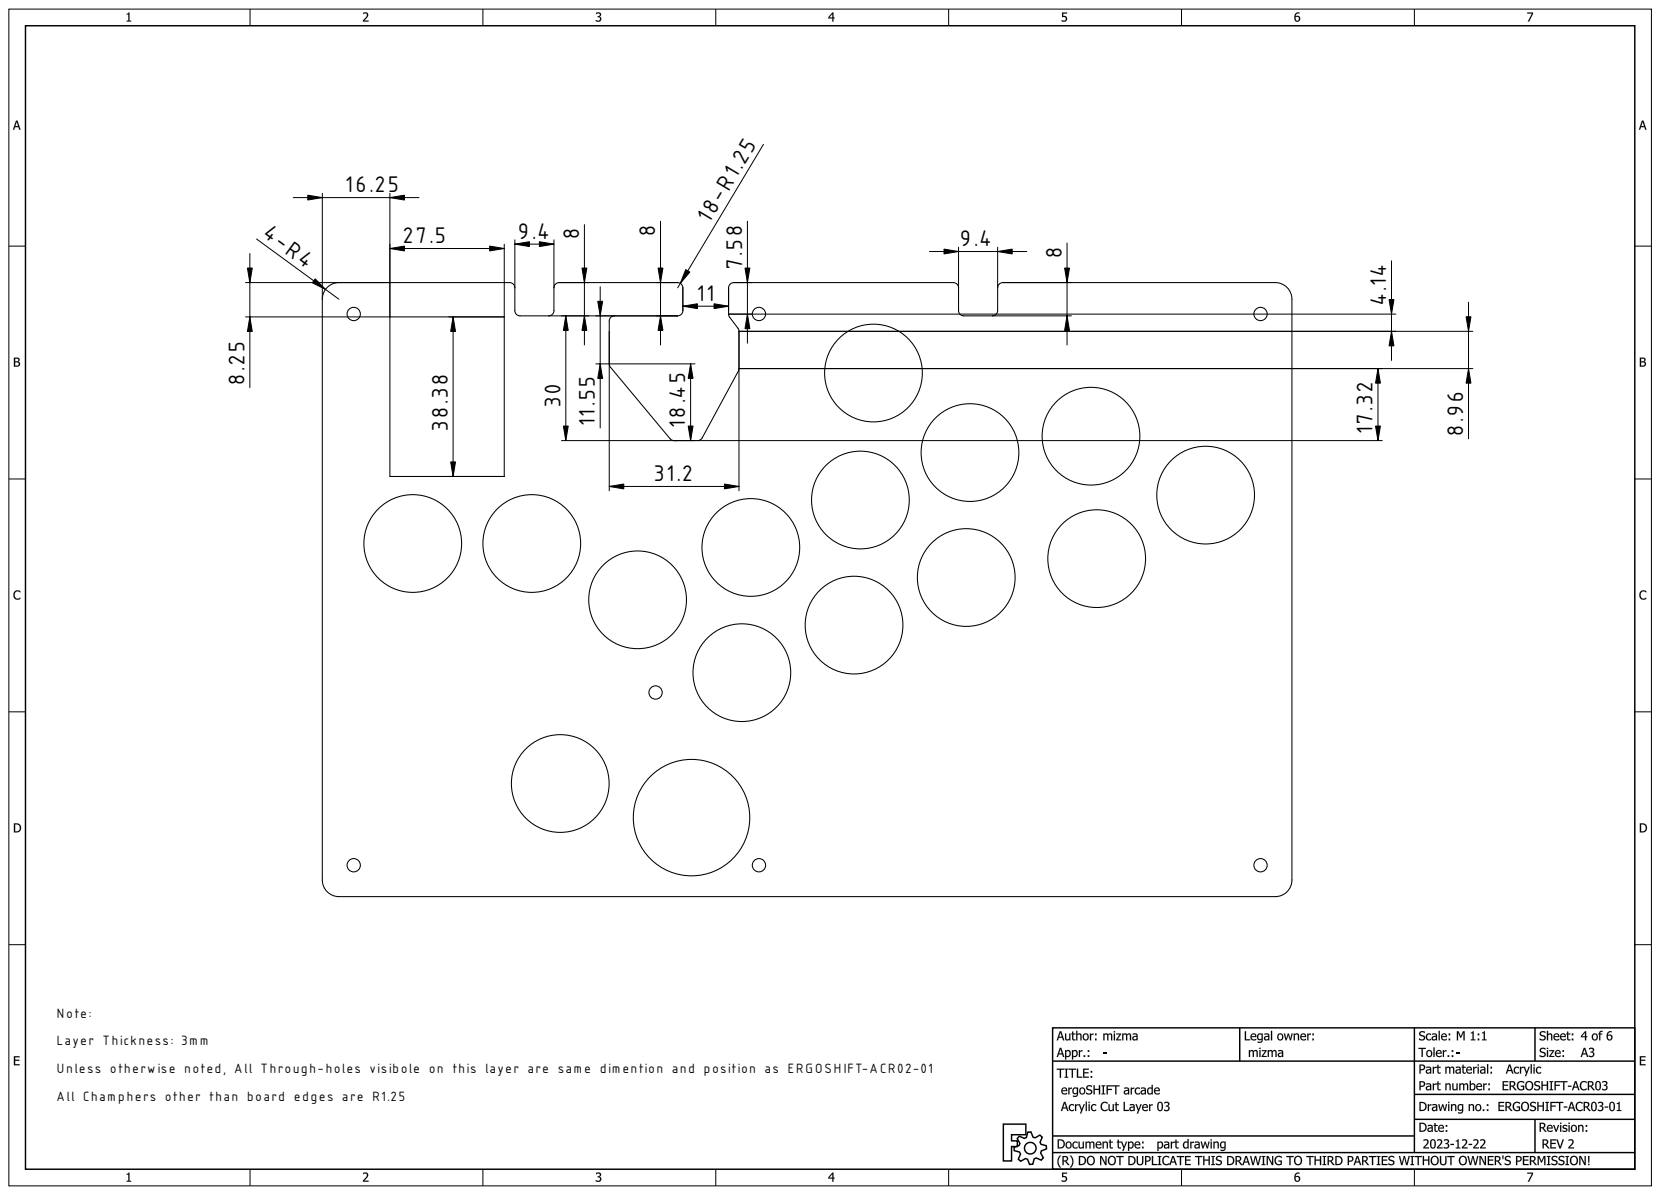
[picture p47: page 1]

N ote:
Layer T hickness: 3m m
U nless otherw ise noted, A ll T hrough-holes visibole on this layer are sam e dim ention and position as E R G O S H IF T-A C R 02-01
A ll Cham phers other than board edges are R 1.25

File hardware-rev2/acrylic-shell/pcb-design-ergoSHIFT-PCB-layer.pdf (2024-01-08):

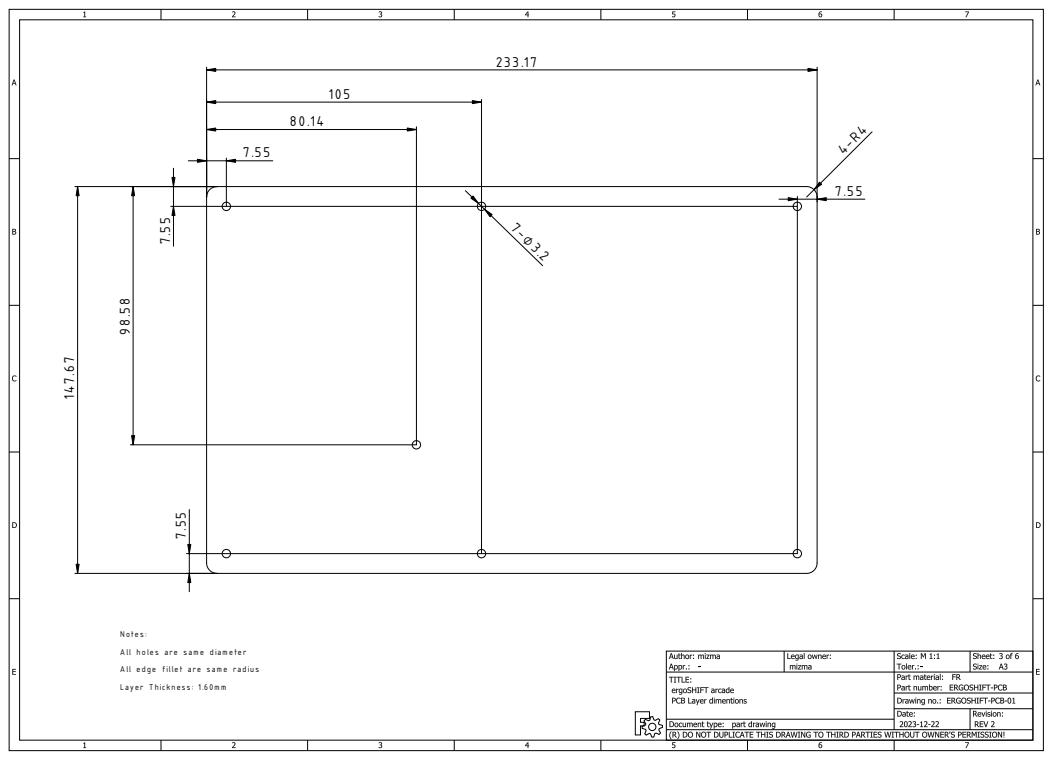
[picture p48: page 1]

7.55 105 7.55 N otes: A ll holes are sam e diam eter A ll edge fillet are sam e radius Layer T hickness: 1.60m m

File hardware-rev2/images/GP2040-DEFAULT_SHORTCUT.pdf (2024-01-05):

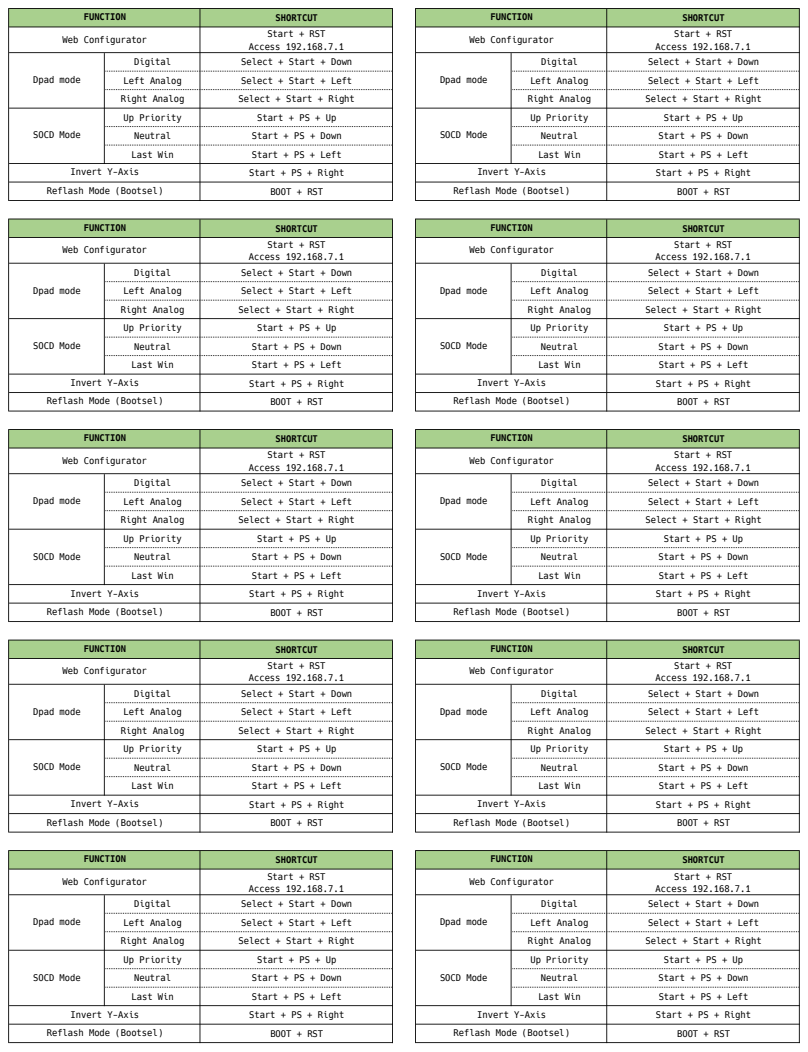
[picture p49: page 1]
SHORTCUT; Start + RST Access 192.168.7.1; Digital; Select + Start + Down; Left Analog; Select + Start + Left; Right Analog; Select + Start + Right; Up Priority; Start + PS + Up; Neutral; Start + PS + Down; Last Win; Start + PS + Left; Start + PS + Right; BOOT + RST; SOCD Mode; Invert Y-Axis; Reflash Mode (Bootsel); FUNCTION; Web Configurator; Dpad mode

Invert Y-Axis
Reflash Mode (Bootsel)

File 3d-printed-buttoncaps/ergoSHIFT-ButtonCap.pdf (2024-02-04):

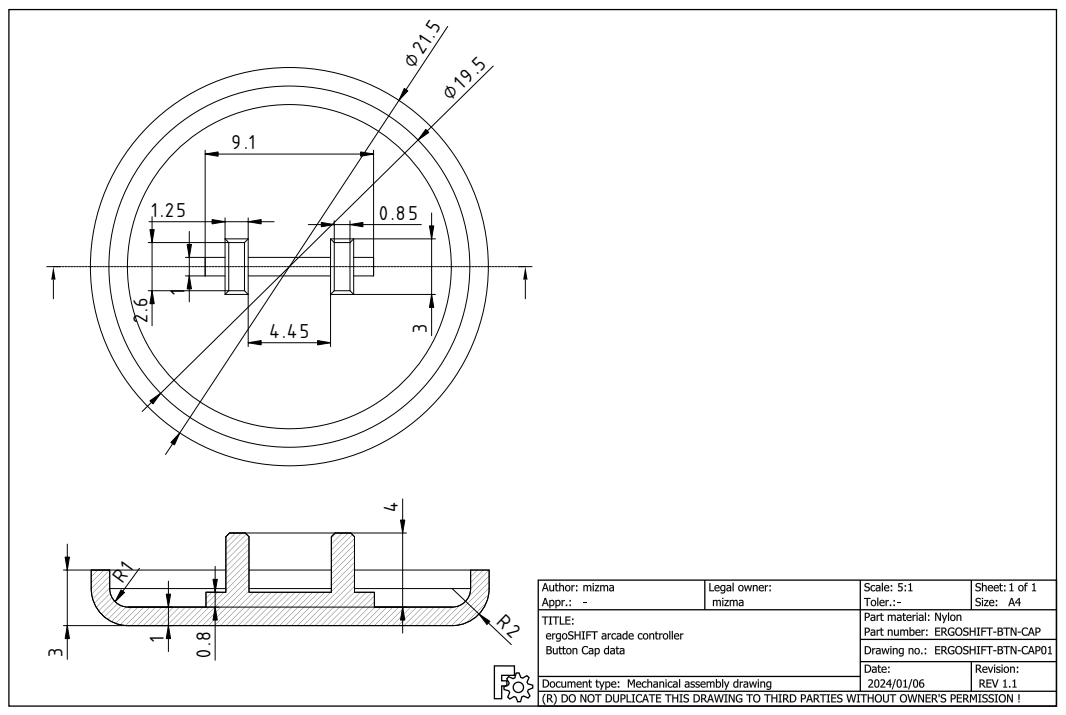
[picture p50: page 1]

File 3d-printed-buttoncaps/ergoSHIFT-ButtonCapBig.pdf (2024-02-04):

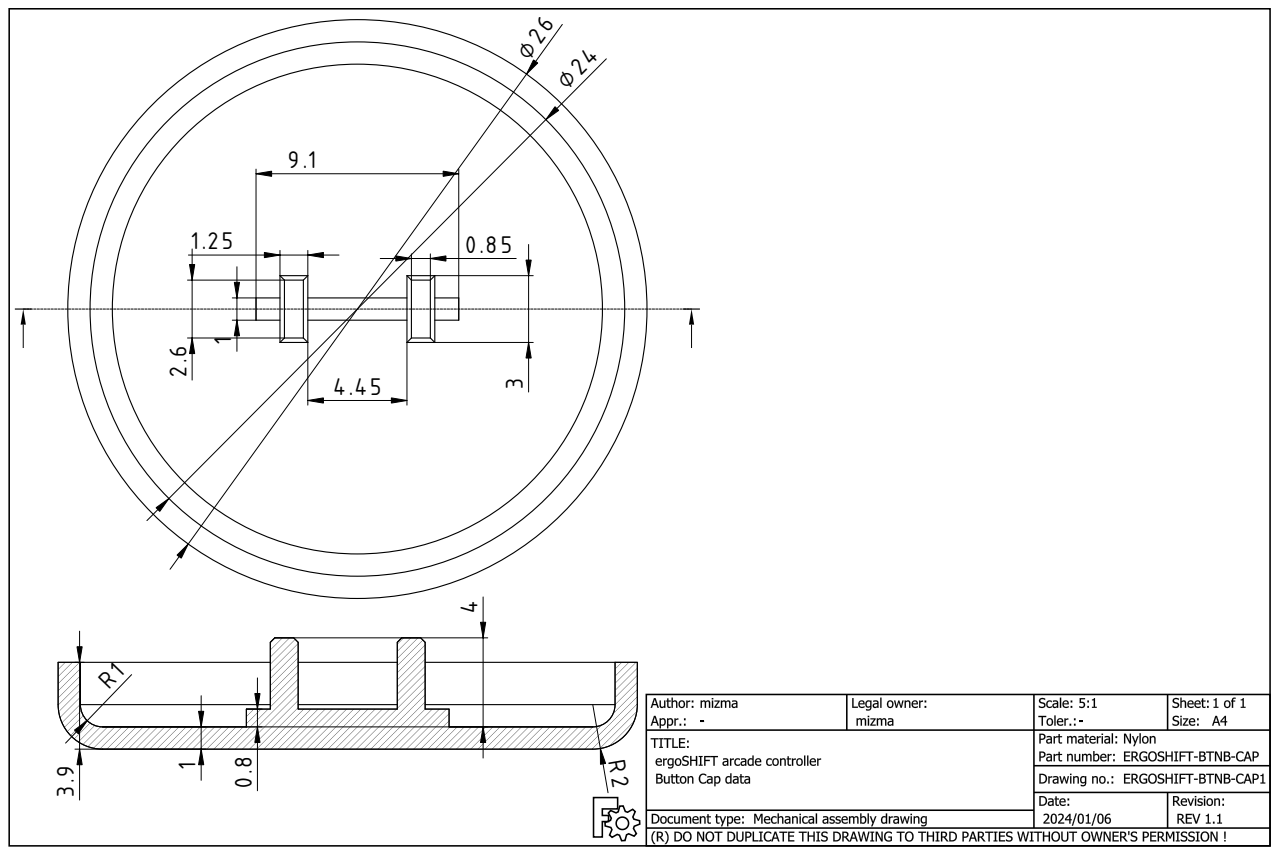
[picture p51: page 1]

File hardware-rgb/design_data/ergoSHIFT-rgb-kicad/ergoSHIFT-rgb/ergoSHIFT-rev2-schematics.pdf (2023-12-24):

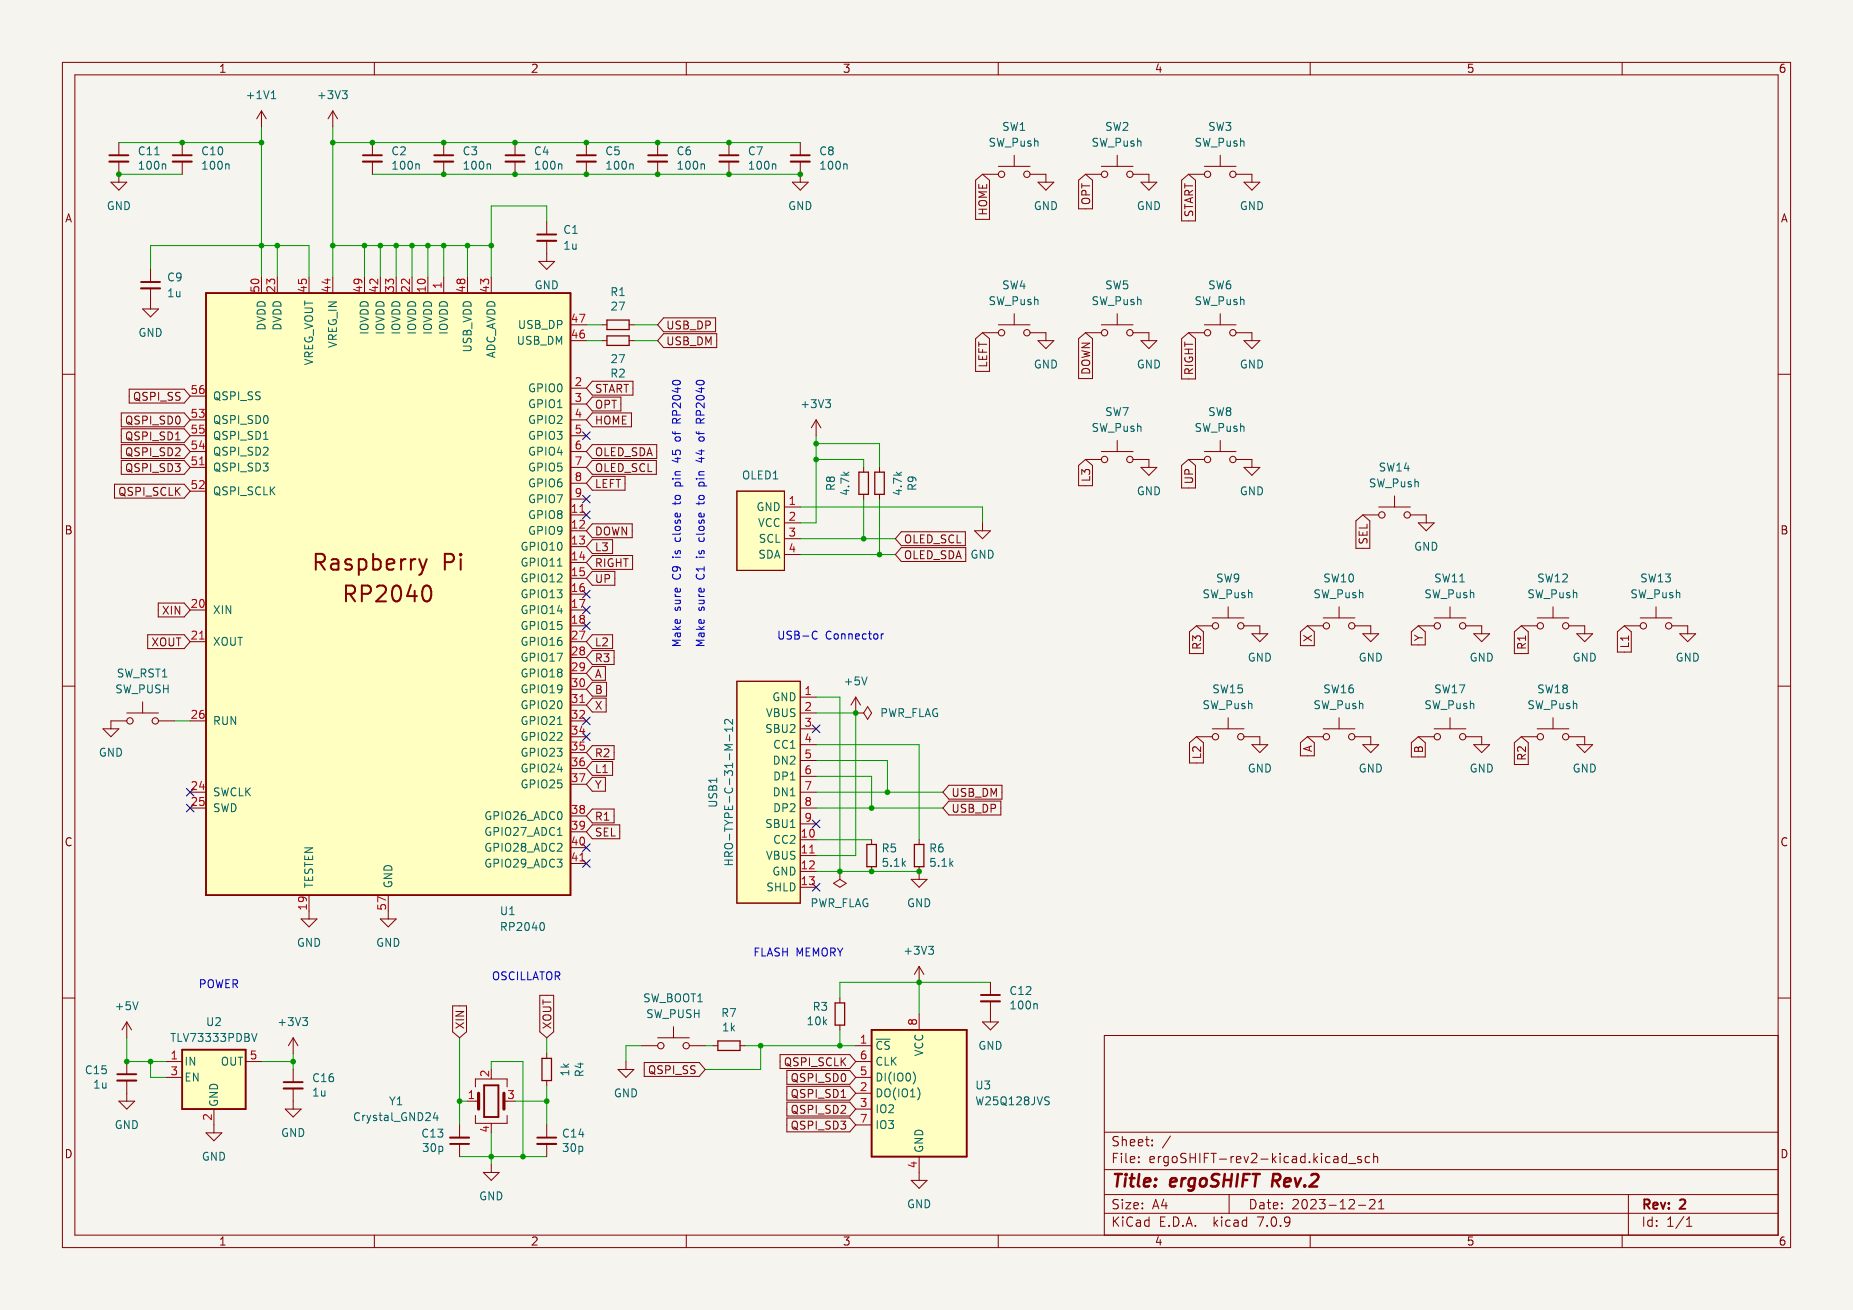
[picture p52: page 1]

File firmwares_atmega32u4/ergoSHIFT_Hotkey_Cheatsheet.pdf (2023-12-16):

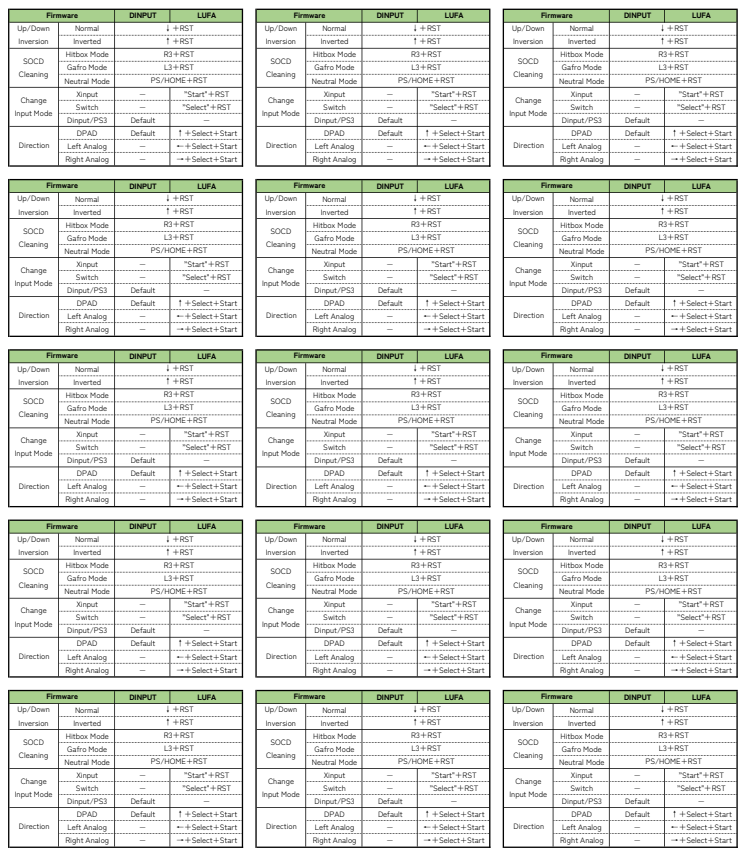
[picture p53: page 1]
DINPUT; LUFA; Normal; Inverted; Hitbox Mode; Gafro Mode; Neutral Mode; Xinput; ”Start"＋RST; Switch; ”Select"＋RST; Dinput/PS3; Default; DPAD; ↑＋Select+Start; Left Analog; ←＋Select+Start; Right Analog; →＋Select+Start; Change Input Mode; Direction; L3＋RST; PS/HOME+RST; ↓＋RST; ↑＋RST; SOCD Cleaning; R3＋RST; Firmware; Up/Down Inversion; Up/Down; Inversion; Firmware Up/Down Inversion; ↓＋RST ↑＋RST; R3＋RST L3＋RST PS/HOME+RST

R3＋RST
PS/HOME+RST

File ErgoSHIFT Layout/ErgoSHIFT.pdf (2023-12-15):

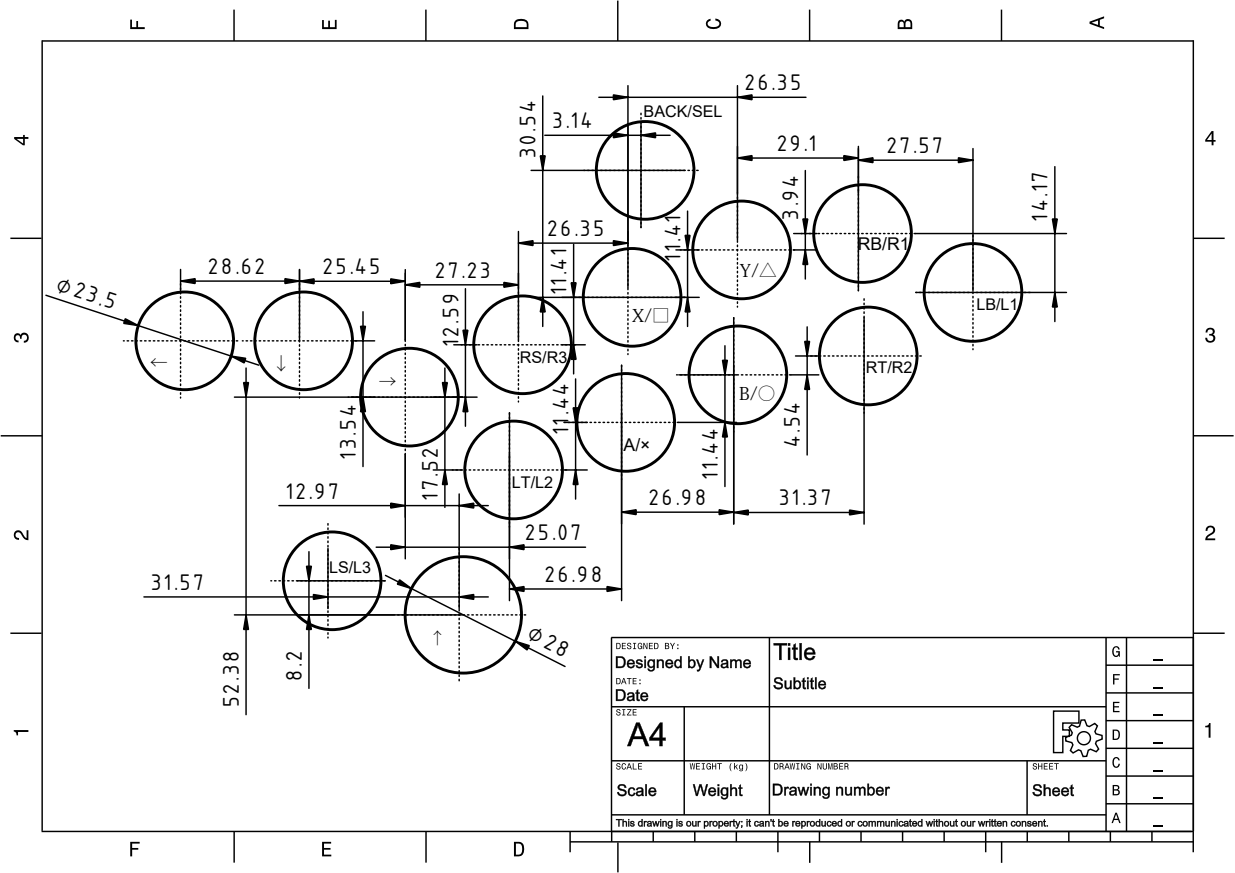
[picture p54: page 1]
BACK/SEL

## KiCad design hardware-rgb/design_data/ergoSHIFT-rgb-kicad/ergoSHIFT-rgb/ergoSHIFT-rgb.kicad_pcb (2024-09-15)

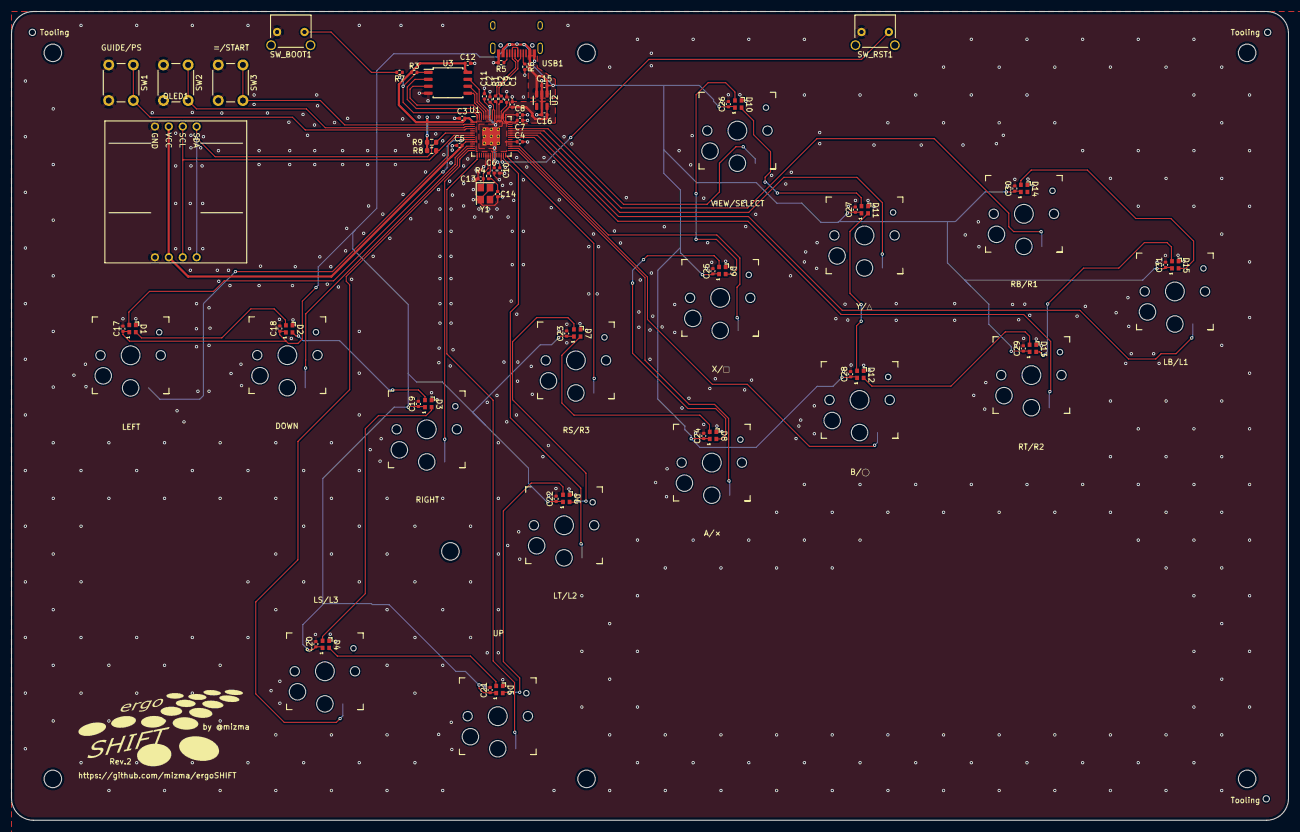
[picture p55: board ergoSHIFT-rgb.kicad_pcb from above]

Board: 2 copper layers, 233.2 x 147.7 mm, 84 parts (0 on the bottom side), 56 nets.

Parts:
C1, C9, C15, C16: 1u; C_0402_1005Metric
C2, C3, C4, C5, C6, C7, C8, C10, C11, C12: 100n; C_0402_1005Metric
C13, C14: 30p; C_0402_1005Metric
C17, C18, C19, C20, C21, C22, C23, C24, C25, C26, C27, C28, C29, C30, C31: 100nF; C_0402_1005Metric
D1, D2, D3, D4, D5, D6, D7, D8, D9, D10, D11, D12, D13, D14, D15: SK6812-EC20; LED_SK6812_EC20_2.0x2.0mm
OLED1: OLED_DISP_0.96inch_Reversible
R1, R2: 27; R_0402_1005Metric
R3: 10k; R_0402_1005Metric
R4, R7: 1k; R_0402_1005Metric
R5, R6: 5.1k; R_0402_1005Metric
R8, R9: 4.7k; R_0603_1608Metric
SW1, SW2, SW3: SW_Push; SW_PUSH_6mm_H8.5mm
SW4, SW5, SW6, SW7, SW8, SW9, SW10, SW11, SW12, SW13, SW14, SW15, SW16, SW17, SW18: SW_Push; Kailh_socket_PG1350
SW_BOOT1: SW_PUSH; SW_Tactile_Yushakobo 3x6x4.3mm
SW_RST1: SW_PUSH; SW_Tactile_Yushakobo 3x6x4.3mm
Tooling: JLCPCB_Tooling
Tooling#2, Tooling#3: JLCPCB_Tooling
U1: RP2040; RP2040-QFN-56
U2: TLV73333PDBV; SOT-23-5
U3: W25Q128JVS; SOIC-8_5.23x5.23mm_P1.27mm
USB1: HRO-TYPE-C-31-M-12; HRO-TYPE-C-31-M-12-Assembly
Y1: Crystal_GND24; Crystal_SMD_3225-4Pin_3.2x2.5mm

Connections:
+1V1: C9.1, C10.1, C11.1, U1.23 (DVDD), U1.45 (VREG_VOUT), U1.50 (DVDD)
+3V3: C1.1, C2.1, C3.1, C4.1, C5.1, C6.1, C7.1, C8.1, C12.1, C16.1, OLED1.2 (VCC), R3.1, R8.1, R9.2, U1.1 (IOVDD), U1.10 (IOVDD), U1.22 (IOVDD), U1.33 (IOVDD), U1.42 (IOVDD), U1.43 (ADC_AVDD), U1.44 (VREG_IN), U1.48 (USB_VDD), U1.49 (IOVDD), U2.5 (OUT), U3.8 (VCC)
+5V: C15.1, C17.1, C18.1, C19.1, C20.1, C21.1, C22.1, C23.1, C24.1, C25.1, C26.1, C27.1, C28.1, C29.1, C30.1, C31.1, D1.1 (VDD), D2.1 (VDD), D3.1 (VDD), D4.1 (VDD), D5.1 (VDD), D6.1 (VDD), D7.1 (VDD), D8.1 (VDD), D9.1 (VDD), D10.1 (VDD), D11.1 (VDD), D12.1 (VDD), D13.1 (VDD), D14.1 (VDD), D15.1 (VDD), U2.1 (IN), U2.3 (EN), USB1.2 (VBUS), USB1.11 (VBUS)
A: SW16.1, U1.29 (GPIO18)
B: SW17.1, U1.30 (GPIO19)
DOWN: SW5.1, U1.12 (GPIO9)
GND: C1.2, C2.2, C3.2, C4.2, C5.2, C6.2, C7.2, C8.2, C9.2, C10.2, C11.2, C12.2, C13.1, C14.2, C15.2, C16.2, C17.2, C18.2, C19.2, C20.2, C21.2, C22.2, C23.2, C24.2, C25.2, C26.2, C27.2, C28.2, C29.2, C30.2, C31.2, D1.3 (GND), D2.3 (GND), D3.3 (GND), D4.3 (GND), D5.3 (GND), D6.3 (GND), D7.3 (GND), D8.3 (GND), D9.3 (GND), D10.3 (GND), D11.3 (GND), D12.3 (GND), D13.3 (GND), D14.3 (GND), D15.3 (GND), OLED1.1 (GND), R5.2, R6.2, SW1.2, SW2.2, SW3.2, SW4.2, SW5.2, SW6.2, SW7.2, SW8.2, SW9.2, SW10.2, SW11.2, SW12.2, SW13.2, SW14.2, SW15.2, SW16.2, SW17.2, SW18.2, SW_BOOT1.1, SW_RST1.1, U1.19 (TESTEN), U1.57 (GND), U2.2 (GND), U3.4 (GND), USB1.1 (GND), USB1.12 (GND), Y1.2, Y1.4
HOME: SW1.1, U1.4 (GPIO2)
L1: SW13.1, U1.36 (GPIO24)
L2: SW15.1, U1.27 (GPIO16)
L3: SW7.1, U1.13 (GPIO10)
LEFT: SW4.1, U1.8 (GPIO6)
unnamed: C14.1, R4.1, Y1.3
unnamed: R7.2, SW_BOOT1.2
unnamed: SW_RST1.2, U1.26 (RUN)
unnamed: R2.2, U1.46 (USB_DM)
unnamed: R1.2, U1.47 (USB_DP)
unnamed: R6.1, USB1.4 (CC1)
unnamed: R5.1, USB1.10 (CC2)
OLED_SCL: OLED1.3 (SCL), R8.2, U1.7 (GPIO5)
OLED_SDA: OLED1.4 (SDA), R9.1, U1.6 (GPIO4)
OPT: SW2.1, U1.3 (GPIO1)
QSPI_SCLK: U1.52 (QSPI_SCLK), U3.6 (CLK)
QSPI_SD0: U1.53 (QSPI_SD0), U3.5 (DI(IO0))
QSPI_SD1: U1.55 (QSPI_SD1), U3.2 (DO(IO1))
QSPI_SD2: U1.54 (QSPI_SD2), U3.3 (IO2)
QSPI_SD3: U1.51 (QSPI_SD3), U3.7 (IO3)
QSPI_SS: R3.2, R7.1, U1.56 (QSPI_SS), U3.1 (~CS)
R1: SW12.1, U1.38 (GPIO26_ADC0)
R2: SW18.1, U1.35 (GPIO23)
R3: SW9.1, U1.28 (GPIO17)
RGB_DATA_A: D7.2 (DOUT), D8.4 (DIN)
RGB_DATA_B: D11.2 (DOUT), D12.4 (DIN)
RGB_DATA_DOWN: D1.2 (DOUT), D2.4 (DIN)
RGB_DATA_LB: D14.4 (DIN), D15.2 (DOUT)
RGB_DATA_LEFT: D1.4 (DIN), U1.9 (GPIO7)
RGB_DATA_LS: D3.2 (DOUT), D4.4 (DIN)
RGB_DATA_LT: D5.2 (DOUT), D6.4 (DIN)
RGB_DATA_RB: D13.2 (DOUT), D15.4 (DIN)
RGB_DATA_RIGHT: D2.2 (DOUT), D3.4 (DIN)
RGB_DATA_RS: D6.2 (DOUT), D7.4 (DIN)
RGB_DATA_RT: D12.2 (DOUT), D13.4 (DIN)
RGB_DATA_SEL: D9.2 (DOUT), D10.4 (DIN)
RGB_DATA_UP: D4.2 (DOUT), D5.4 (DIN)
RGB_DATA_X: D8.2 (DOUT), D9.4 (DIN)
RGB_DATA_Y: D10.2 (DOUT), D11.4 (DIN)
RIGHT: SW6.1, U1.14 (GPIO11)
SEL: SW14.1, U1.39 (GPIO27_ADC1)
START: SW3.1, U1.2 (GPIO0)
UP: SW8.1, U1.15 (GPIO12)
USB_DM: R2.1, USB1.5 (DN2), USB1.7 (DN1)
USB_DP: R1.1, USB1.6 (DP1), USB1.8 (DP2)
X: SW10.1, U1.31 (GPIO20)
XIN: C13.2, U1.20 (XIN), Y1.1
XOUT: R4.2, U1.21 (XOUT)
Y: SW11.1, U1.37 (GPIO25)

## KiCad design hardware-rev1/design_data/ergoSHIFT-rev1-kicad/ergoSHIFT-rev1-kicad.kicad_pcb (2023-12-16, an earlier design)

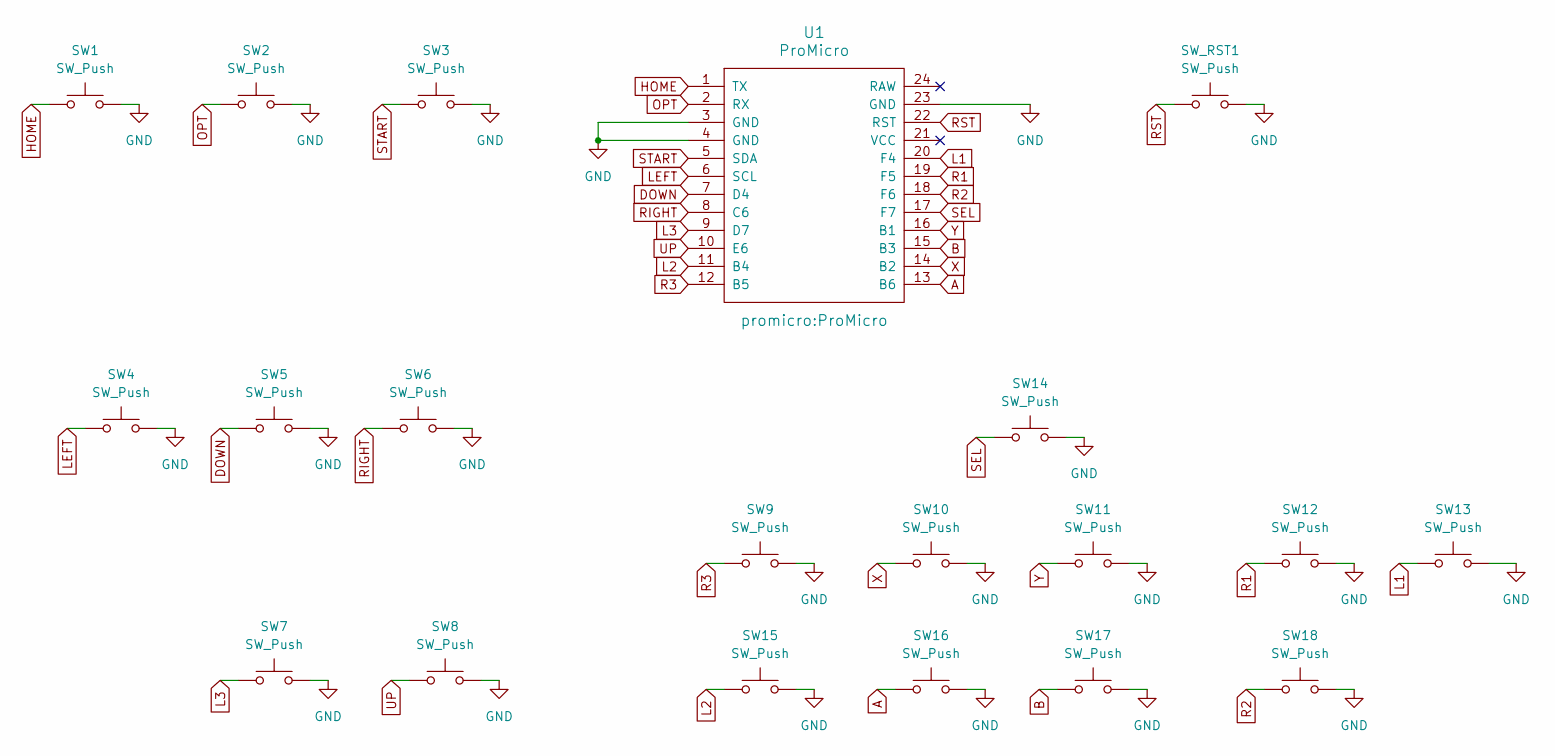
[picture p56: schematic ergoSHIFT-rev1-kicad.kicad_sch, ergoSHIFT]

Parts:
SW1, SW2, SW3: SW_Push; SW_PUSH_6mm_H8.5mm
SW4, SW5, SW6, SW7, SW8, SW9, SW10, SW11, SW12, SW13, SW14, SW15, SW16, SW17, SW18: SW_Push; Kailh_socket_MX_optional
SW_RST1: SW_Push; SW_Tactile_Yushakobo 3x6x4.3mm
U1: ProMicro

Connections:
A: SW16.1, U1.13 (B6)
B: SW17.1, U1.15 (B3)
DOWN: SW5.1, U1.7 (D4)
GND: SW1.2, SW2.2, SW3.2, SW4.2, SW5.2, SW6.2, SW7.2, SW8.2, SW9.2, SW10.2, SW11.2, SW12.2, SW13.2, SW14.2, SW15.2, SW16.2, SW17.2, SW18.2, SW_RST1.2, U1.3 (GND), U1.4 (GND), U1.23 (GND)
HOME: SW1.1, U1.1 (TX)
L1: SW13.1, U1.20 (F4)
L2: SW15.1, U1.11 (B4)
L3: SW7.1, U1.9 (D7)
LEFT: SW4.1, U1.6 (SCL)
OPT: SW2.1, U1.2 (RX)
R1: SW12.1, U1.19 (F5)
R2: SW18.1, U1.18 (F6)
R3: SW9.1, U1.12 (B5)
RIGHT: SW6.1, U1.8 (C6)
RST: SW_RST1.1, U1.22 (RST)
SEL: SW14.1, U1.17 (F7)
START: SW3.1, U1.5 (SDA)
UP: SW8.1, U1.10 (E6)
X: SW10.1, U1.14 (B2)
Y: SW11.1, U1.16 (B1)

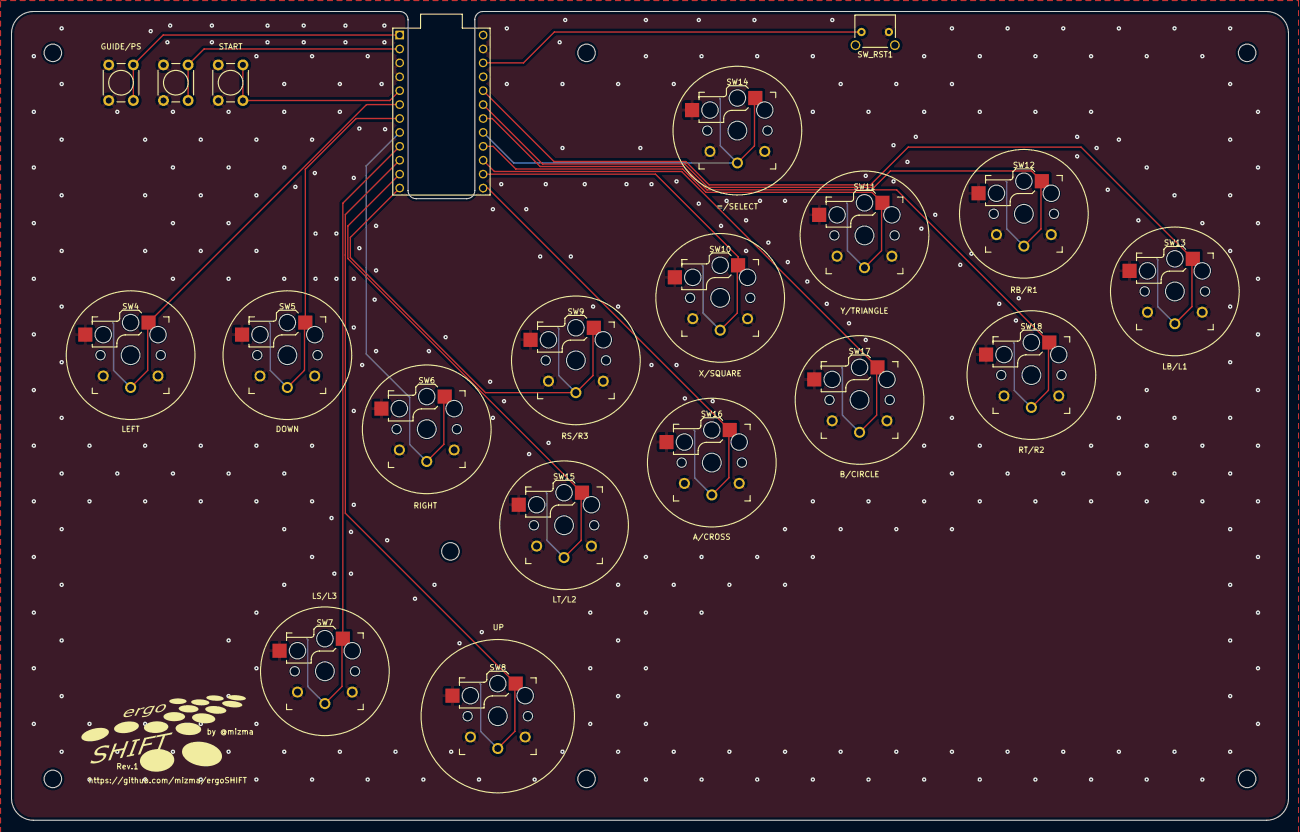
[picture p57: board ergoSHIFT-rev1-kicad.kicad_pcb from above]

Board: 2 copper layers, 233.2 x 147.7 mm, 20 parts (0 on the bottom side), 20 nets.

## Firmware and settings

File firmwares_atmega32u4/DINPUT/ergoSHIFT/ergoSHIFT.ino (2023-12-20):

// Jacek Fedorynski <jfedor@jfedor.org>
// http://www.jfedor.org/

#include "HID.h"
#include <EEPROM.h>

#define PIN_UP        7
#define PIN_DOWN      4
#define PIN_LEFT      3
#define PIN_RIGHT     5
#define PIN_CROSS     10
#define PIN_CIRCLE    14
#define PIN_TRIANGLE  15
#define PIN_SQUARE    16
#define PIN_L1        21
#define PIN_L2        8
#define PIN_R1        20
#define PIN_R2        19
#define PIN_SELECT    18
#define PIN_START     2
#define PIN_L3        6
#define PIN_R3        9
#define PIN_PS        1

int stickMode = 0; // 0 = dpad, 1 = left stick

// HID report descriptor taken from a HORI Fighting Stick V3
// works out of the box with PC and PS3
// as dumped by usbhid-dump and parsed by https://eleccelerator.com/usbdescreqparser/
static const uint8_t hidReportDescriptor[] PROGMEM = {
  0x05, 0x01,        // Usage Page (Generic Desktop Ctrls)
  0x09, 0x05,        // Usage (Game Pad)
  0xA1, 0x01,        // Collection (Application)
  0x85, 0x01,        // Report ID, not in the original descriptor, but the Arduino HID library can't seem to live without it
  0x15, 0x00,        //   Logical Minimum (0)
  0x25, 0x01,        //   Logical Maximum (1)
  0x35, 0x00,        //   Physical Minimum (0)
  0x45, 0x01,        //   Physical Maximum (1)
  0x75, 0x01,        //   Report Size (1)
  0x95, 0x0D,        //   Report Count (13)
  0x05, 0x09,        //   Usage Page (Button)
  0x19, 0x01,        //   Usage Minimum (0x01)
  0x29, 0x0D,        //   Usage Maximum (0x0D)
  0x81, 0x02,        //   Input (Data,Var,Abs,No Wrap,Linear,Preferred State,No Null Position)
  0x95, 0x03,        //   Report Count (3)
  0x81, 0x01,        //   Input (Const,Array,Abs,No Wrap,Linear,Preferred State,No Null Position)
  0x05, 0x01,        //   Usage Page (Generic Desktop Ctrls)
  0x25, 0x07,        //   Logical Maximum (7)
  0x46, 0x3B, 0x01,  //   Physical Maximum (315)
  0x75, 0x04,        //   Report Size (4)
  0x95, 0x01,        //   Report Count (1)
  0x65, 0x14,        //   Unit (System: English Rotation, Length: Centimeter)
  0x09, 0x39,        //   Usage (Hat switch)
  0x81, 0x42,        //   Input (Data,Var,Abs,No Wrap,Linear,Preferred State,Null State)
  0x65, 0x00,        //   Unit (None)
  0x95, 0x01,        //   Report Count (1)
  0x81, 0x01,        //   Input (Const,Array,Abs,No Wrap,Linear,Preferred State,No Null Position)
  0x26, 0xFF, 0x00,  //   Logical Maximum (255)
  0x46, 0xFF, 0x00,  //   Physical Maximum (255)
  0x09, 0x30,        //   Usage (X)
  0x09, 0x31,        //   Usage (Y)
  0x09, 0x32,        //   Usage (Z)
  0x09, 0x35,        //   Usage (Rz)
  0x75, 0x08,        //   Report Size (8)
  0x95, 0x04,        //   Report Count (4)
  0x81, 0x02,        //   Input (Data,Var,Abs,No Wrap,Linear,Preferred State,No Null Position)
  0x06, 0x00, 0xFF,  //   Usage Page (Vendor Defined 0xFF00)
  0x09, 0x20,        //   Usage (0x20)
  0x09, 0x21,        //   Usage (0x21)
  0x09, 0x22,        //   Usage (0x22)
  0x09, 0x23,        //   Usage (0x23)
  0x09, 0x24,        //   Usage (0x24)
  0x09, 0x25,        //   Usage (0x25)
  0x09, 0x26,        //   Usage (0x26)
  0x09, 0x27,        //   Usage (0x27)
  0x09, 0x28,        //   Usage (0x28)
  0x09, 0x29,        //   Usage (0x29)
  0x09, 0x2A,        //   Usage (0x2A)
  0x09, 0x2B,        //   Usage (0x2B)
  0x95, 0x0C,        //   Report Count (12)
  0x81, 0x02,        //   Input (Data,Var,Abs,No Wrap,Linear,Preferred State,No Null Position)
  0x0A, 0x21, 0x26,  //   Usage (0x2621)
  0x95, 0x08,        //   Report Count (8)
  0xB1, 0x02,        //   Feature (Data,Var,Abs,No Wrap,Linear,Preferred State,No Null Position,Non-volatile)
  0x0A, 0x21, 0x26,  //   Usage (0x2621)
  0x91, 0x02,        //   Output (Data,Var,Abs,No Wrap,Linear,Preferred State,No Null Position,Non-volatile)
  0x26, 0xFF, 0x03,  //   Logical Maximum (1023)
  0x46, 0xFF, 0x03,  //   Physical Maximum (1023)
  0x09, 0x2C,        //   Usage (0x2C)
  0x09, 0x2D,        //   Usage (0x2D)
  0x09, 0x2E,        //   Usage (0x2E)
  0x09, 0x2F,        //   Usage (0x2F)
  0x75, 0x10,        //   Report Size (16)
  0x95, 0x04,        //   Report Count (4)
  0x81, 0x02,        //   Input (Data,Var,Abs,No Wrap,Linear,Preferred State,No Null Position)
  0xC0,              // End Collection
};

typedef struct {
  uint16_t buttons; // bits: 0 = square, 1 = cross, 2 = circle, 3 = triangle,
                    // 4 = L1, 5 = R1, 6 = L2, 7 = R2, 8 = select, 9 = start,
                    // 10 = L3, 11 = R3, 12 = PS
  uint8_t dpadHat; // 0 = up, 1 = up/right, 2 = right etc., 0x0f = neutral
  uint8_t leftStickXAxis;
  uint8_t leftStickYAxis;
  uint8_t rightStickXAxis;
  uint8_t rightStickYAxis;
  uint8_t dpadRightAxis;
  uint8_t dpadLeftAxis;
  uint8_t dpadUpAxis;
  uint8_t dpadDownAxis;
  uint8_t triangleAxis;
  uint8_t circleAxis;
  uint8_t crossAxis;
  uint8_t squareAxis;
  uint8_t L1Axis;
  uint8_t L2Axis;
  uint8_t R1Axis;
  uint8_t R2Axis;
  uint16_t accelerometerXAxis; // 10 bits (these are guesses BTW)
  uint16_t accelerometerYAxis; // 10 bits
  uint16_t accelerometerZAxis; // 10 bits
  uint16_t gyroscopeAxis; // 10 bits
} hid_report_t;

hid_report_t report;
hid_report_t prevReport;
bool prevLeft;
bool prevRight;

typedef enum {
  HITBOX,   // UP&DOWN=UP, LEFT&RIGHT=NEUTRAL
  GAFRO,    // UP&DOWN=UP, LEFT&RIGHT=Last Input Wins
  NEUTRAL   // UP&DOWN=NEUTRAL, LEFT&RIGHT=NEUTRAL
} Socd_t;
Socd_t socd;

typedef enum {
  CMIDDLE_DOWN,     // Middle input is DOWN (Hitbox style)
  CMIDDLE_UP        // Middle input is UP (for normal arcade style)
} CardMiddle_t;
CardMiddle_t cmiddle;

void dpad_vinvert(bool, bool, bool, bool);
void dpad(bool, bool, bool, bool);

void (*dpad_p)(bool, bool, bool, bool);

void dpad_vinvert(bool up, bool down, bool left, bool right) {
  dpad(down, up, left, right);
}

void dpad(bool up, bool down, bool left, bool right) {
  if (up && down) {
    if (socd == NEUTRAL) {
      up = down = false; // neutral
    } else {
      down = false;   // Up always wins in Hitbox
    }
  }
  if (left && right) {
    if (socd == HITBOX || socd == NEUTRAL) {
      // SOCD cleaner: Hitbox (neutral in horizontal input)
      left = right = false;
    } else {
      // SOCD cleaner: Gafro (last input wins in horizontal input)
      if (prevLeft || prevRight) {
        // last one wins. (Not allowed in official tournaments)
        left = !prevLeft;
        right = !prevRight;
      } else {
        // If both came at the exact same time, keep neutral
        left = right = false;
      }
    }
  } else {
    prevLeft = left;
    prevRight = right;
  }

  switch (stickMode) {
    case 0:
      if (up && !right && !left) report.dpadHat = 0;
      else if (up && right) report.dpadHat = 1;
      else if (right && !up && !down) report.dpadHat = 2;
      else if (right && down) report.dpadHat = 3;
      else if (down && !right && !left) report.dpadHat = 4;
      else if (down && left) report.dpadHat = 5;
      else if (left && !down && !up) report.dpadHat = 6;
      else if (left && up) report.dpadHat = 7;
      else report.dpadHat = 0x0f;

      report.dpadRightAxis = right ? 0xff : 0x00;
      report.dpadLeftAxis = left ? 0xff : 0x00;
      report.dpadUpAxis = up ? 0xff : 0x00;
      report.dpadDownAxis = down ? 0xff : 0x00;
      break;
    case 1:
      report.leftStickXAxis = left ? 0x00 : (right ? 0xFF : 0x80);
      report.leftStickYAxis = up ? 0x00 : (down ? 0xFF : 0x80);
      break;
  }
}

void sendReport() {
  if (memcmp(&prevReport, &report, sizeof(report))) {
    HID().SendReport(1, &report, sizeof(report));
    memcpy(&prevReport, &report, sizeof(report));
  }
}

void setup() {
  static HIDSubDescriptor node(hidReportDescriptor, sizeof(hidReportDescriptor));
  bool updateSOCD = false;
  bool updateCMiddle = false;
  HID().AppendDescriptor(&node);

  pinMode(PIN_UP, INPUT_PULLUP);
  pinMode(PIN_DOWN, INPUT_PULLUP);
  pinMode(PIN_LEFT, INPUT_PULLUP);
  pinMode(PIN_RIGHT, INPUT_PULLUP);
  pinMode(PIN_CROSS, INPUT_PULLUP);
  pinMode(PIN_CIRCLE, INPUT_PULLUP);
  pinMode(PIN_TRIANGLE, INPUT_PULLUP);
  pinMode(PIN_SQUARE, INPUT_PULLUP);
  pinMode(PIN_L1, INPUT_PULLUP);
  pinMode(PIN_L2, INPUT_PULLUP);
  pinMode(PIN_R1, INPUT_PULLUP);
  pinMode(PIN_R2, INPUT_PULLUP);
  pinMode(PIN_SELECT, INPUT_PULLUP);
  pinMode(PIN_START, INPUT_PULLUP);
  pinMode(PIN_L3, INPUT_PULLUP);
  pinMode(PIN_R3, INPUT_PULLUP);
  pinMode(PIN_PS, INPUT_PULLUP);
  
  delay(500);

  // if LEFT is held when plugged in, switch to left stick emulation mode
  if (digitalRead(PIN_LEFT) == LOW) {
    stickMode = 1;
  }

  memset(&report, 0, sizeof(report));
  report.dpadHat = 0x0f;
  report.accelerometerXAxis = 0x02; // not sure why 0x02, but that's what HORI Fighting Stick V3 sends
  report.accelerometerYAxis = 0x02;
  report.accelerometerZAxis = 0x02;
  report.gyroscopeAxis = 0x02;
  report.leftStickXAxis = 0x80;
  report.leftStickYAxis = 0x80;
  report.rightStickXAxis = 0x80;
  report.rightStickYAxis = 0x80;
  memcpy(&prevReport, &report, sizeof(report));
  prevLeft = prevRight = false;

  // Read SOCD setting from EEPROM
  EEPROM.get(0, socd);

  if (socd != HITBOX && socd != GAFRO && socd != NEUTRAL) {
    // Initialize EEPROM
    socd = HITBOX;
    updateSOCD = true;
  }

  if (digitalRead(PIN_PS) == LOW) {
    // If PS is pressed, change to socd to NEUTRAL
    if (socd != NEUTRAL) {
      socd = NEUTRAL;
      updateSOCD = true;
    }
  }
  if (digitalRead(PIN_L3) == LOW) {
    // If L3 is pressed, change to socd to GAFRO
    if (socd != GAFRO) {
      socd = GAFRO;
      updateSOCD = true;
    }
  }
  if (digitalRead(PIN_R3) == LOW) {
    // If R3 is pressed, change to socd to HITBOX
    // If both are pressed, Hitbox setting wins
    if (socd != HITBOX) {
      socd = HITBOX;
      updateSOCD = true;
    }
  }

  if (updateSOCD) {
    // Update EEPROM data
    EEPROM.put(0, socd);
  }

  // Default is middle button = down.
  dpad_p = dpad;

  EEPROM.get(2, cmiddle);

  if (cmiddle != CMIDDLE_DOWN && cmiddle != CMIDDLE_UP) {
    // Initialize to Hitbox style if EEPROM is not initialized
    cmiddle = CMIDDLE_DOWN;
    updateCMiddle = true;
  }

  if (digitalRead(PIN_UP) == LOW) {
    // set to standard arcade style setup
    if  (cmiddle != CMIDDLE_UP) {
      cmiddle = CMIDDLE_UP;
      updateCMiddle = true;
    }
  }
  if (digitalRead(PIN_DOWN) == LOW) {
    // set to standard Hitbox style setup
    if  (cmiddle != CMIDDLE_DOWN) {
      cmiddle = CMIDDLE_DOWN;
      updateCMiddle = true;
    }
  }

  if (updateCMiddle) {
    EEPROM.put(2, cmiddle);
  }

  if (cmiddle == CMIDDLE_UP) {
    // if CMIDDLE_UP is set, re-point the dpad_p pointer to an invert function
    dpad_p = dpad_vinvert;
  }
}

void loop() {
  report.buttons = 0x00;
  report.triangleAxis = 0x00;
  report.circleAxis = 0x00;
  report.crossAxis = 0x00;
  report.squareAxis = 0x00;
  report.L1Axis = 0x00;
  report.L2Axis = 0x00;
  report.R1Axis = 0x00;
  report.R2Axis = 0x00;

  dpad_p(digitalRead(PIN_UP) == LOW,
       digitalRead(PIN_DOWN) == LOW,
       digitalRead(PIN_LEFT) == LOW,
       digitalRead(PIN_RIGHT) == LOW);

  if (digitalRead(PIN_SQUARE) == LOW) {
    report.buttons |= 1 << 0;
    report.squareAxis = 0xff;
  }
  if (digitalRead(PIN_CROSS) == LOW) {
    report.buttons |= 1 << 1;
    report.crossAxis = 0xff;
  }
  if (digitalRead(PIN_CIRCLE) == LOW) {
    report.buttons |= 1 << 2;
    report.circleAxis = 0xff;
  }
  if (digitalRead(PIN_TRIANGLE) == LOW) {
    report.buttons |= 1 << 3;
    report.triangleAxis = 0xff;
  }
  if (digitalRead(PIN_L1) == LOW) {
    report.buttons |= 1 << 4;
    report.L1Axis = 0xff;
  }
  if (digitalRead(PIN_R1) == LOW) {
    report.buttons |= 1 << 5;
    report.R1Axis = 0xff;
  }
  if (digitalRead(PIN_L2) == LOW) {
    report.buttons |= 1 << 6;
    report.L2Axis = 0xff;
  }
  if (digitalRead(PIN_R2) == LOW) {
    report.buttons |= 1 << 7;
    report.R2Axis = 0xff;
  }
  if (digitalRead(PIN_SELECT) == LOW) {
    report.buttons |= 1 << 8;
  }
  if (digitalRead(PIN_START) == LOW) {
    report.buttons |= 1 << 9;
  }
  if (digitalRead(PIN_L3) == LOW) {
    report.buttons |= 1 << 10;
  }
  if (digitalRead(PIN_R3) == LOW) {
    report.buttons |= 1 << 11;
  }
  if (digitalRead(PIN_PS) == LOW) {
    report.buttons |= 1 << 12;
  }

  sendReport();
}

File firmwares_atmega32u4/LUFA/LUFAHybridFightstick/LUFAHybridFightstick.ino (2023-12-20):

#include "LUFAConfig.h"
#include <LUFA.h>
#include "XS_HID.h"
#define BOUNCE_WITH_PROMPT_DETECTION
#include <Bounce2.h>
#include <EEPROM.h>
#include <inttypes.h>

/* in case you want to disable one type of gamepad */
//#define DISABLE_NSWITCH
//#define DISABLE_XINPUT

#define SOCD_CONFIG

/* PINOUT (follows Nintendo naming (X=up, B=down)) */
#define PIN_UP    7
#define PIN_DOWN  4
#define PIN_LEFT  3
#define PIN_RIGHT 5
#define PIN_A     MISO         //XBOX B
#define PIN_B     10           //XBOX A  
#define PIN_X     15           //XBOX Y
#define PIN_Y     MOSI         //XBOX X     
#define PIN_L     21           //XBOX LB
#define PIN_R     20           //XBOX RB
#define PIN_ZL    8            //XBOX LT
#define PIN_ZR    19           //XBOX RT
#define PIN_LS    6            //XBOX LS (left analog click)
#define PIN_RS    9            //XBOX RS (right analog click)
#define PIN_PLUS  2            //XBOX START
#define PIN_MINUS 18           //XBOX BACK
#define PIN_HOME  1

/* Buttons declarations */
#define MILLIDEBOUNCE 1 //Debounce time in milliseconds
unsigned long startAndSelTime = 0;
unsigned long currTime = 0;

byte internalButtonStatus[4];

Bounce joystickUP = Bounce();
Bounce joystickDOWN = Bounce();
Bounce joystickLEFT = Bounce();
Bounce joystickRIGHT = Bounce();
Bounce buttonA = Bounce();
Bounce buttonB = Bounce();
Bounce buttonX = Bounce();
Bounce buttonY = Bounce();
Bounce buttonL = Bounce();
Bounce buttonR = Bounce();
Bounce buttonZL = Bounce();
Bounce buttonZR = Bounce();
Bounce buttonLS = Bounce();
Bounce buttonRS = Bounce();
Bounce buttonPLUS = Bounce();
Bounce buttonMINUS = Bounce();
Bounce buttonHOME = Bounce();

/* MODE DECLARATIONS */
typedef enum {
  RIGHT_ANALOG_MODE,
  ANALOG_MODE,
  DIGITAL,
} State_t;
State_t state;

typedef enum {
  NEUTRAL,    // LEFT/UP + DOWN/RIGHT = NEUTRAL
  NEGATIVE,   // LEFT/UP beats DOWN/RIGHT
  POSITIVE,   // DOWN/RIGHT beats LEFT/UP
  LAST_INPUT, //Last input has priority; not a valid state if being used for initial_input
} Socd_t;
Socd_t x_socd_type = NEUTRAL; // controls left/right and up/down resolution type
Socd_t y_socd_type = NEGATIVE;
Socd_t x_initial_input, y_initial_input = NEUTRAL;

typedef enum {
  CVERT_NORMAL,     // Middle input is DOWN (Hitbox style)
  CVERT_INVERT        // Middle input is UP (for normal arcade style)
} CardVert_t;
CardVert_t cvert;

/* mode selectors */
bool xinput;
bool modeChanged;

void checkModeChange() {
  if (buttonStatus[BUTTONSTART] && buttonStatus[BUTTONSELECT])
  {
    if ( !modeChanged )
    {
      State_t last_state;

      last_state = state; 

      if (internalButtonStatus[BUTTONLEFT])
        state = ANALOG_MODE;
      else if (internalButtonStatus[BUTTONRIGHT])
        state = RIGHT_ANALOG_MODE;
      else if (internalButtonStatus[BUTTONUP])
        state = DIGITAL;

      if (last_state != state) EEPROM.put(0, state);
      modeChanged = true;
    }
    else
    {
      modeChanged = false;
    }
  }
}

void setupPins() {
  if (cvert == CVERT_INVERT) {
    // Inverted Up/Down input
    joystickUP.attach(PIN_DOWN, INPUT_PULLUP);
    joystickDOWN.attach(PIN_UP, INPUT_PULLUP);
  } else { // CVERT_NORMAL (Default)
    joystickUP.attach(PIN_UP, INPUT_PULLUP);
    joystickDOWN.attach(PIN_DOWN, INPUT_PULLUP);
  }
  joystickLEFT.attach(PIN_LEFT, INPUT_PULLUP);
  joystickRIGHT.attach(PIN_RIGHT, INPUT_PULLUP);
  buttonA.attach(PIN_A, INPUT_PULLUP);     // XBOX B
  buttonB.attach(PIN_B, INPUT_PULLUP);     // XBOX A
  buttonX.attach(PIN_X, INPUT_PULLUP);     // XBOX Y
  buttonY.attach(PIN_Y, INPUT_PULLUP);    // XBOX X
  buttonL.attach(PIN_L, INPUT_PULLUP);    // XBOX LB
  buttonR.attach(PIN_R, INPUT_PULLUP);     // XBOX RB
  buttonZL.attach(PIN_ZL, INPUT_PULLUP);    // XBOX LT
  buttonZR.attach(PIN_ZR, INPUT_PULLUP);    // XBOX RT
  buttonLS.attach(PIN_LS, INPUT_PULLUP);       // XBOX LS
  buttonRS.attach(PIN_RS, INPUT_PULLUP);       // XBOX RS
  buttonPLUS.attach(PIN_PLUS, INPUT_PULLUP);   // XBOX START
  buttonMINUS.attach(PIN_MINUS, INPUT_PULLUP); // XBOX BACK
  buttonHOME.attach(PIN_HOME, INPUT_PULLUP);

  joystickUP.interval(MILLIDEBOUNCE);
  joystickDOWN.interval(MILLIDEBOUNCE);
  joystickLEFT.interval(MILLIDEBOUNCE);
  joystickRIGHT.interval(MILLIDEBOUNCE);
  buttonA.interval(MILLIDEBOUNCE);
  buttonB.interval(MILLIDEBOUNCE);
  buttonX.interval(MILLIDEBOUNCE);
  buttonY.interval(MILLIDEBOUNCE);
  buttonL.interval(MILLIDEBOUNCE);
  buttonR.interval(MILLIDEBOUNCE);
  buttonZL.interval(MILLIDEBOUNCE);
  buttonZR.interval(MILLIDEBOUNCE);
  buttonLS.interval(MILLIDEBOUNCE);
  buttonRS.interval(MILLIDEBOUNCE);
  buttonPLUS.interval(MILLIDEBOUNCE);
  buttonMINUS.interval(MILLIDEBOUNCE);
  buttonHOME.interval(MILLIDEBOUNCE);
}

void setup() {

  bool updateCVert = false;
  modeChanged = false;
  EEPROM.get(0, state);
  EEPROM.get(2, xinput);
#ifdef SOCD_CONFIG
  EEPROM.get(4, x_socd_type);
  EEPROM.get(6, y_socd_type);
#endif

  // setup cardinal middle button settings
  EEPROM.get(8, cvert);

  if (cvert != CVERT_NORMAL && cvert != CVERT_INVERT) {
    // Initialize to Hitbox style if EEPROM is not initialized
    cvert = CVERT_NORMAL;
    updateCVert = true;
  }

  if (digitalRead(PIN_UP) == LOW) {
    // set to standard arcade style setup
    if  (cvert != CVERT_INVERT) {
      cvert = CVERT_INVERT;
      updateCVert = true;
    }
  }
  if (digitalRead(PIN_DOWN) == LOW) {
    // set to standard Hitbox style setup
    if  (cvert != CVERT_NORMAL) {
      cvert = CVERT_NORMAL;
      updateCVert = true;
    }
  }

  if (updateCVert) {
    EEPROM.put(8, cvert);
  }

  setupPins();
  delay(500);

#ifdef DISABLE_NSWITCH
#warning "NSWITCH mode is disabled, will act only as an XInput controller"
  /* force Xinput */
  xinput = true;
#else
#ifdef DISABLE_XINPUT
#warning "XINPUT mode is disabled, will act only as a Nintendo switch controller"
  /* force nswitch */
  xinput = false;
#else
  /* set xinput mode according to held button */
  // if select is held on boot, NSWitch mode
  bool xinput_current = xinput;
  int value = digitalRead(PIN_MINUS);
  if (value == LOW)
  {
    xinput = false;
  }
  // if start is held on boot, XInput mode
  else {
    value = digitalRead(PIN_PLUS);
    if (value == LOW)
    {
      xinput = true;
    }
  }
  if (xinput_current != xinput) {
    // Update if changed
    EEPROM.put(2, xinput);
  }
#endif
#endif

  // TODO: add setting for inverting Up/Down
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

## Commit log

2023-12-15 Initial commit with Acryl design data and button layout design sketch
    [ErgoSHIFT.FCStd, acryl-design.FCStd]
2023-12-16 acryl stackup data upload
    [acryl-design-ergoSHIFT-Acrylic-layer-01.dxf, acryl-design-ergoSHIFT-Acrylic-layer-02.dxf, acryl-design-ergoSHIFT-Acrylic-layer-03.dxf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]
2023-12-16 package acryl cut data for sending to Elecrow. Added design stencil image
    [acryl-design.FCStd]
2023-12-16 initial design complete for Acryl and PCB
    [acryl-design.FCStd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]
2023-12-16 Add Readme for Top directory. add Firmware files (button mappings not fixed)
    [LUFAHybridFightstick.ino]
2023-12-16 add switch schematics
2023-12-16 added referenced footprint library
2023-12-16 fixed issue with PCB coordinate origin settings. fixed stencil being too light.
    [ergoSHIFT-rev1-kicad-B_Cu.gbl, ergoSHIFT-rev1-kicad-B_Mask.gbs, ergoSHIFT-rev1-kicad-B_Paste.gbp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]
2023-12-20 Fix stencil icons for view and menu button for xbox style button icons
2023-12-20 Fix firmware pin assign for ergoSHIFT circuit design
    [LUFAHybridFightstick.ino]
2023-12-20 Fix readme for the firmwares.
    [ergoSHIFT.ino]
2023-12-20 Switch Licenses.
2023-12-23 add initial implementation for rev2
    [acryl-design-ergoSHIFT-Acrylic-layer-01.dxf, acryl-design-ergoSHIFT-Acrylic-layer-02.dxf, acryl-design-ergoSHIFT-Acrylic-layer-03.dxf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]
2023-12-24 updated stencil with logo. added circuit schematics for rev2
2024-01-05 update Readme for rev2 hardware.
    [ergoSHIFT-rev2-kicad.kicad_pcb, ergoSHIFT-rev2-kicad.kicad_sch]
2024-01-06 Fix Acrylic layer 1 thickness designation on data files
    [acryl-design.FCStd]
2024-01-06 Initial design upload for 3D Printable Caps
    [ergoSHIFT-ButtonCap.FCStd, ergoSHIFT-ButtonCap.stl, ergoSHIFT-ButtonCapBig.FCStd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]
2024-01-06 Updated documents for Rev2 build instructions and a few firmware related descriptions.
    Fix config file default pin mapping
2024-01-08 Cleanup technical drawing for acrylic layer and pcb
    [acryl-design.FCStd]
2024-01-08 remove unnecessary dimention on layer 02 drawing
    [acryl-design.FCStd]
2024-01-12 Update PCBA instruction
2024-01-13 update button cap design.
    * adjust leg size. too large for MJF PA12W print.
    * adjust diameter of main buttons for better clearance
    * adjest wall height of main buttons to avoid conflict with switch assy
    [ergoSHIFT-ButtonCap.FCStd, ergoSHIFT-ButtonCap.stl, ergoSHIFT-ButtonCapBig.FCStd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]
2024-01-19 update pre-built binary to 0.7.7 and update config related files for pin mapping to the 0.7.7 format.
2024-01-19 3D button caps now confirmed to work
2024-01-28 add image and readme to 3d printed caps + southpaw build
2024-02-04 update button cap leg size.
    button cap legs seems to get larger on MJF prints. setting the legs to be almost equal size with the kailh choc v1 switch drawing dimensions
    [ergoSHIFT-ButtonCap.FCStd, ergoSHIFT-ButtonCap.stl, ergoSHIFT-ButtonCapBig.FCStd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]
2024-05-18 update documentation for OLED soldering instruction to avoid issues.
2024-05-20 adding memo to point to the current pre-built firmware sourcecode.
2024-09-15 RGB LED Revision (#13)
    * added RGB LED design
    * removed cost info, unnecessary
    * added images and README file
    * Update README.md
    * rotated image
    * removing image
    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
    [ergoSHIFT-rgb-BOM.csv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]
2024-10-07 Updated LED config image to set proper order for LEDs (#16)
    * switched R1/L1 to reflect correct LED order
    added ? to image url to force image update
    ---------
    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
